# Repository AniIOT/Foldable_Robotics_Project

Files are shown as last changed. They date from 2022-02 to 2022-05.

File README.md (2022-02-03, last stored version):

# Foldable_Robotics_Project

# Add all documents to the appropriate sub-folders in Foldable_Robotics_Project\01_Documents\
# e.g. Research papers will be added in Foldable_Robotics_Project\Documents\02_Research_Papers\

# Add all code files in sub-folders titled with your name in Foldable_Robotics_Project\04_Software\
# e.g. xyz should put their code in Foldable_Robotics_Project\04_Software\##_xyz\

# Final merged code will be kept in Foldable_Robotics_Project\04_Software\04_Release\

# Add all electronic hardware related files in the appropriate sub-folders in Foldable_Robotics_Project\03_Hardware\
# e.g. Component list for Power supply will be in Foldable_Robotics_Project\03_Hardware\01_Components\##_Power_Supply\##_Components\

# Final electronic hardware gerber files will be added in Foldable_Robotics_Project\03_Hardware\03_Release\

# Add all mechanical related files in Foldable_Robotics_Project\02_Mechanical\
# e.g. Chasis CAD files will be in Foldable_Robotics_Project\02_Mechanical\##_Chasis\##_CAD\

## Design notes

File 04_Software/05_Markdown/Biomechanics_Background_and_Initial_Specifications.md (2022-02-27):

## Biomechanics Background and Initial Specifications
### Bryan Carlton1, Aniruddha Anand Damle1, Anson Kwan1, Jacob Yoshitake1
### Team 2: Swimming
### 1Ira A. Fulton Schools of Engineering

### I. Bio Inspiration

The organism that we will draw inspiration from for our research question and system are eels.
Eels exhibit a form of undulatory motion called 
anguilliform locomotion which propagates
waves along their spines [1]. The five most
relevant sources about eels and fish based
undulatory motion are as follows:

I. Hydrodynamics of undulatory
propulsion [1]*
II. Muscles, elastic energy, and the
dynamics of body stiffness in swimming
eels [2]*
III. The hydrodynamics of Eel Swimming
[3]
IV. The hydrodynamics of eel swimming II.
effect of swimming speed [4]*
V. Interactions between internal forces,
body stiffness, and fluid environment in
a neuromechanical model of lamprey
swimming [5]

Of these sources, we will discuss I, II, and IV
since they are the most relevant to our research
question.

Hydrodynamics of undulatory propulsion
discusses the history of existing work conducted
on different forms of undulating locomotion and
propulsion [1]. This is particularly helpful for
our research question because it provides
context and basis of knowledge as we start to
explore anguilliform locomotion. Additionally,
from this paper, we are able to extract critical
information about the gait cycle and time
duration of a single oscillation for eels.
Muscles, elastic energy, and the dynamics of
body stiffness in swimming eels analyzes the
kinematic and dynamic properties of eels to
derive generalized values regarding muscle
activation, work, and stiffness along the body of
eels [2]. This research is pertinent to our
research discussion because it gives us
information regarding how to link kinematic
properties of eels to the foldable system that we
are interested in developing. The most relevant
values include the weight, length, and body
cross sectional area. These values are important
to deriving the linear velocity of eels as well as
provide a method of comparing these elements
of our device against an eel.
The hydrodynamics of eel swimming II. Effect of
swimming speed discusses the kinematics and
hydrodynamics of eels but goes into further
detail regarding dynamic conditions that eels
swim under [4]. Through the method of using
two synchronized high speed cameras, the
researchers were able to calculate frequency,
wave speed, velocities of the system, and jet
speeds produced by the eels [2]. This
information is valuable to us because it allows
us to approximate the linear velocity of eels as
well as the power needed to sustain this form of
locomotion. We are then able to specify the
requirements needed for a servo motor to power
our system.

### II. Other bio-inspired robots

Although the team has already decided on an eel
inspired design, it is also important to look at
other similar designs and other sources of
biological sources. Below are five different
sources that detail different bio-inspired robots.
I. Kinematic Evaluation of a Series of Soft
Actuators in Designing and Eel-inspired
Robot [6]*
II. How the Body Contributes to The Wake
in Undulatory Fish Swimming: Flow
Fields of a Swimming Eel [7]*
III. Thrust generation during Steady
Swimming and Acceleration from Rest
in Anguilliform Swimmers [8]
IV. Development and Motion Control of
Biomimetic Underwater Robots: A
Survey [9]
V. Flow patterns of Larval fish: Undulatory
Swimming in the Intermediate Flow
Regime [10]*
Kinematic Evaluation of a Series of Soft
Actuators in Designing and Eel-inspired Robot
This paper discusses the motion generated
through soft actuators in an eel inspired robot
[6]. Despite this being a soft robot, it provides an
in depth analysis and data on the locomotion of
an eel like robot design. As well this paper
provides information on the manufacturing of
their actuator which can guide the team's design.
How the Body Contributes to The Wake in
Undulatory Fish Swimming: Flow Fields of a
Swimming Eel
This paper discusses the body mechanics, and
how that affects the thrust of the robot [7]. This
paper provides the kinematics of an eel like
robot. It also provides helpful analysis of the
undulatory movement that eels and similar fish
use to move through water
Flow patterns of Larval fish: Undulatory
Swimming in the Intermediate Flow Regime
This paper focuses on fish larvae designs, and
the forces between the body of the larvae and the
water [10]. This paper provides helpful force
analysis between water and submerged
undulatory robots. Having these force
interactions helps the team understand how the
water affects movement and stabilization of the
robot system.

### III. Table

| Parameter | Unit | Value Range | Reference |
| Length | m | .024-.033| [2] |
| Weight | kg | 0.037-0.057 | [2] |
| Frequency | Hz | 1.3 +/- 0.10 | [4] |
| Wave Speed | L/s | 0.39 +/- 0.02 | [4] | 
| Slip | L/L | 0.784 +/-0.002 | [4] | 
| Max Area | 𝑚2 | 0.0001018 | [2] | 
| Gait Time | s | 0.26 | [1] | 

### IV. Other Assumptions

Using the data that was found in Table 1, we can
now calculate the velocity and energy consumed
for anguilliform motion. The slip ratio is defined
as the swimming speed of the body (U) over the
wave speed (V).
𝑆𝑙𝑖𝑝 = 𝑈 (1)
𝑉
From equation 1, we were able to calculate the
body speed to be 0.3058 or . In order to find 𝐿
𝑠
the linear speed, we first had to convert the flow
rate to and got a value of 𝑚3
𝑠 3. 058 × 10−4
. Then using the volumetric flow equation: 𝑚3
𝑠
𝑄 = 𝐴 𝑣 (2)
where Q is the volumetric flow, A is the cross
sectional area, and v is the linear velocity. Using
equation 2, we get a linear velocity of 3.003 . 𝑚
𝑠
From this we can now deduce the approximate
energy and power used during the gait cycle.
Using the kinetic energy formula:
𝐾𝐸 = 1 (3)
2 𝑚𝑣2
Where KE is the kinetic energy, m is the mass,
and v is the velocity. We calculated the kinetic
energy as 0.213 Joules. With this we can now
calculate the approximate power consumption of
the gait since we know both the energy and
duration of the gait cycle. Using the power
equation:
𝑃 = 𝑊 (4)
Δ𝑡
where P is power, W is work or energy, and Δ𝑡 is
the change in time, we are able to calculate the
power of a single gait phase of anguilliform
locomotion is 0.819 W.

### V. Figures



Figure 1. Four main categories of fish
undulatory motion. The top figures denote the
phases of a single gait phase and the lower
visualize the midline movement of each motion
[1].



Figure 2. Flow of water generated from eel
motion. Red represents clockwise motion and
blue represents counter clockwise flow [3].

### VI. Engineering Representation



Figure 3. Engineering representation of
proposed system

As seen in Fig 3 the proposed system will
consist of twelve rigid links connected through
eleven joints which will be acting as the
torsional spring in the system. All the links will
be represented with their own respective masses
so in order to properly model the dynamics of
this system, inertias will need to be included for
all twelve links. The main actuator for this
system will be a servo input on the first link
(farthest left on Fig 3). This servo will be run
using position control so that we can tune and
control the maximum and minimum position of
the output shaft.

### VII. Discussion

#### Discuss / defend your rationale for the size animal you selected.
We selected the eel as inspiration for our
research question because anguilliform
locomotion is one of the few undulatory motions
that only requires a singular input for the entire
system. Traditional fish locomotion has multiple
fins in conjunction with an oscillatory motion.
This would require additional pieces and
increased complexity in order to create an
aquatic robot. By gaining inspiration from eels
and understanding how to precisely tune a
segmented spine, it is possible to create
locomotion through a single motorized actuator.
This would greatly reduce the cost and
complexity of the system and allow us the
flexibility to replicate or draw inspiration from
anguilliform locomotion by simply tuning the
joint stiffness.

#### Find a motor and battery that can supply the mechanical power needs obtained above.
From section IV, we calculated that the total
power of the gait cycle is 0.819 Watts. Using
this and the weight of an eel from Table 1, we
calculated a power/weight ratio of 16.38 W/kg.
Using this information, we selected two
perspective servo motors for our system. The
first choice is the SG90 Micro Servo Motor[11]
due to its low cost, light weight and relatively
high power output. However, it does not appear
to be waterproof, so additional measures will
need to be taken to ensure that it does not
succumb to water damage. On the other end, the
WEISE DS3218 Servo Motor[12] is heavier, but
has much higher power output and is
waterproof. Though it is more expensive and
heavier, the waterproofing is much appreciated
and the higher torque allows the system more
power to operate in the water. We will purchase
the SG90 initially, and if the robot needs more
torque or there are problems with water damage,
the DS3218 will be purchased as a replacement.
For a battery, a Blomiky 6V 2200mAh
battery[13] will be able to operate either of the
servos and meet power requirements. This will
be encased in a waterproof housing along with
the microcontroller to reduce chance of water
damage.

### VIII. Bibliography
#### [1] G. V. Lauder and E. D. Tytell, “Hydrodynamics of undulatory propulsion,” Fish Physiology, pp. 425–468, 2005.
#### [2] J. Long, “Muscles, elastic energy, and the dynamics of body stiffness in swimming eels,” American Zoologist, vol. 38, no. 4, pp. 771–792, 1998.
#### [3] E. D. Tytell and G. V. Lauder, “The hydrodynamics of Eel Swimming,” Journal of Experimental Biology, vol. 207, no. 11, pp. 1825–1841, 2004.
#### [4] E. D. Tytell, “The hydrodynamics of EEL swimming II. effect of swimming speed,” Journal of Experimental Biology, vol. 207, no. 19, pp. 3265–3279, 2004.
#### [5] E. D. Tytell, C.-Y. Hsu, T. L. Williams, A. H. Cohen, and L. J. Fauci, “Interactions between internal forces, body stiffness, and fluid environment in a neuromechanical model of lamprey swimming,” Proceedings of the National Academy of Sciences, vol. 107, no. 46, pp. 19832–19837, 2010.
#### [6] D. Q. Nguyen and V. A. Ho, “Kinematic Evaluation of a Series of Soft Actuators in Designing and Eel-inspired Robot.” International Symposium, Honolulu, 12-Jan-2020.
#### [7]K. T. Du Clos and J. O. Dabiri, “Thrust generation during steady swimming and acceleration from rest in anguilliform swimmers.” The Company of Biologists Ltd, 2019.
#### [8] R. Wang and Y. Wang, “Development and Motion Control of Biomimetic Underwater Robots: A Survey.” Carleton University.
#### [9]U. K. Müller and J. Smit, “How the body contributes to the wake in undulatory fish swimming.” University of Groningen, 2001. 
#### [10] U. K. Müller and J. van den Boogaart and Johan, “Flow patterns of larval fish: undulatory swimming in the intermediate flow regime.” The Company of Biologists, 2008.
#### [11] “2Pack SG90 Micro Servo Motor Mini Servo SG90 9g Servo Kit for RC Helicopter Airplane Car Boat Robot Arm/Hand/Walking/Servo Door Lock Control with Cable,” Amazon. [Online]. Available: https://www.amazon.com/Sipytoph-Helicopter-Airplane-Walking-Control/dp/B09185SC1W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. [Accessed: 13-Feb-2022].
#### [12] “Blomiky 6V 2200mAh Ni-MH 5 AA Rechargeable Battery Pack with SM-2P Black 2 Pin Connector Plug and USB Charger Cable for RC Truck Cars Vehicles 6V NiMh,” Amazon. [Online]. Available: https://www.amazon.com/Blomiky-2200mAh-Rechargeable-Battery-Vehicles/dp/B07PY8R3F4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. [Accessed: 13-Feb-2022].
#### [13] “WEISE DS3218 Control Angle 180 High Torque Update Servo 20KG Full Metal Gear Digital Servo Baja Servo Waterproof Servo Mechanical arm Fittings RC Baja Cars,” Amazon. [Online]. Available: https://www.amazon.com/WEISE-Control-Waterproof-Mechanical-Fittings/dp/B073M3X86S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. [Accessed: 13-Feb-2022].

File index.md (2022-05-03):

---
title: Foldable Robotics Project
---

# Project Title: Tuned constrained beam inspired by anguilliform locomotion

**Team 2**

| Name | Email | Phone |
| --- | --- | --- |
| Aniruddha Anand Damle | adamle5@asu.edu | (602) 813-7594  |
| Jacob Yoshitake | jyoshita@asu.edu | (858) 231-4114  |
| Anson Kwan | akwan2@asu.edu | (626) 512-2444  |
| Bryan Carlton | bhcarlto@asu.edu | (480)-677-8602  |

## Research Question 

* [Develop A Research Question](/04_Software/05_Markdown/Develop_A_Research_Question.md)

* [Biomechanics Background and Initial Specifications](/04_Software/05_Markdown//Biomechanics_Background_and_Initial_Specifications.md)

* [System Kinematics](/04_Software/05_Markdown/SystemKinematics.md)

* [Presentation 1](/04_Software/05_Markdown/Presentation_1.md)

* [System Dynamics](/04_Software/05_Markdown/SystemDynamics.md)

* [Presentation 2](/04_Software/05_Markdown/Presentation_2.md)

* [Design Optimization, Experiment Design, Data Collection, and Analysis](/04_Software/05_Markdown/Design_Optimization_Experiment_Design_Data_Collection_and_Analysis.md)

* [Presentation 3](/04_Software/05_Markdown/Presentation_3.md)

* [Manufacturing](/04_Software/05_Markdown/Manufacturing.md)

* [Data](/04_Software/05_Markdown/Data.md)

* [Gallery](/04_Software/05_Markdown/Gallery.md)

## Background
We wanted to know how a length-constrained segmented beam with a compliant tail could propagate a sinusoidal wave to produce anguilliform locomotion in this project. Our team members come from various experiences and provide a variety of perspectives to the project. This project aims to replicate the motion of an eel's tail and enhance the velocity of a similar robot that has already been built. We also want to reduce production costs by employing foldable methods.



## Results
 - This project has helped  to further research into aquatic foldable robots
 - It also helped to contribute to the understanding of undulating aquatic animals
 - To further progress our research, main things to improve would be to
   - Properly scale up the prototype
   - Test it in a free swim
   - Continue research on the gates of undulating aquatic animals
 - The outputs of our parameter optimization are as follows
   - Segment Volume - length=27.6mm height=10mm
   - Tail Length = 10mm
   - Sweep Frequency - 2.13Hz 
   - Constraint Link Length - 151.8 mm
  


## Conclusions and Future Work
In the future, there are a couple of improvements that we would like to make.  The first would be to see if it is possible to convert the stiff spine into a foldable part.  The current design uses a 3D printed spine to provide a rigid structure that the two pivot points and the motor mounts to.  To replace this, a future team could look into creating a laminate structure that doubles up the current tail thickness to obtain an ideal thickness.  Second, making the system free-floating and designing it around the weight of the actuator would change how the system was optimized.  The current optimization is focused on just the tail without the weight of the motor or any support structure, and the weight of the actuator is too much for the current design to propel.  Optimizing the tail with the weight of the motor would definitely change the dimensions of the design.  Finally, the shape of the tail could be optimized.  For our system, we kept the tail a rectangular shape to make simulation much easier.  However, a more optimized tail might be able to handle producing more thrust that could be used for propulsion.

## References
[1] G. V. Lauder and E. D. Tytell, “Hydrodynamics of undulatory propulsion,” Fish Physiology, pp. 425–468, 2005.<br>
[2] J. Long, “Muscles, elastic energy, and the dynamics of body stiffness in swimming eels,” American Zoologist, vol. 38, no. 4, pp. 771–792, 1998. <br>
[3] E. D. Tytell and G. V. Lauder, “The hydrodynamics of Eel Swimming,” Journal of Experimental Biology, vol. 207, no. 11, pp. 1825–1841, 2004. <br>
[4] E. D. Tytell, “The hydrodynamics of EEL swimming II. effect of swimming speed,” Journal of Experimental Biology, vol. 207, no. 19, pp. 3265–3279, 2004.<br> 
[5] E. D. Tytell, C.-Y. Hsu, T. L. Williams, A. H. Cohen, and L. J. Fauci, “Interactions between internal forces, body stiffness, and fluid environment in a neuromechanical model of lamprey swimming,” Proceedings of the National Academy of Sciences, vol. 107, no. 46, pp. 19832–19837, 2010. <br>
[6] D. Q. Nguyen and V. A. Ho, “Kinematic Evaluation of a Series of Soft Actuators in Designing and Eel-inspired Robot.” International Symposium, Honolulu, 12-Jan-2020.<br>
[7]K. T. Du Clos and J. O. Dabiri, “Thrust generation during steady swimming and acceleration from rest in anguilliform swimmers.” The Company of Biologists Ltd, 2019.

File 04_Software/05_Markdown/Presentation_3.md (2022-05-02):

# Presentation 3:

<iframe width="560" height="315" src="https://www.youtube.com/embed/5slSRJoQ57w" title="YouTube video player" frameborder="0" allow="accelerometer; autoplay; clipboard-write; encrypted-media; gyroscope; picture-in-picture" allowfullscreen></iframe>

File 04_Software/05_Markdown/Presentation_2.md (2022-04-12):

# Presentation: 

<iframe width="560" height="315" src="https://www.youtube.com/embed/j1TpFOJFzOI" title="YouTube video player" frameborder="0" allow="accelerometer; autoplay; clipboard-write; encrypted-media; gyroscope; picture-in-picture" allowfullscreen></iframe>

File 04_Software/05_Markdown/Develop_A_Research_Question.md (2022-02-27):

# EGR 557 Foldable Robotics
## Develop A Research Question
## Team 2
### Bryan Carlton1, Aniruddha Anand Damle1, Anson Kwan1, Jacob Yoshitake1
### 1Ira A. Fulton Schools of Engineering

### I. Question
How can a length-constrained segmented beam with a compliant tail propagate a sinusoidal wave to produce anguilliform locomotion?

### II. Tractability
In order to make this project tractable within the time frame of 15 weeks, we will be focusing on tuning our segmented beam to produce motion inspired by anguilliform locomotion or ‘eel-like’ swimming. Additionally, we will be focusing on only trying to tune one position for the segmented beam. This means that we will be only focusing on optimizing the joint stiffness for the mechanism for only one configuration of the system. For the purposes of this project, we will be starting in an ‘S’ configuration and try to flip the peaks of the stable position through a simple input of a servo motor. This will greatly improve the scope of this research because it defines the goal of the research as producing this configuration as opposed to finding the optimal configuration to produce this locomotion. By focusing our research on anguilliform locomotion and defining the configuration that we will use, the scope of the research will produce successful results for this semester.

### III. Novelty
For the purposes of understanding the various research spaces that anguilliform locomotion-based robots exist, we used keywords such as ‘anguilliform locomotion’, ‘undulatory motion’, ‘soft robotics’, ‘laminate’, and ‘eel inspired’. From these keywords, we were able to get an understanding of the existing research being conducted on anguilliform-inspired robots within the foldable robotics field.
From these keywords, the most cited source was “A Geometric Approach to Anguilliform Locomotion: Modeling of an Underwater Eel Robot” [1]. This paper discusses the kinematics and simplification of anguilliform locomotion into rigid body segments and defined points of rotation [1]. This paper primarily focuses on using rigid bodies and actuation at every link. Unlike this paper, our research question will be focusing on creating undulations in the body of our system through only a single actuation and tuning our system to propagate the motion. The next most cited source was “Bio-inspired aquatic robotics by untethered piezohydroelastic actuation’ [2]. This journal entry discussed the tuning and utilization of piezoelectric laminates to produce the sinusoidal locomotion that characterizes many underwater movements [2]. Both this paper and our research questions discuss the concepts of single actuated, tunable laminate structures, but this paper focuses on carangiform locomotion which is exhibited in fish. Additionally, this paper uses
the laminate structure as the form of actuation, while our question focuses on a method of
propagating a tuned laminate structure that produces anguilliform-like locomotion. The third most
relevant and cited source was “AmphiBot I: An amphibious snake-like robot” [3]. The core
concept of this paper revolves around a wheeled multi-actuated spine that can either traverse land
or water through snake-like or eel-like locomotion [3]. This paper represents how anguilliform
locomotion can be accomplished using traditional actuators and linkages. Our question differs
entirely from this paper because our objective is to produce this kind of movement using only a
singular actuator and a precisely tuned mechanical system. Lastly, the other paper that was most
cited for these keywords were “Body wave generation for anguilliform locomotion using a fiberreinforced
soft fluidic elastomer actuator array toward the development of the EEL-inspired
Underwater Soft Robot” [4]. This journal article focused on utilizing bellows-based actuators to
inflate faces of a soft spine in order to create the curvatures present in eels to create a simplified
model and robot [4]. While both this research paper and our question revolve around simplifying
the traditionally complex systems that generate anguilliform locomotion, this is achieved in
different ways. The goal of our research is to use a single traditional actuator, such as a servo, to
produce this locomotion, while this paper focuses on using multiple pneumatic bellows to deform
the spine.

### IV. Interesting
With the development of newer and faster manufacturing methods, as well as various materials
such as ionic polymer-metal composites (IPMCs), Shape memory alloys (SMAs), and
magnetostrictive thin films, the development of bioinspired soft-robot locomotion has received a
lot of attention and has recently been the topic of discussion between the scientific communities.
The scientific and engineering communities have expressed a strong interest in applying biological
underwater locomotion to marine robots in order to improve performance in various marine
missions such as search and rescue, naval intelligence, and surveillance and reconnaissance. The
motivation for eel-like biometric locomotion ranges from underwater sensing and exploration for
long-term ecological sustainability to drug delivery and disease screening in medicine.

### V. Open-Ended
In addition to our research question, there are a slew of other questions that could be asked. From
the way that we defined and structured our research question, our primary focus is anguiliform
locomotion and tuning for a single starting configuration. This means that there is an opportunity
to conduct more research on optimizing the initial configuration for anguilliform locomotion or
adapting the mechanism for different forms of aquatic locomotion as well as terrestrial locomotion.
Additionally, even within the scope of our question, there is potential to do a deeper look into
optimizing a tail or compliant attachment to propagate the motion produced from the mechanism.
Our research question's goal is to start looking into the possibilities for this mechanism, which is
just a starting point for a variety of applications and dynamics that can be used with this system.

### VI. Modularity
Our question can be applied to a wide range of research topics such as biomimicry, laminate
robotics, aquatic propulsion, and unmanned surface vehicles (USV). Because we are focusing on
inspired locomotion from eels, biologists can compare locomotion behaviors of eels with the
device we develop. Through that research, it is possible for new or additional correlations could
be drawn from this comparison. Research in laminate robotics can further develop this mechanism
to be applied to multiple different environments or be use the data from tuning joint stiffness with
the experimental material for future mechanisms. For researchers interested in aquatic propulsion,
studies could be conducted in simulating and testing the fluid dynamics of the mechanism in
relation to correlating fluid environments that produce the best results. USV are an up-and-coming
field of research that focus mainly on producing devices and mechanisms that can be controlled
remotely in variable viscous fluids and land. Through our research, future work can be done on
developing and controlling this mechanism so that it can be applied to this field. There may be
other applications of our research to other topics, but these three are the most prominent that we
could recognize.

### VII. Team Fit
Our team members have a variety of interests and abilities that will be necessary to this research.
Anson Kwan is currently conducting research on simulating and analyzing soft beams to produce
anguilliform locomotion and has an interest in crossing over the concept of singular actuation to
create complex motion into laminate systems. He has experience with python-based simulation as
well as using optimization algorithms such as SciPy and CMA-ES to solve and fit complex
dynamic systems. Through this research question, he hopes to learn more about laminate structures
and how they apply to anguilliform locomotion and how joint design in laminate design affects
stiffness and compliance
Jacob Yoshitake has a variety of skills based in 3D modeling and manufacturing. His extensive
experience with SolidWorks will allow the team to be able to create 3D models of the robot at a
rapid pace, as well as simulate it though either SolidWorks or ANSYS. He also understands a
wide variety of manufacturing techniques (3D printing, laser cutting, welding, milling, lathe, etc.)
as well as a wealth of experience manufacturing mechanisms that will be paramount to being able
to produce a working robot. Though his interests are mostly in aerospace, the research into
propulsion of an aquatic robot also interests him.
Bryan Carlton is currently working on a research project in which he is working on another
bioinspired design. With this research question, he hopes to learn how to apply biological concepts
to robotics in order to provide simpler, effective solutions whether it be in exoskeleton
development or an underwater vehicle. This project allows Bryan to research simpler solutions for
underwater locomotion while learning new robotic methods. He currently has experience with
CAD softwares such as Fusion 360 and Solidworks. He has also worked with electrical design
software Cadence. Bryan also has experience in programming languages such as C/C++,
MATLAB/Simulink, and a little bit of Python.
Aniruddha Anand Damle is interested in creating a low-cost mechanism that can be used for
terrestrial robots. He has a strong background in embedded systems, machine learning, and
communication protocols, allowing us to quickly develop functional prototypes. He's also worked
with 3D modeling and production techniques like 3D printing, laser cutting, and lathes. He has
previously worked on multi-layered PCB design and development, as well as various ARM-based
platforms. Although his interest is in Swarm Robotics, he hopes to develop a low-cost muscle
design that can be used to build an origami-inspired quadruped robot with this research question.

### VIII. Topic Fit
For this research to be successful, it will be utilizing the techniques of analysis of geometric
kinematics, dynamics, and laminate manufacturing processes for our device that will be taught
over this course. In order to determine the joint stiffnesses of the segmented beam, we will need
to conduct experimental data and fit the simulated data to it. To achieve this, we will have to solve
for the kinematics of the system as well as simulate the dynamics of the model to find the joint
characteristics. Additionally, in order to find the optimal joint stiffness to match our desired
dynamics and starting configuration, we will need to solve for the dynamics of the system which
is a major topic of this course. Finally, the segmented beam will be manufactured using foldable
robotics processes. Foldable techniques are critical to answering this question because it allows
for the flexibility of easily experimenting with a number of joints and links using inexpensive
materials and low manufacturing time. Since varying the stiffness of joints is just a relationship to
how much material is removed between the joints and there is a multitude of configurations for
how to design the joints, foldable techniques are an ideal solution to prototype our device.

### IX. Bibliography
#### [1] K. A. Melsaac and J. P. Ostrowski, “A geometric approach to anguilliform locomotion:
#### Modelling of an underwater Eel Robot,” Proceedings 1999 IEEE International Conference on
#### Robotics and Automation (Cat. No.99CH36288C), pp. 2843–2848, May 1999.
#### [2] L. Cen and A. Erturk, “Bio-inspired Aquatic Robotics by untethered piezohydroelastic
#### actuation,” Bioinspiration & Biomimetics, vol. 8, no. 1, p. 016006, 2013.
#### [3] A. Crespi, A. Badertscher, A. Guignard, and A. J. Ijspeert, “Amphibot I: An amphibious
#### snake-like robot,” Robotics and Autonomous Systems, vol. 50, no. 4, pp. 163–175, 2005.
#### [4] H. Feng, Y. Sun, P. A. Todd, and H. P. Lee, “Body wave generation for anguilliform
#### locomotion using a fiber-reinforced soft fluidic elastomer actuator array toward the development
#### of the EEL-inspired Underwater Soft Robot,” Soft Robotics, vol. 7, no. 2, pp. 233–250, 2020.

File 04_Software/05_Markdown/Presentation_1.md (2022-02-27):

# Presentation:
<iframe width="560" height="315" src="https://www.youtube.com/embed/J2_oT60I6jE" title="YouTube video player" frameborder="0" allow="accelerometer; autoplay; clipboard-write; encrypted-media; gyroscope; picture-in-picture" allowfullscreen></iframe>

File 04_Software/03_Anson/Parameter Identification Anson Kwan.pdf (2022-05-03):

4/12/22, 9:33 PM | Parameter Identification Anson Kwan
file:///C:/Users/aakwa/Desktop/Parameter Identification Anson Kwan.html | 1/9

# Goal of Experiment

The goal of my experiment is to run a dynamic test of the decided joint material of polyethelyene sheet. From this experiment we hope to fit the data for the damping and stiffness constant.

# Process and Procedure

### Process

In order to isolate the joint properties, I manufactured a 2 link, 5-layer laminate structure with 0.002" polyester film as the flexible layer and 6 layer cardstock as the rigid material. I then conducted a

### dynamic test by constraining one of the links vertically between two plates and pulled

unconstrained link to the side, released and let it come to rest. I recorded this experiment with my phone so that I could import the data into tracker, track the position of the blue dot at the end of my segment, and record the position data over time. This data was then imported into python so that I could fit the data to a simulated experiment.

The assumptions I made for this experiment is that the system is exactly vertical. Since I am in a configuration that is meant to negate gravity, but if there was any warping or if the links were not exactly vertical, some forces due to gravity would have an effect. Additionally, I am treating the rigid segments as rigid bodies have no flexure for my model.

### Pictures of Experimental Setup

Set up of experiment from above. One link is constrained allowing only one segment to move.

Side profile of experimental set up. A small blue ball was added to the end of the link to track the motion of the segment as it oscilatted.

### Video

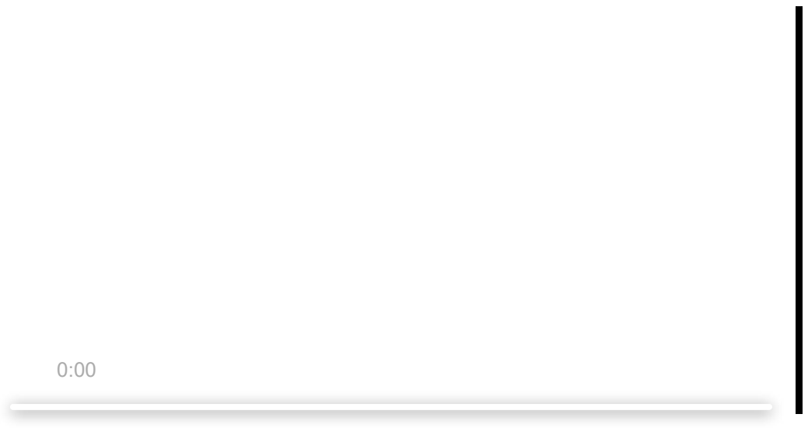
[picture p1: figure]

file:///C:/Users/aakwa/Desktop/Parameter Identification Anson Kwan.html | 2/9

Video of experiment that was used for tracker.

# Model Fitting

The model I used to fit for this experiment was a single link that had a torsional spring and damping force applied to the point of rotation. The reason that the model was built like this is because only one link in the experiment had free motion and the cause of motion was the felxure joint.

The optimization method used for my assignment was the scipy.optimize.minimze function. The reason that this method was used was because I was trying to tune the b and k values of the model to best fit the experimental data. Since there was no relationship between these variables, I went with the fastest method of fitting the data. For the purposes of this assignment, the script will not run the fitting to decrease the amount of outputs but the values of the damping and spring constant are calculated from the the optimization.

# Importing Libraries

### Adding libaries to build dynamic model and fitting algorithms

In [1]:
%matplotlib inline

In [2]:
import pynamics
from pynamics.frame import Frame
from pynamics.variable_types import Differentiable,Constant from pynamics.system import System
from pynamics.body import Body
from pynamics.dyadic import Dyadic
from pynamics.output import Output,PointsOutput from pynamics.output_points_3d import PointsOutput3D from pynamics.particle import Particle
import pynamics.integration

file:///C:/Users/aakwa/Desktop/Parameter Identification Anson Kwan.html | 3/9

# Running Optimization and Importing Data

Setting variable to True to run fit or false to just run a single simulation. Importing the xlsx file of exerimental data and plot the data. The data was cut at two seconds to focus on the dynamics of the system and to optimize the simulation time so that it would run faster.

Text(0, 0.5, 'Position (mm)')

import numpy
import matplotlib.pyplot as plt plt.ion()
from math import pi,sin
import sympy
from sympy import sqrt
import math
import logging
import pynamics.integration import pynamics.system
import numpy.random
import scipy.interpolate
import scipy.optimize
import cma
import pandas as pd
import idealab_tools.units

system = System()
pynamics.set_system(__name__,system)

In [3]:
#Run SciPy Opitmization regession fit

run_fit = False

#import test data and convert to numPy arrays data = pd.read_excel(r'damping data_cut.xlsx') df = data.to_numpy()

length = df.shape[0]

fig = plt.figure()
plt.plot(df[:,1],df[:,3])
plt.title('Experimental Data From Tracker') plt.xlabel('Time (s)')
plt.ylabel('Position (mm)')

Out[3]:

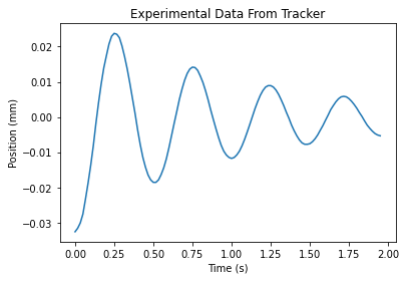
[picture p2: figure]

file:///C:/Users/aakwa/Desktop/Parameter Identification Anson Kwan.html | 4/9

# Constants of Model

### Adding dimensions and interias of segment based off of physical laminate structure. Link dimensions were 50mm x 30 mm x 1 mm. Mass of the tracker was 0.0588 grams and mass of the segment was 1 gram. These values were gotten from teammates from their parameterization

documents.

In [4]:
#Parameterization

#Defining Constants of System seg_len = 0.050 #segment mass seg_mass = 0.001 #segment mass seg_h = 0.040 #segment height seg_th = 0.001

#Set segment lengths

lA = Constant(seg_len,'lA',system) lB = Constant(seg_len,'lB',system)

#Set masses

mA = Constant(seg_mass,'mA',system)
mB = Constant(seg_mass,'mB',system)
mM = Constant(.001/17,'mM',system) #17 trackers was 1 gram so divided to find mass of t

g = Constant(9.81,'g',system)
b = Constant(2.14176688e-06,'b',system) #values generated fro sciPy.minimize
k = Constant(1.59953557e-04,'k',system) #values generated fro sciPy.minimize
area = Constant(seg_len*seg_h,'area',system)
rho = Constant(1.059,'rho',system)

Ixx = Constant((1/12*seg_mass*(seg_h**2 + seg_th**2)),'Ixx',system)
Iyy = Constant((1/12*seg_mass*(seg_h**2 + seg_len**2)),'Iyy',system) Izz = Constant((1/12*seg_mass*(seg_len**2 + seg_th**2)),'Izz',system)

#Define derivatives of frames

qA,qA_d,qA_dd = Differentiable('qA',system)

#set initial conditions

file:///C:/Users/aakwa/Desktop/Parameter Identification Anson Kwan.html | 5/9

# Kinematics of Model

Adding kinematics of syste. Adding the body of the link and a particle mass of the tracker to the end of the segment.

# Adding Force

Forces were added to the model. Gravity, Aerodynamic against flat plate, spring force and damping force.

initialvalues = {}
initialvalues[qA]=-41*pi/180 #Initial state of experiment initialvalues[qA_d]=0*pi/180

statevariables = system.get_state_variables()
ini = [initialvalues[item] for item in statevariables]

#Set simulation run time

tinitial = 0
tfinal = df[length-1,1] #time of simulation to match time of experiment fps = length/tfinal
tstep = 1/fps
t = numpy.r_[tinitial:tfinal:tstep]

In [5]:
#Kinematics

#Frames

N = Frame('N',system)
A = Frame('A',system)

system.set_newtonian(N)

A.rotate_fixed_axis(N,[0,0,1],qA,system)

#Vectors

pNA=0*N.x
pAB=pNA+lA*A.x

#Centers of Mass

pAcm=pNA+lA/2*A.x
pMcm=pNA+lA*A.x

#Angular Velocity

wNA = N.get_w_to(A)

#Velocity of Center of Mass vA=pAcm.time_derivative()

#Interia and Bodys

IA = Dyadic.build(A,Ixx,Iyy,Izz)

BodyA = Body('BodyA',A,pAcm,mA,IA,system)
BodyM = Particle(pMcm,mM,'ParticleM',system) #Mass of blue dot tracker

file:///C:/Users/aakwa/Desktop/Parameter Identification Anson Kwan.html | 6/9

<pynamics.force.Force at 0x260b29ca250>

# Building Model

Solve for the equations of motion and run the opitimization algorithm if run_fit was set to true

In [6]:
#Forces

#Gravity

system.addforcegravity(-g*N.z)

#Aerodynamic Forces

f_aero_A = rho * vA.length()*(vA.dot(A.y))*area*A.y system.addforce(-f_aero_A,vA)

#Spring Forces

system.add_spring_force1(k, (qA)*N.z, wNA)

#Damping Force

system.addforce(-b*wNA, wNA)

# Out[6]: In [7]:

#Constraints and Plots

f,ma = system.getdynamics();

tol = 1e-12
points = [pNA,pAB]

def run_sim(args):
constants = dict([(key,value) for key,value in zip(unknown_constants,args)]) states=pynamics.integration.integrate(func1,ini,t,rtol=tol,atol=tol,hmin=tol, args= return states

def calc_error(args):
states_guess = run_sim(args)
points_output = PointsOutput(points,system) y_guess = points_output.calc(states_guess,t) error = df[:,3] - y_guess[:,1,1]
error **=2
error = error.sum()
return error

pynamics.system.logger.setLevel(logging.ERROR)

if run_fit:

unknown_constants = [b,k]

known_constants = list(set(system.constant_values.keys())-set(unknown_constants)) known_constants = dict([(key,system.constant_values[key]) for key in known_constant

func1,lambda1 = system.state_space_post_invert(f,ma,return_lambda = True,constants

guess = [3e-6,2.17e-4]

file:///C:/Users/aakwa/Desktop/Parameter Identification Anson Kwan.html | 7/9

2022-04-12 21:12:24,585 - pynamics.system - INFO - getting dynamic equations

# Plots of Results

Plotting the results of the simulated tip of the simulation against the experimental tip.

pynamics.system.logger.setLevel(logging.ERROR)

sol = scipy.optimize.minimize(calc_error,guess) print(sol.fun)
result = sol.x

error_f = calc_error(result)

In [16]:
if run_fit:
states2 = run_sim(result)
points_output2 = PointsOutput(points,system) y2 = points_output2.calc(states2,t)

fig = plt.figure()
ax1 = plt.subplot(2,1,2)
ax1.plot(t,states2[:,:1])
ax1.legend(['qA'])
ax1.set_title('State Positions') ax1.set_xlabel('Time (s)') ax1.set_ylabel('Position (mm)')

ax2 = plt.subplot(2,1,1)
ax2.plot(t,y2[:,1,1],df[:,1],df[:,3]) ax2.legend(['pBtip_s' ,'pBtip_a']) ax2.set_title('Test vs CMA Tip') ax2.set_xlabel('Time (s)') ax2.set_ylabel('Position (mm)')

fig.tight_layout()

print(result)
print(error_f)

else:

func1 = system.state_space_post_invert(f,ma,return_lambda = False) states=pynamics.integration.integrate(func1,ini,t,rtol=tol,atol=tol,hmin=tol, args=

points_output = PointsOutput(points,system)
y = points_output.calc(states,t)

fig = plt.figure(figsize=(8, 6), dpi=80)

ax1 = plt.subplot(3,1,1)
ax1.plot(t,states[:,:1])
ax1.legend(['qA'])
ax1.set_title('State Positions') ax1.set_xlabel('Time (s)') ax1.set_ylabel('Position (mm)') ax1.set_ylim([-1, 1])

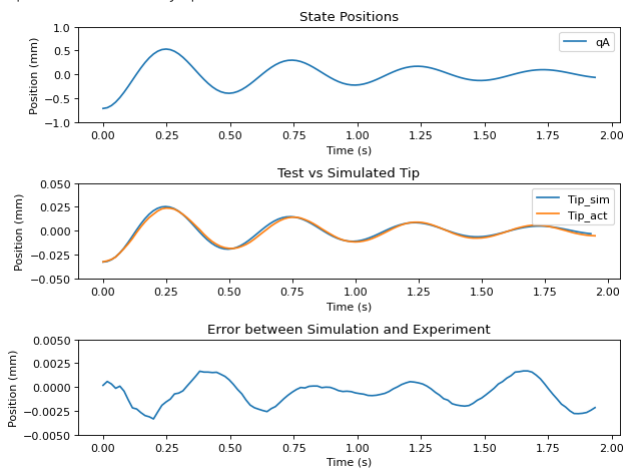
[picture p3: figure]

file:///C:/Users/aakwa/Desktop/Parameter Identification Anson Kwan.html | 8/9

2022-04-12 21:20:01,370 - pynamics.integration - INFO - beginning integration 2022-04-12 21:20:01,550 - pynamics.integration - INFO - finished integration 2022-04-12 21:20:01,559 - pynamics.output - INFO - calculating outputs 2022-04-12 21:20:01,561 - pynamics.output - INFO - done calculating outputs Dapming and Spring Constants Respectivly: [2.14176688e-06 1.59953557e-04] Squared Error from SciPy.Optimize: 0.0002384852610771121

# Discussion

ax2 = plt.subplot(3,1,2)
ax2.plot(t,y[:,1,1],df[:,1],df[:,3]) ax2.legend(['Tip_sim' ,'Tip_act']) ax2.set_title('Test vs Simulated Tip') ax2.set_xlabel('Time (s)') ax2.set_ylabel('Position (mm)') ax2.set_ylim([-.05, 0.05])

ax3 = plt.subplot(3,1,3)
ax3.plot(t,(df[:,3]-y[:,1,1]))
ax3.set_title('Error between Simulation and Experiment') ax3.set_xlabel('Time (s)')
ax3.set_ylabel('Position (mm)')
ax3.set_ylim([-.005, .005])

fig.tight_layout()

print('Dapming and Spring Constants Respectivly: [2.14176688e-06 1.59953557e-04]') print('Squared Error from SciPy.Optimize: 0.0002384852610771121')

file:///C:/Users/aakwa/Desktop/Parameter Identification Anson Kwan.html | 9/9

### 1. The main improvement that could have been done on this experiment was to mount and

constrain the stationary link better. Since the link was just sandwiched, there was still some room for the link to move which would contribute to not perfect motion of the unconstrained link.

1. The rationale behind the model that I used was to simplify the model as much as possible in

### order to get the optimization to run as fast as possible. In order to do this, only the

unconstrained link was modeled and the joint damping and stiffness was modeled on the first point (pNA) of the link. The spring and damping varibles were based off the triple pendulum model that Dr. Aukes provided. Additionally, a point mass was added to the tip of the link (pAB) to represent the mass of the tracker that was attached to the system. Assumptions that I made

### were that the damping and spring constant were independent variables, the rigid laminate

could be approximated as a flat plate, and that the aerodynamic forces were being generalized and applied to the center of mass instead of the entire length of the beam.

1. The method used for fitting the data was the scipy.optimize.minimize() function. The reason that this method was used was because I was trying to select the correct b and k values to

### generate closest simulated tip data as the experimental data. Through

scipy.optimize.minimize(), the algorithm was an uncosntrained minimzation function based off calculating the error after every iteration. This method was used because I had gotten the k and b values close to the data through guess and check and then optimized the constants based off the hand tuned guesses. For this reason, using an unbounded algorithm is acceptable because i have converged the variables close to the desired result.

1. Summed squarred error is 0.000238 between the simulation and experimental data. The data fits very well. The simulation has some slight overdamping and the spring constant is slight too

### high. This can ben seen through the fact that the simulation peak is slightly before the

experiment at 0.25 seconds and is after the experimental peak at 1.75 seconds. This could be due to not exact point masses or link masses. The slight discrepency is due to the interias of the simulated experiment not being exactly the same as the experimental inertias.

### 2. The limit of the model is to to the exact marker and segment dimensions used in the

experiment. Since the polyester film is very soft, the interias and mass have a very large effect on the system. Therefore in order for the model to fit it requires that all the parameters to match the simulation. If those are the same then the model will match any single link pendulum that has gravity applied in the z direction.

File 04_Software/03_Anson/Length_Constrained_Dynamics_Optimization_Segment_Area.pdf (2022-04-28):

4/26/22, 6:33 PM | Length_Constrained_Dynamics_Optimization_Segment_Area
localhost:8888/nbconvert/html/Downloads/Git/Foldable_Robotics_Project/04_Software/03_Anson/Length_Constrained_Dynamics_Optimization_Seg… | 1/12

# Importing Libraries

### Importing libraries for script

# Constants of System

In this block of code we are defining all the constants of our system that we will use for our

### simulation

In [1]:
%matplotlib inline

In [2]:
#Set script to run optimization run_fit = False

In [3]:
import pynamics
from pynamics.frame import Frame
from pynamics.variable_types import Differentiable,Constant,Variable from pynamics.system import System
from pynamics.body import Body
from pynamics.dyadic import Dyadic
from pynamics.output import Output,PointsOutput
from pynamics.output_points_3d import PointsOutput3D
from pynamics.constraint import AccelerationConstraint,KinematicConstraint from pynamics.particle import Particle
import pynamics.integration
import numpy
import matplotlib.pyplot as plt plt.ion()
from math import pi,sin
import sympy
from sympy import sqrt
import math
import logging
import scipy.optimize
import pynamics.integration import pynamics.system
import numpy.random
import scipy.interpolate
import scipy.optimize
import cma
import pandas as pd
import idealab_tools.units
from matplotlib import animation, rc from IPython.display import HTML

system = System()
pynamics.set_system(__name__,system)

In [4]:

localhost:8888/nbconvert/html/Downloads/Git/Foldable_Robotics_Project/04_Software/03_Anson/Length_Constrained_Dynamics_Optimization_Seg… 2/12

#[0.0276 0.01]

#seg = segment, t = tail

seg_l = 0.0276
t_l = 0.0276
seg_h = 0.01
len_factor = 5.5

#Set segment lengths

l = Constant(seg_l,'l',system) #Segment Length, Formula:seg_len
lT = Constant(seg_l,'tail',system) #Tail Length, Formula:tail_len
lP = Constant(seg_l*len_factor,'lP',system) #Constrained length, Forumla:seg_len*constr

#Set masses, 666.7 is density of laminate structure

m = Constant(666.7*seg_l*seg_h*0.001,'m',system) #Segment Mass, Formula:666.7*seg_len*s mT = Constant(666.7*t_l*seg_h*0.001,'mT',system) #Tail Mass, Formula:666.7*tail_len*seg_

b = Constant(2.148e-6,'b',system)
k = Constant(1.599e-4,'k',system)
rho = Constant(998,'rho',system)
area_p = Constant(seg_l*seg_h,'area_p',system) #area of flat plates area_f = Constant(seg_h*0.001,'area_f',system) #area of flat plates

freq = Constant(1,'freq',system) #frequency of head oscilation
amp = Constant(40*pi/180,'amp',system) #maximum pitch angle of servo

Ixx = Constant(1/12*(666.7*seg_l*seg_h*0.001)*(seg_h**2 + 0.001**2),'Ixx',system) #Form Iyy = Constant(1/12*(666.7*seg_l*seg_h*0.001)*(seg_h**2 + seg_l**2),'Iyy',system) #Form Izz = Constant(1/12*(666.7*seg_l*seg_h*0.001)*(seg_l**2 + 0.001**2),'Izz',system) #Form Ixx_T = Constant(1/12*(666.7*t_l*seg_h*0.001)*(seg_h*2 + 0.001**2),'Ixx_T',system) #Form Iyy_T = Constant(1/12*(666.7*t_l*seg_h*0.001)*(seg_h**2 + t_l**2),'Iyy_T',system) #Form Izz_T = Constant(1/12*(666.7*t_l*seg_h*0.001)*(t_l**2 + 0.001**2),'Izz_T',system) #Form

In [5]:
#Set integration tolerance

tol = 1e-12

In [6]:
#Set simulation run time

fps = 30
tinitial = 0
tfinal = 2
tstep = 1/fps
t = numpy.r_[tinitial:tfinal:tstep]

In [7]:
#Define derivatives of frames qA,qA_d,qA_dd = Differentiable('qA',system) qB,qB_d,qB_dd = Differentiable('qB',system) qC,qC_d,qC_dd = Differentiable('qC',system) qD,qD_d,qD_dd = Differentiable('qD',system) qE,qE_d,qE_dd = Differentiable('qE',system) qF,qF_d,qF_dd = Differentiable('qF',system) qT,qT_d,qT_dd = Differentiable('qT',system)

x,x_d,x_dd = Differentiable('x',system) y,y_d,y_dd = Differentiable('y',system)

localhost:8888/nbconvert/html/Downloads/Git/Foldable_Robotics_Project/04_Software/03_Anson/Length_Constrained_Dynamics_Optimization_Seg… 3/12

# Defining Vectors

In this section of code we are defining all the position and center of mass vecotors. Additionally we are calculating angular velocity of each frame and the respective linear velocities at the center of mass. We also build each body of the system in this section.

In [8]:

#set initial conditions

initialvalues = {}
initialvalues[qA]=40*pi/180 initialvalues[qA_d]=0*pi/180 initialvalues[qB]=20*pi/180 initialvalues[qB_d]=0*pi/180 initialvalues[qC]=10*pi/180 initialvalues[qC_d]=0*pi/180 initialvalues[qD]=0*pi/180 initialvalues[qD_d]=0*pi/180 initialvalues[qE]=-10*pi/180 initialvalues[qE_d]=0*pi/180 initialvalues[qF]=-40*pi/180 initialvalues[qF_d]=0*pi/180 initialvalues[qT]=0*pi/180 initialvalues[qT_d]=0*pi/180

initialvalues[x]=0*pi/180
initialvalues[x_d]=0*pi/180 initialvalues[y]=0*pi/180
initialvalues[y_d]=0*pi/180

statevariables = system.get_state_variables()
ini0 = [initialvalues[item] for item in statevariables]

In [9]:
#Frames

N = Frame('N',system)
A = Frame('A',system)
B = Frame('B',system)
C = Frame('C',system)
D = Frame('D',system)
E = Frame('E',system)
F = Frame('F',system)
T = Frame('T',system)

system.set_newtonian(N)

A.rotate_fixed_axis(N,[0,0,1],qA,system) B.rotate_fixed_axis(N,[0,0,1],qB,system) C.rotate_fixed_axis(N,[0,0,1],qC,system) D.rotate_fixed_axis(N,[0,0,1],qD,system) E.rotate_fixed_axis(N,[0,0,1],qE,system) F.rotate_fixed_axis(N,[0,0,1],qF,system) T.rotate_fixed_axis(N,[0,0,1],qT,system)

In [10]: | #Vectors
| pNA=x*N.x + y*N.y + 0*N.z

localhost:8888/nbconvert/html/Downloads/Git/Foldable_Robotics_Project/04_Software/03_Anson/Length_Constrained_Dynamics_Optimization_Seg… 4/12

# Adding Forces

pP = lP*N.x + pNA

pAB= pNA + l*A.x
pBC = pAB + l*B.x
pCD = pBC + l*C.x
pDE = pCD + l*D.x
pEF = pDE + l*E.x
pFT = pEF + l*F.x
pTtip = pFT + lT*T.x

#Center of Mass

pAcm=pNA+l/2*A.x
pBcm=pAB+l/2*B.x
pCcm=pBC+l/2*C.x
pDcm=pCD+l/2*D.x
pEcm=pDE+l/2*E.x
pFcm=pEF+l/2*F.x
pTcm=pFT+lT/2*T.x

#Angular Velocity

wNA = N.get_w_to(A)
wAB = A.get_w_to(B)
wBC = B.get_w_to(C)
wCD = C.get_w_to(D)
wDE = D.get_w_to(E)
wEF = E.get_w_to(F)
wFT = F.get_w_to(T)

#Velocities

vA=pAcm.time_derivative()
vB=pBcm.time_derivative()
vC=pCcm.time_derivative()
vD=pDcm.time_derivative()
vE=pEcm.time_derivative()
vF=pFcm.time_derivative()
vTtip=pTtip.time_derivative()

#Interia and Bodys

IA = Dyadic.build(A,Ixx,Iyy,Izz) IB = Dyadic.build(B,Ixx,Iyy,Izz) IC = Dyadic.build(C,Ixx,Iyy,Izz) ID = Dyadic.build(D,Ixx,Iyy,Izz)
IE = Dyadic.build(E,Ixx,Iyy,Izz)
IF = Dyadic.build(F,Ixx,Iyy,Izz)
IT = Dyadic.build(T,Ixx_T,Iyy_T,Izz_T)

BodyA = Body('BodyA',A,pAcm,m,IA,system) BodyB = Body('BodyB',B,pBcm,m,IB,system) BodyC = Body('BodyC',C,pCcm,m,IC,system) BodyD = Body('BodyD',D,pDcm,m,ID,system) BodyE = Body('BodyE',E,pEcm,m,IE,system) BodyF = Body('BodyF',F,pFcm,m,IF,system) BodyT = Body('BodyT',T,pTcm,mT,IT,system)

localhost:8888/nbconvert/html/Downloads/Git/Foldable_Robotics_Project/04_Software/03_Anson/Length_Constrained_Dynamics_Optimization_Seg… 5/12

In this section of code we are adding the aerodynamic, spring, and damping forces in the system. The damping and spring values will be calculated experimentally.

(<pynamics.force.Force at 0x201a9de4e50>, <pynamics.spring.Spring at 0x201a9f5d580>)

# Initial Condition

Solving for initial condition constraints and using scipy to solve for initial states and setting initial states to system initial states.

In [11]:
#Forces

#system.addforce(-torque*sympy.sin(freq*2*pi*system.t)*A.z,wNA) #setting motor paramete

#Aerodynamic Forces orthogonal to flat plates

f_aero_Ay = 998 * vA.length()*(vA.dot(A.y)) * area_p * A.y
f_aero_By = 998 * vB.length()*(vB.dot(B.y)) * area_p * B.y
f_aero_Cy = 998 * vC.length()*(vC.dot(C.y)) * area_p * C.y f_aero_Dy = 998 * vD.length()*(vD.dot(D.y)) * area_p * D.y f_aero_Ey = 998 * vE.length()*(vE.dot(E.y)) * area_p * E.y f_aero_Fy = 998 * vF.length()*(vF.dot(F.y)) * area_p * F.y f_aero_Ty = 998 * vTtip.length()*(vTtip.dot(T.y)) * area_p * T.y

system.addforce(-f_aero_Ay,vA)
system.addforce(-f_aero_By,vB)
system.addforce(-f_aero_Cy,vC)
system.addforce(-f_aero_Dy,vD) system.addforce(-f_aero_Ey,vE) system.addforce(-f_aero_Fy,vF) system.addforce(-f_aero_Ty,vTtip)

#Aerodynamic Forces against front of device

f_aero_Ax = 998 * vA.length()*(vA.dot(A.x)) * area_f * A.x system.addforce(-f_aero_Ax,vA)

#Damping Forces

system.addforce(-b*wAB,wAB)
system.addforce(-b*wBC,wBC) system.addforce(-b*wCD,wCD) system.addforce(-b*wDE,wDE) system.addforce(-b*wEF,wEF) system.addforce(-b*wFT,wFT)

#Spring Force (Torsion)

system.add_spring_force1(k,(qB-qA)*N.z,wAB) system.add_spring_force1(k,(qC-qB)*N.z,wBC) system.add_spring_force1(k,(qD-qC)*N.z,wCD) system.add_spring_force1(k,(qE-qD)*N.z,wDE) system.add_spring_force1(k,(qF-qE)*N.z,wEF) system.add_spring_force1(k,(qT-qF)*N.z,wFT)

# Out[11]: In [12]:

#Constraints for initial condition

eq = []

localhost:8888/nbconvert/html/Downloads/Git/Foldable_Robotics_Project/04_Software/03_Anson/Length_Constrained_Dynamics_Optimization_Seg… 6/12

# Setting Dynamic Constraints

Solving for dynamic constraints of system to run simulation.

eq.append(pFT-pP)

eq_scalar = []
eq_scalar.append(eq[0].dot(N.x)) eq_scalar.append(eq[0].dot(N.y))

In [13]:
#Solve for Intial Conditions

qi = [qA,x,y]

qd = [qB,qC,qD,qE,qF,qT]

eq_scalar_c = [item.subs(system.constant_values) for item in eq_scalar] defined = dict([(item,initialvalues[item]) for item in qi]) eq_scalar_c = [item.subs(defined) for item in eq_scalar_c]

error = (numpy.array(eq_scalar_c)**2).sum()

f = sympy.lambdify(qd,error)

def function(args):
return f(*args)

guess = [initialvalues[item] for item in qd]

result = scipy.optimize.minimize(function,guess) if result.fun>1e-3:
raise(Exception("out of tolerance"))

ini = []
for item in system.get_state_variables(): if item in qd:
ini.append(result.x[qd.index(item)]) else:
ini.append(initialvalues[item])

In [14]:
#Adding Dynamic Constraints

#Position of motor limits

pos = amp*sympy.cos(freq*2*pi*system.t)

eq = []

eq.append(pFT-pP)
eq.append(pos*N.z-qA*A.z)

eq_d = []
eq_d = [item.time_derivative() for item in eq]

eq_dd = []
eq_dd = [item.time_derivative() for item in eq_d]

localhost:8888/nbconvert/html/Downloads/Git/Foldable_Robotics_Project/04_Software/03_Anson/Length_Constrained_Dynamics_Optimization_Seg… 7/12

# Solving for Simulation

Code to run simulation and plot motion, states, and total energy in system.

For my optimization, the goal was to optimize the link surface area for our system. In order to accomplish this, the desired result of the system was the linear displacement of the system relative to the link length. Initially, I minimzed the total linear x distance. The issue with this is that as the link length increases, random movements that generate forward thrust. An example of this is, if the link length is 500mm, then the system moves 290mm. However, if the link length is the optimized value of 27.6mm, the system moves 234mm. These distances are very similar, but the relative size of the system is much smaller for the latter system. This means that the propulsion generated by the second system is much more substantial and additionally repeatable. It was for this reason that the 'perf' value that was optimized was the relative system displI was trying to maximize this value using a minimizing algorithm.

Additionally, the method that was used for optimization was scipy.minimize. The reason that I decided to use this algorithm was that it generated the best results of the different oprimizations given by Scipy. I also added bounds to the system of a minimum value of 10mm and a maximum value of 70mm for both the height and length. The reason that these values were selected were the constraints of the material using and the laser cutter. 10mm would result in very small segmennts and would risk burning the jonts of segments and 70mm was the maximum dimensions supported by the laser cutter for the bed size that we would be using. Additionally, the material we were using for our prototype was fiberglass and we only had 2 sheets for all group members. This meant that our overall dxf files could only be 12 inches long. This is how the 70mm bound was generated.

eq_dd_scalar = []
eq_dd_scalar.append(eq_dd[0].dot(N.x)) eq_dd_scalar.append(eq_dd[0].dot(N.y)) eq_dd_scalar.append(eq_dd[1].dot(N.z))

system.add_constraint(AccelerationConstraint(eq_dd_scalar))

In [15]:
#Solve model and plot angles

#Constraints and Plots

f,ma = system.getdynamics();

tol = 1e-12
points = [pNA,pAB,pBC,pCD,pDE,pEF,pFT,pTtip]

def run_sim(args):
new_l = args[0] #Set to variables that optimizing
new_h = args[1] #Set to variables that optimizing

#updating constant values affected by changing optimized values new_lT = new_l

new_lP = new_l*5.5 localhost:8888/nbconvert/html/Downloads/Git/Foldable_Robotics_Project/04_Software/03_Anson/Length_Constrained_Dynamics_Optimization_Seg… 8/12

2022-04-26 18:30:29,040 - pynamics.system - INFO - getting dynamic equations new_m = 666.7*new_l*new_h*0.001 new_mT = 666.7*new_l*new_h*0.001
new_area_p = new_l*new_h
new_area_f = new_h*0.001
new_Ixx = 1/12*(666.7*new_l*new_h*0.001)*(new_h**2 + 0.001**2) new_Iyy = 1/12*(666.7*new_l*new_h*0.001)*(new_h**2 + new_l**2) new_Izz = 1/12*(666.7*new_l*new_h*0.001)*(new_l**2 + 0.001**2) new_Ixx_T = 1/12*(666.7*new_l*new_h*0.001)*(new_h*2 + 0.001**2) new_Iyy_T = 1/12*(666.7*new_l*new_h*0.001)*(new_h**2 + new_l**2) new_Izz_T = 1/12*(666.7*new_l*new_h*0.001)*(new_l**2 + 0.001**2)

#Populate constants with new values

constants = system.constant_values.copy()
constants[l] = new_l
constants[lT] = new_lT
constants[lP] = new_lP
constants[m] = new_m
constants[mT] = new_mT
constants[area_p] = new_area_p constants[area_f] = new_area_f constants[Ixx] = new_Ixx
constants[Iyy] = new_Iyy
constants[Izz] = new_Izz
constants[Ixx_T] = new_Ixx_T
constants[Iyy_T] = new_Iyy_T
constants[Izz_T] = new_Izz_T

states=pynamics.integration.integrate(func1,ini,t,rtol=tol,atol=tol,hmin=tol, args=

return states

def measured_perf(args):
print(args)
try:
states = run_sim(args)
linear_disp = abs(states[-1,7])/args[0] #linear displacement relative to segmen perf = (1/linear_disp)**2
return perf
except scipy.linalg.LinAlgError:
return 1000

pynamics.system.logger.setLevel(logging.ERROR)

if run_fit:

func1 = system.state_space_post_invert(f,ma)

guess = [0.0276,0.01] #Change depending on what factor you are optimizing

pynamics.system.logger.setLevel(logging.ERROR)

sol = scipy.optimize.minimize(measured_perf,guess,bounds=[(0.01,0.07),(0.01,0.07)]) result = sol.x
print(result)

In [16]: #Constraint Forces

localhost:8888/nbconvert/html/Downloads/Git/Foldable_Robotics_Project/04_Software/03_Anson/Length_Constrained_Dynamics_Optimization_Seg… 9/12

if run_fit:
states2 = run_sim(result)
points_output = PointsOutput(points,system) y2 = points_output.calc(states2,t)

fig = plt.figure()
ax1 = plt.subplot(2,1,2)
ax1.plot(t,states2[:,:7])
ax1.legend(['qA','qB','qC','qD','qE','qF','qT']) ax1.set_title('State Positions') ax1.set_xlabel('Time (s)') ax1.set_ylabel('Position (mm)')

ax2 = plt.subplot(2,1,1)
ax2.plot(y2[:,0,0],y2[:,0,1]) ax2.axis('equal')
ax2.set_title('Position of Head') ax2.set_xlabel('Position X (m)') ax2.set_ylabel('Position Y (m)')

fig.tight_layout()

print(result)

else:

func1,lambda1 = system.state_space_post_invert(f,ma,return_lambda = True) constants = system.constant_values.copy() states=pynamics.integration.integrate_odeint(func1,ini,t, args=({'constants':consta

points_output = PointsOutput(points,system)
y = points_output.calc(states,t)

fig = plt.figure(figsize=(8, 6), dpi=80)

ax1 = plt.subplot(2,1,1)
ax1.plot(y[:,7,0],y[:,7,1]) ax1.axis('equal')
ax1.set_title('Position of Tail Tip') ax1.set_xlabel('Position X (m)') ax1.set_ylabel('Position Y (m)')

ax2 = plt.subplot(2,1,2)
ax2.plot(y[:,0,0],y[:,0,1]) ax2.axis('equal')
ax2.set_title('Position of Head') ax2.set_xlabel('Position X (m)') ax2.set_ylabel('Position Y (m)')

fig.tight_layout()

lambda2 = numpy.array([lambda1(item1,item2,system.constant_values) for item1,item2 plt.figure()
plt.plot(t, lambda2)

points_output = PointsOutput(points,system)
y = points_output.calc(states,t) points_output.plot_time(20)

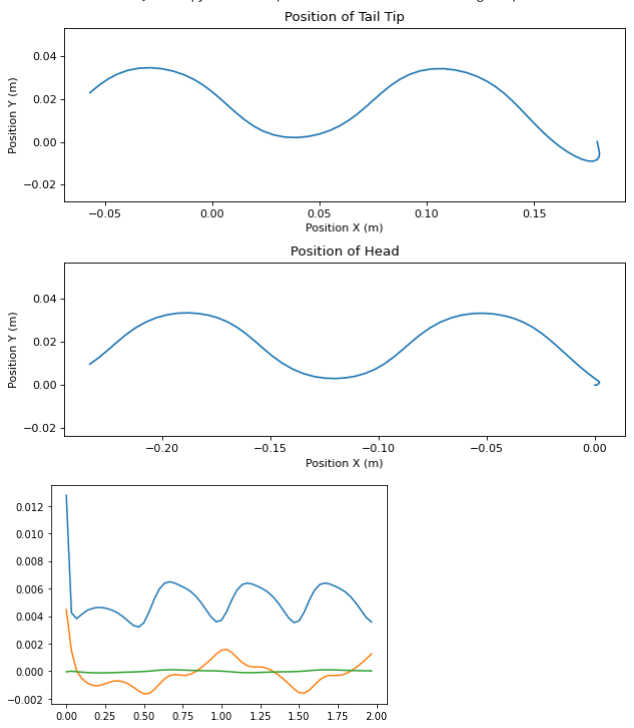
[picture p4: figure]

localhost:8888/nbconvert/html/Downloads/Git/Foldable_Robotics_Project/04_Software/03_Anson/Length_Constrained_Dynamics_Optimization_Se… 10/12

2022-04-26 18:30:40,682 - pynamics.integration - INFO - beginning integration 2022-04-26 18:31:18,892 - pynamics.integration - INFO - finished integration 2022-04-26 18:31:18,932 - pynamics.output - INFO - calculating outputs 2022-04-26 18:31:18,932 - pynamics.output - INFO - done calculating outputs 2022-04-26 18:31:19,618 - pynamics.output - INFO - calculating outputs 2022-04-26 18:31:19,626 - pynamics.output - INFO - done calculating outputs

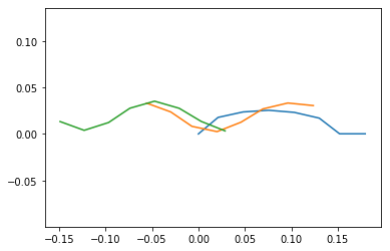
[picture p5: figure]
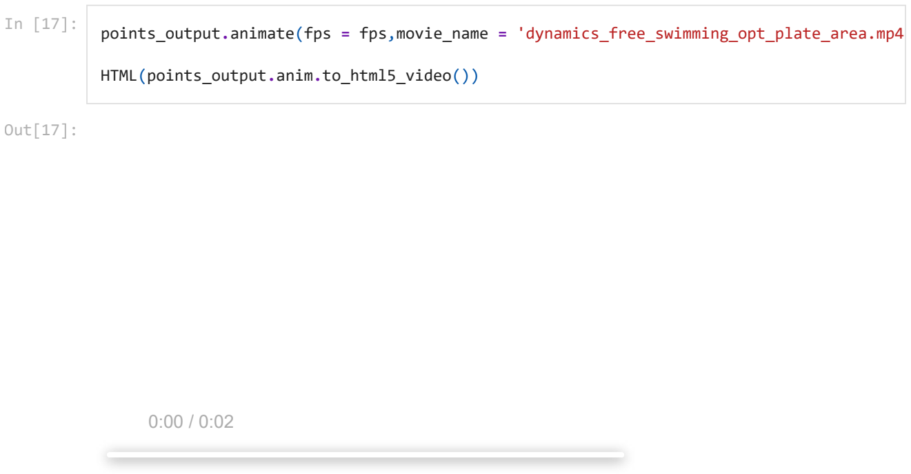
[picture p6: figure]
points_output.animate(fps = fps,movie_name = 'dynamics_free_swimming_opt_plate_area.mp4; HTML(points_output.anim.to_html5_video()); Out[17]:

localhost:8888/nbconvert/html/Downloads/Git/Foldable_Robotics_Project/04_Software/03_Anson/Length_Constrained_Dynamics_Optimization_Se… 11/12

In [19]:
#Plots of Simulation Vs Data

#import test data and convert to numPy arrays data = pd.read_excel(r'Link_Data.xlsx')

df = data.to_numpy()

fig = plt.figure()
plt.plot(t,y[:,0,0],df[:,0],df[:,1]) plt.axis('equal')
plt.title('Position of Head in X Axus') plt.xlabel('Time (s)')
plt.ylabel('Position x (m)') plt.legend(['Experimet' 'Simulation'])

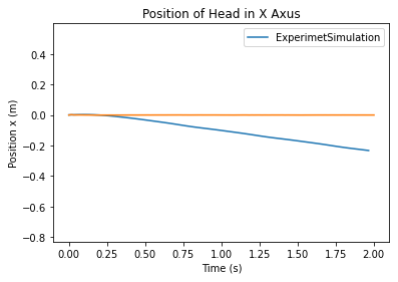
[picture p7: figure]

localhost:8888/nbconvert/html/Downloads/Git/Foldable_Robotics_Project/04_Software/03_Anson/Length_Constrained_Dynamics_Optimization_Se… 12/12

<matplotlib.legend.Legend at 0x201ae5a94c0>

# Prototype

After optimizing the link dimensions with a height of 10mm and length of 27.6mm. I then made a laminate structure using 0.010 inch fiberglass for the rigid material and 0.005 inch polyesther as the flexible material. The following pictures are of that prototype and the test set up for the system to swim in water.

I ran the experiment with the same motor parameters and length constrained distnace as the simulation. However, the system did not move at all (Video attached in sumbission). The likely reason for this is that the servo motor and carriage that were used to support the device was substantially heavier than the device itself. Therefore the inertia of the carriage required a thrust that the device could not generate. If an additional version of the system was to be made, using a stiffer flexible material would be necessary. The plate geometry was optimized for the given stiffness of the 0.005 inch polyesther plastic. This was a very soft material and therefore required a very small system to match the stiffness. If a stiffer material could be used for the flexible layer, then the whole system could get scaled to match the inertia and mass of the carriage.

Based off the simulation, the design is feasible but requires tuning based off the method in which it is tested. Because the device did not move at all, there was no reason to plot the experimental displacement and the simulated experiment. The experiment had a zero displacement and would not provide any correlation between the experiment and the simulation.

Out[19]:

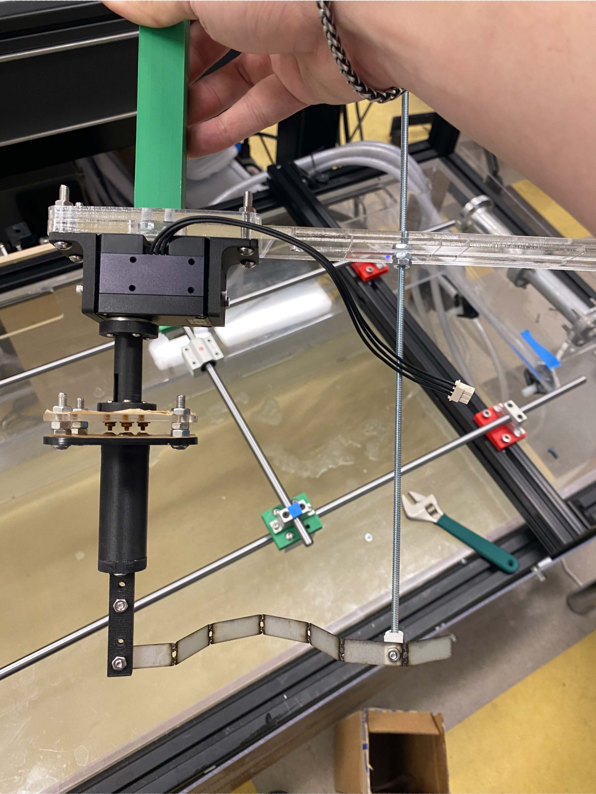
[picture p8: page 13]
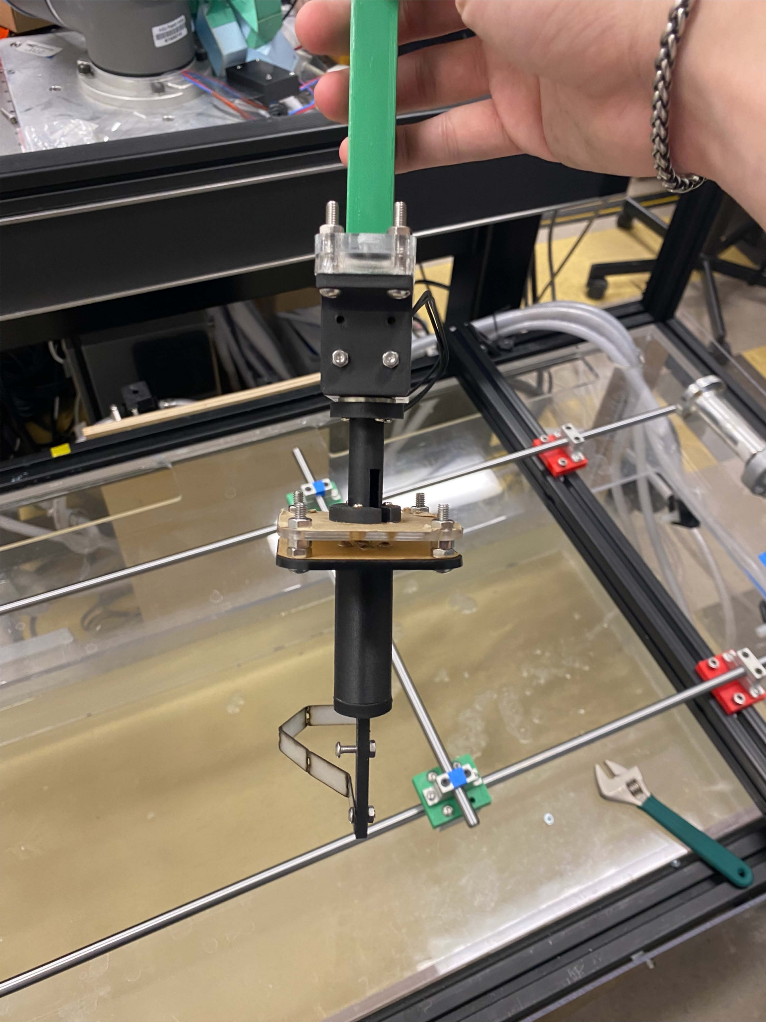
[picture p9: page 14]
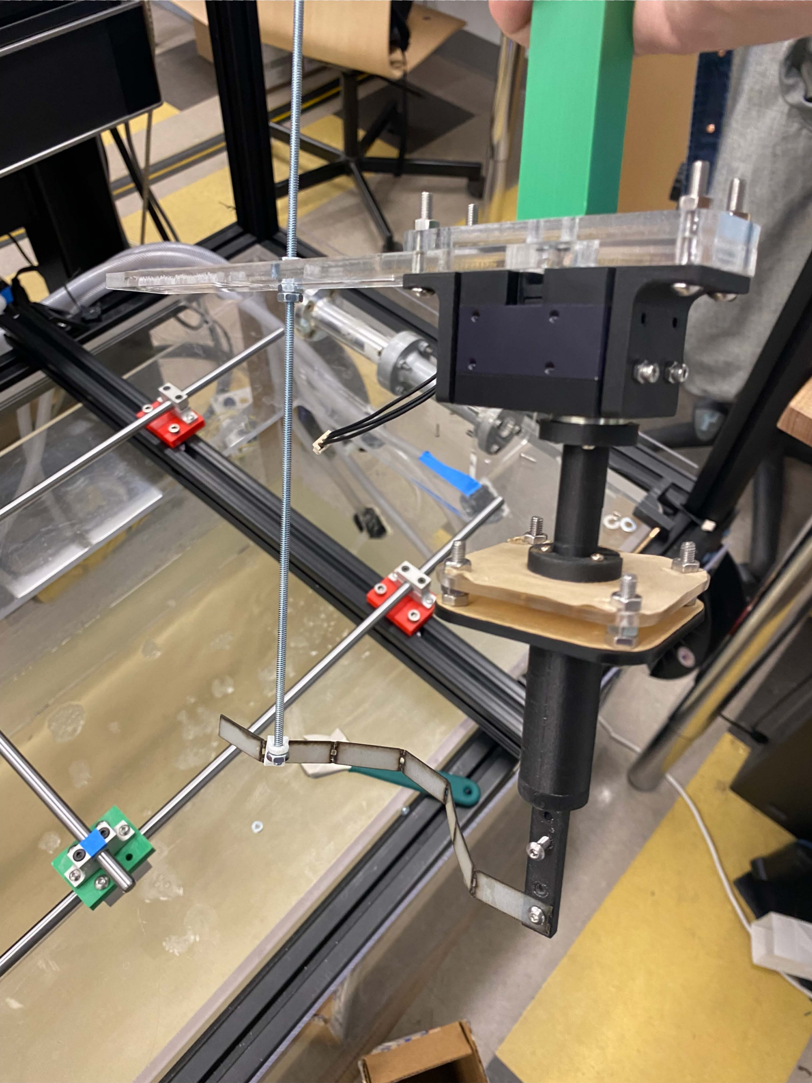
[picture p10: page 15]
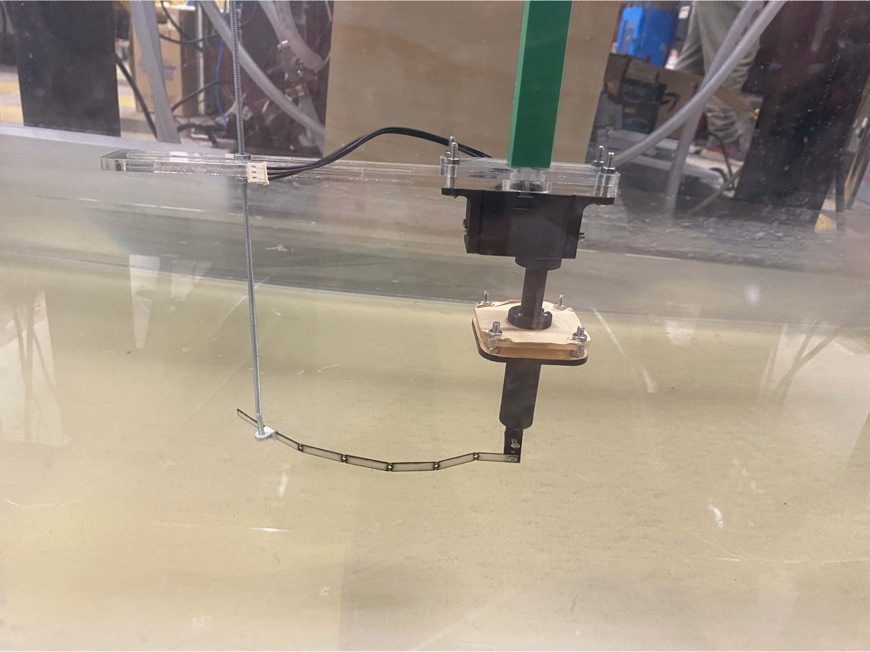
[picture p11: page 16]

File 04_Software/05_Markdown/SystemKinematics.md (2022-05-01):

---
title: System Kinematics 
---

# Code:
```python
%matplotlib inline
```

```python
#Set model to freely swim
use_free_move = False
```

```python
import pynamics
from pynamics.frame import Frame
from pynamics.variable_types import Differentiable,Constant
from pynamics.system import System
from pynamics.body import Body
from pynamics.dyadic import Dyadic
from pynamics.output import Output,PointsOutput
from pynamics.output_points_3d import PointsOutput3D
from pynamics.constraint import AccelerationConstraint,KinematicConstraint
from pynamics.particle import Particle
import pynamics.integration
import numpy
import matplotlib.pyplot as plt
plt.ion()
from math import pi,sin
import sympy
from sympy import sqrt
import math
import scipy.optimize
from matplotlib import animation, rc
from IPython.display import HTML

system = System()
pynamics.set_system(__name__,system)
```

```python
#Defining Constants of System
seg_len = .005
seg_mass = 1
seg_h = 1
seg_th = 1

lA = Constant(seg_len,'lA',system)
lB = Constant(seg_len,'lB',system)
lC = Constant(seg_len,'lC',system)
lD = Constant(seg_len,'lD',system)
lE = Constant(seg_len,'lE',system)
lF = Constant(seg_len,'lF',system)
lG = Constant(seg_len,'lG',system) #Tail segment
lP = Constant(seg_len*5,'lP',system) #Constrained length

mA = Constant(seg_mass,'mA',system)
mB = Constant(seg_mass,'mB',system)
mC = Constant(seg_mass,'mC',system)
mD = Constant(seg_mass,'mD',system)
mE = Constant(seg_mass,'mE',system)
mF = Constant(seg_mass,'mF',system)
mG = Constant(seg_mass,'mG',system)

g = Constant(9.81,'g',system)
b = Constant(1e-1,'b',system)
k = Constant(1e0,'k',system)

freq = Constant(.1,'freq',system)
amp = Constant(55*pi/180,'torque',system)
torque = Constant(1e0,'torque',system)

Ixx_A = Constant(1/12*seg_mass*(seg_h*2 + seg_th**2),'Ixx_A',system)
Iyy_A = Constant(1/12*seg_mass*(seg_h**2 + seg_len**2),'Iyy_A',system)
Izz_A = Constant(1/12*seg_mass*(seg_len**2 + seg_th**2),'Izz_A',system)
Ixx_B = Constant(1/12*seg_mass*(seg_h*2 + seg_th**2),'Ixx_B',system)
Iyy_B = Constant(1/12*seg_mass*(seg_h**2 + seg_len**2),'Iyy_B',system)
Izz_B = Constant(1/12*seg_mass*(seg_len**2 + seg_th**2),'Izz_B',system)
Ixx_C = Constant(1/12*seg_mass*(seg_h*2 + seg_th**2),'Ixx_C',system)
Iyy_C = Constant(1/12*seg_mass*(seg_h**2 + seg_len**2),'Iyy_C',system)
Izz_C = Constant(1/12*seg_mass*(seg_len**2 + seg_th**2),'Izz_C',system)
Ixx_D = Constant(1/12*seg_mass*(seg_h*2 + seg_th**2),'Ixx_D',system)
Iyy_D = Constant(1/12*seg_mass*(seg_h**2 + seg_len**2),'Iyy_D',system)
Izz_D = Constant(1/12*seg_mass*(seg_len**2 + seg_th**2),'Izz_D',system)
Ixx_E = Constant(1/12*seg_mass*(seg_h*2 + seg_th**2),'Ixx_E',system)
Iyy_E = Constant(1/12*seg_mass*(seg_h**2 + seg_len**2),'Iyy_E',system)
Izz_E = Constant(1/12*seg_mass*(seg_len**2 + seg_th**2),'Izz_E',system)
Ixx_F = Constant(1/12*seg_mass*(seg_h*2 + seg_th**2),'Ixx_F',system)
Iyy_F = Constant(1/12*seg_mass*(seg_h**2 + seg_len**2),'Iyy_F',system)
Izz_F = Constant(1/12*seg_mass*(seg_len**2 + seg_th**2),'Izz_F',system)
Ixx_G = Constant(1/12*seg_mass*(seg_h*2 + seg_th**2),'Ixx_G',system)
Iyy_G = Constant(1/12*seg_mass*(seg_h**2 + seg_len**2),'Iyy_G',system)
Izz_G = Constant(1/12*seg_mass*(seg_len**2 + seg_th**2),'Izz_G',system)
```

```python
#Set integration tolerance
tol = 1e-3
```

```python
#Set simulation run time
tinitial = 0
tfinal = 10
fps = 30
tstep = 1/fps
t = numpy.r_[tinitial:tfinal:tstep]
```

```python
#Define derivatives of frames
qA,qA_d,qA_dd = Differentiable('qA',system)
qB,qB_d,qB_dd = Differentiable('qB',system)
qC,qC_d,qC_dd = Differentiable('qC',system)
qD,qD_d,qD_dd = Differentiable('qD',system)
qE,qE_d,qE_dd = Differentiable('qE',system)
qF,qF_d,qF_dd = Differentiable('qF',system)
qG,qG_d,qG_dd = Differentiable('qG',system)

if use_free_move:
    x,x_d,x_dd = Differentiable('x',system)
    #y,y_d,y_dd = Differentiable('y',system)
```

```python
#set initial conditions
initialvalues = {}
initialvalues[qA]=70*pi/180
initialvalues[qA_d]=0*pi/180
initialvalues[qB]=30*pi/180
initialvalues[qB_d]=0*pi/180
initialvalues[qC]=0*pi/180
initialvalues[qC_d]=0*pi/180
initialvalues[qD]=0*pi/180
initialvalues[qD_d]=0*pi/180
initialvalues[qE]=-10*pi/180
initialvalues[qE_d]=0*pi/180
initialvalues[qF]=-40*pi/180
initialvalues[qF_d]=0*pi/180
initialvalues[qG]=0*pi/180
initialvalues[qG_d]=0*pi/180

if use_free_move:
    initialvalues[x]=0*pi/180
    initialvalues[x_d]=0*pi/180
    #initialvalues[y]=0*pi/180
    #initialvalues[y_d]=0*pi/180

statevariables = system.get_state_variables()
ini0 = [initialvalues[item] for item in statevariables]
```

```python
#Frames
N = Frame('N',system)
A = Frame('A',system)
B = Frame('B',system)
C = Frame('C',system)
D = Frame('D',system)
E = Frame('E',system)
F = Frame('F',system)
G = Frame('G',system)

system.set_newtonian(N)

A.rotate_fixed_axis(N,[0,0,1],qA,system)
B.rotate_fixed_axis(N,[0,0,1],qB,system)
C.rotate_fixed_axis(N,[0,0,1],qC,system)
D.rotate_fixed_axis(N,[0,0,1],qD,system)
E.rotate_fixed_axis(N,[0,0,1],qE,system)
F.rotate_fixed_axis(N,[0,0,1],qF,system)
G.rotate_fixed_axis(N,[0,0,1],qG,system)
```

```python
#Vectors

if use_free_move:
    pNA=x*N.x + 0*N.y + 0*N.z
    pP = lP*N.x + x*N.x
else:
    pNA=0*N.x + 0*N.y + 0*N.z
    pP = lP*N.x
    
pAB= pNA + lA*A.x
pBC = pAB + lB*B.x
pCD = pBC + lC*C.x
pDE = pCD + lD*D.x
pEF = pDE + lE*E.x
pFG = pEF + lF*F.x
pGtip = pFG + lG*G.x

#Center of Mass
pAcm=pNA+lA/2*A.x
pBcm=pAB+lB/2*B.x
pCcm=pBC+lC/2*C.x
pDcm=pCD+lD/2*D.x
pEcm=pDE+lE/2*E.x
pFcm=pEF+lF/2*F.x
pGcm=pFG+lG/2*G.x

#Angular Velocity
wNA = N.get_w_to(A)
wAB = A.get_w_to(B) 
wBC = B.get_w_to(C)
wCD = C.get_w_to(D) 
wDE = D.get_w_to(E)
wEF = E.get_w_to(F)
wFG = F.get_w_to(G)

#Velocities 
vGtip=pGtip.time_derivative()

#Interia and Bodys
IA = Dyadic.build(A,Ixx_A,Iyy_A,Izz_A)
IB = Dyadic.build(B,Ixx_B,Iyy_B,Izz_B)
IC = Dyadic.build(C,Ixx_C,Iyy_C,Izz_C)
ID = Dyadic.build(D,Ixx_D,Iyy_D,Izz_D)
IE = Dyadic.build(E,Ixx_E,Iyy_E,Izz_E)
IF = Dyadic.build(F,Ixx_F,Iyy_F,Izz_F)
IG = Dyadic.build(G,Ixx_G,Iyy_G,Izz_G)

BodyA = Body('BodyA',A,pAcm,mA,IA,system)
BodyB = Body('BodyB',B,pBcm,mB,IB,system)
BodyC = Body('BodyC',C,pCcm,mC,IC,system)
BodyD = Body('BodyD',D,pDcm,mD,ID,system)
BodyE = Body('BodyE',E,pEcm,mE,IE,system)
BodyF = Body('BodyF',F,pFcm,mF,IF,system)
BodyG = Body('BodyG',G,pGcm,mG,IG,system)
```

```python
#Forces
#system.addforce(torque*sympy.cos(freq*2*pi*system.t)*A.z,wNA)

#Damping Forces
system.addforce(-b*wNA,wNA)
system.addforce(-b*wAB,wAB)
system.addforce(-b*wBC,wBC)
system.addforce(-b*wCD,wCD)
system.addforce(-b*wDE,wDE)
system.addforce(-b*wEF,wEF)
system.addforce(-b*wFG,wFG)

#Spring Force (Torsion)
system.add_spring_force1(k,(qA)*N.z,wNA) 
system.add_spring_force1(k,(qB-qA)*N.z,wAB)
system.add_spring_force1(k,(qC-qB)*N.z,wBC)
system.add_spring_force1(k,(qD-qC)*N.z,wCD) 
system.add_spring_force1(k,(qE-qD)*N.z,wDE)
system.add_spring_force1(k,(qF-qE)*N.z,wEF)
system.add_spring_force1(k,(qG-qF)*N.z,wFG)
```

    (<pynamics.force.Force at 0x1e3874a5760>,
     <pynamics.spring.Spring at 0x1e3875af7c0>)

```python
#Constraints for initial condition

eq = []

eq.append(pFG-pP)
    
eq_scalar = []
eq_scalar.append(eq[0].dot(N.x))
eq_scalar.append(eq[0].dot(N.y))
eq_scalar
```

    [lA*cos(qA) + lB*cos(qB) + lC*cos(qC) + lD*cos(qD) + lE*cos(qE) + lF*cos(qF) - lP, lA*sin(qA) + lB*sin(qB) + lC*sin(qC) + lD*sin(qD) + lE*sin(qE) + lF*sin(qF)]

```python
#Solve for Intial Conditions
if use_free_move:
    qi = [qA,x]
else:  
    qi = [qA]
    
qd = [qB,qC,qD,qE,qF,qG]

eq_scalar_c = [item.subs(system.constant_values) for item in eq_scalar]
defined = dict([(item,initialvalues[item]) for item in qi])
eq_scalar_c = [item.subs(defined) for item in eq_scalar_c]

error = (numpy.array(eq_scalar_c)**2).sum()

f = sympy.lambdify(qd,error)

def function(args):
    return f(*args)

guess = [initialvalues[item] for item in qd]

result = scipy.optimize.minimize(function,guess)
if result.fun>1e-6:
    raise(Exception("out of tolerance"))
    
ini = []
for item in system.get_state_variables():
    if item in qd:
        ini.append(result.x[qd.index(item)])
    else:
        ini.append(initialvalues[item])
```

```python
#Plot Initial State
points = [pNA,pAB,pBC,pCD,pDE,pEF,pFG,pGtip]
points_output = PointsOutput(points, constant_values=system.constant_values)
points_output.calc(numpy.array([ini0,ini]),numpy.array([0,1]))
points_output.plot_time()
```

    2022-04-08 17:12:12,727 - pynamics.output - INFO - calculating outputs
    2022-04-08 17:12:13,015 - pynamics.output - INFO - done calculating outputs

    <AxesSubplot:>

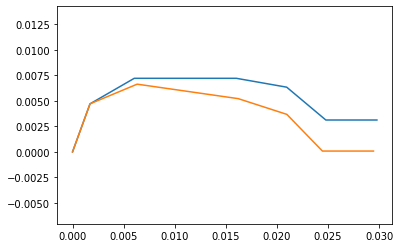
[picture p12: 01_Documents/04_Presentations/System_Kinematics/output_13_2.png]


Plot of Device: Points are as follow from left to right. (pNA,pAB,pBC,pCD,pDE,pEF,pFG,pGtip). All the frames are relative to the newtonian frame. See last page of document to see diagram of device.

```python
#Solve for Torque at end effector (qG_tip)

#Derivative of constraints
eq_d = [(system.derivative(item)) for item in eq_scalar]
eq_d = sympy.Matrix(eq_d)
eq_d = eq_d.subs(system.constant_values)

qi = sympy.Matrix([qA_d])
qd = sympy.Matrix([qB_d,qC_d,qD_d,qE_d,qF_d,qG_d])

AA = eq_d.jacobian(qi)

BB = eq_d.jacobian(qd)

J_int = -BB.transpose()*AA
J_int

vout = pGtip.time_derivative()
vout = sympy.Matrix([vout.dot(N.x), vout.dot(N.y)])

Ji = vout.jacobian(qi)
Jd = vout.jacobian(qd)

J = Ji + Jd*J_int

J = [item.subs(system.constant_values).subs({qA:ini[0], qB:ini[1], qC:ini[2], qD:ini[3], qE:ini[4], qF:ini[5], qG:ini[6]}) for item in J]

print('Velocity at pGtip')
J
```

    Velocity at pGtip

    [-0.00469839990567111, 0.00171000544586941]

```python
#Adding Dynamic Constraints

#Position of motor limits
pos = amp*sympy.cos(freq*2*pi*system.t)

eq = []

eq.append(pFG-pP)
#eq.append(pos*N.z-qA*N.z)

eq_scalar = []
eq_scalar.append(eq[0].dot(N.x))
eq_scalar.append(eq[0].dot(N.y))
#eq_scalar.append(eq[1].dot(N.z))
eq_scalar_d = [system.derivative(item) for item in eq_scalar]
eq_scalar_dd = [system.derivative(item) for item in eq_scalar_d]

system.add_constraint(AccelerationConstraint(eq_scalar_dd))
```

```python
#Solve model and plot angles

f,ma = system.getdynamics()

func1,lambda1 = system.state_space_post_invert(f,ma,return_lambda = True)

states=pynamics.integration.integrate(func1,ini,t,rtol=tol,atol=tol,hmin=tol, args=({'constants':system.constant_values},))

plt.figure()
artists = plt.plot(t,states[:,:7])
plt.legend(artists,['qA','qB','qC','qD','qE','qF','qG'])
```

    2022-04-08 17:12:14,427 - pynamics.system - INFO - getting dynamic equations
    2022-04-08 17:12:18,296 - pynamics.system - INFO - solving a = f/m and creating function
    2022-04-08 17:12:21,534 - pynamics.system - INFO - substituting constrained in Ma-f.
    2022-04-08 17:12:22,178 - pynamics.system - INFO - done solving a = f/m and creating function
    2022-04-08 17:12:22,178 - pynamics.system - INFO - calculating function for lambdas
    2022-04-08 17:12:22,380 - pynamics.integration - INFO - beginning integration
    2022-04-08 17:12:22,380 - pynamics.system - INFO - integration at time 0000.00
    2022-04-08 17:12:23,125 - pynamics.integration - INFO - finished integration

    <matplotlib.legend.Legend at 0x1e38999c0d0>

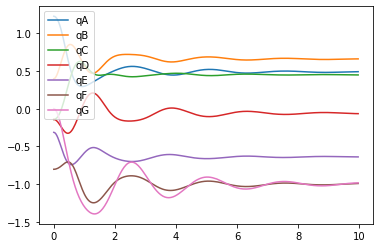
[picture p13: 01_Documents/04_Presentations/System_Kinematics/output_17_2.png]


```python
points_output = PointsOutput(points,system)
y = points_output.calc(states,t)
points_output.plot_time(20)
```

    2022-04-08 17:12:23,720 - pynamics.output - INFO - calculating outputs
    2022-04-08 17:12:23,769 - pynamics.output - INFO - done calculating outputs

    <AxesSubplot:>

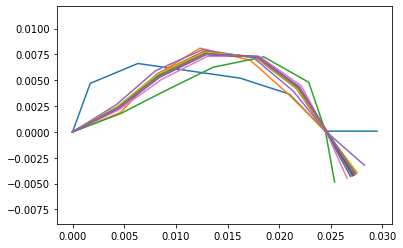
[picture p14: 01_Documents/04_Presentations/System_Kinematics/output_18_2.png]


```python
#Constraint Forces

lambda2 = numpy.array([lambda1(item1,item2,system.constant_values) for item1,item2 in zip(t,states)])
plt.figure()
plt.plot(t, lambda2)
```

    [<matplotlib.lines.Line2D at 0x1e38bb7ae80>,
     <matplotlib.lines.Line2D at 0x1e38bb7aee0>]

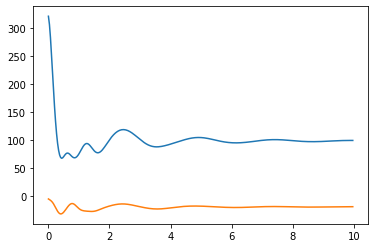
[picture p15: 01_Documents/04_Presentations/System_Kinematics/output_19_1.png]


```python
#Energy Plot

KE = system.get_KE()
PE = system.getPESprings()
energy_output = Output([KE-PE],system)
energy_output.calc(states,t)
energy_output.plot_time(t)
```

    2022-04-08 17:12:25,509 - pynamics.output - INFO - calculating outputs
    2022-04-08 17:12:25,662 - pynamics.output - INFO - done calculating outputs

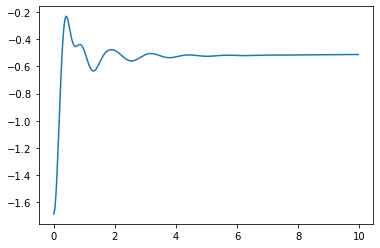
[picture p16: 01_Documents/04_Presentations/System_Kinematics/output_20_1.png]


```python
#Plotting Motion of Tail

plt.plot(y[:,7,0],y[:,7,1])
plt.axis('equal')
plt.title('Position of Tail')
plt.xlabel('Position X (m)')
plt.ylabel('Position Y (m)')
```

    Text(0, 0.5, 'Position Y (m)')

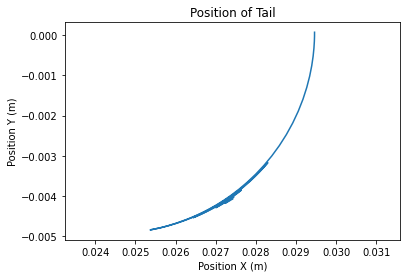
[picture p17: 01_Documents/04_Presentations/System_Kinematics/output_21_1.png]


```python
points_output.animate(fps = fps,movie_name = 'render.mp4',lw=2,marker='o',color=(1,0,0,1),linestyle='-')
HTML(points_output.anim.to_html5_video())
```

<video width="432" height="288" controls autoplay loop>
  <source type="video/mp4" src="data:video/mp4;base64,AAAAIGZ0eXBNNFYgAAACAE00ViBpc29taXNvMmF2YzEAAAAIZnJlZQABHrhtZGF0AAACoAYF//+c
3EXpvebZSLeWLNgg2SPu73gyNjQgLSBjb3JlIDE2MSAtIEguMjY0L01QRUctNCBBVkMgY29kZWMg
LSBDb3B5bGVmdCAyMDAzLTIwMjAgLSBodHRwOi8vd3d3LnZpZGVvbGFuLm9yZy94MjY0Lmh0bWwg
LSBvcHRpb25zOiBjYWJhYz0xIHJlZj0zIGRlYmxvY2s9MTowOjAgYW5hbHlzZT0weDM6MHgxMTMg
bWU9aGV4IHN1Ym1lPTcgcHN5PTEgcHN5X3JkPTEuMDA6MC4wMCBtaXhlZF9yZWY9MSBtZV9yYW5n
ZT0xNiBjaHJvbWFfbWU9MSB0cmVsbGlzPTEgOHg4ZGN0PTEgY3FtPTAgZGVhZHpvbmU9MjEsMTEg
ZmFzdF9wc2tpcD0xIGNocm9tYV9xcF9vZmZzZXQ9LTIgdGhyZWFkcz05IGxvb2thaGVhZF90aHJl
YWRzPTEgc2xpY2VkX3RocmVhZHM9MCBucj0wIGRlY2ltYXRlPTEgaW50ZXJsYWNlZD0wIGJsdXJh
eV9jb21wYXQ9MCBjb25zdHJhaW5lZF9pbnRyYT0wIGJmcmFtZXM9MyBiX3B5cmFtaWQ9MiBiX2Fk
YXB0PTEgYl9iaWFzPTAgZGlyZWN0PTEgd2VpZ2h0Yj0xIG9wZW5fZ29wPTAgd2VpZ2h0cD0yIGtl
eWludD0yNTAga2V5aW50X21pbj0yNSBzY2VuZWN1dD00MCBpbnRyYV9yZWZyZXNoPTAgcmNfbG9v
a2FoZWFkPTQwIHJjPWNyZiBtYnRyZWU9MSBjcmY9MjMuMCBxY29tcD0wLjYwIHFwbWluPTAgcXBt
YXg9NjkgcXBzdGVwPTQgaXBfcmF0aW89MS40MCBhcT0xOjEuMDAAgAAAEpNliIQAM//+9uy+BTX9
n9CXESzF2kpwPiqkgIB3NMAAAAMAAHgdKF7oOEqr0MAAG3AAb80UfrEXym4ZgCKFvRvywAGLCH55
JXmheJKwhqGj/ybr7HUYVcx5zd9XVy3mRQJ9t+hyB/6IjiRfZ78sfJo/h7zAmSQnejMG8nSKVu+t
V4OAuF8JZgPgWe6wIxHhavTDeeZBNZF2vbGiR0nhWoKRA0QUH19UA0enfK8k+Z84rUoKnkkbClBC
grcC1NX5oKLwfPw68dWKpa0CCpyfPRwhE+M6T/qB0iadJPr4vyvjr5zgPlBWYWeXUvn+ofnW4YEV
pb6G8P617U/XfNQDGMPmFTiVaqbY77Y+SxdnyZJoUSoBw/M5OAfAK8mf3ExhftW/FsiAmyA1fNdF
VQaz89MZQ8Nlk8bhnqQddOW//cvISQH/nJnmtrpPUp4s2xsDQyWsDJwxQO/qsznow31WpDcoYp2I
NvBJLGKrKWBR0VGz4zk8UiG9iof/CrOMOhsXAXT3/JOGIUlgW7pILStH5FsF+bDwdqfvjb62JE8O
3aPoMGNERsYsmNaZs5YNcFE1j/lJ4BaTJD0oEmWAZ1gd0/YGU8onML4yMF5oyax1RcoLF6J8V+pH
oh3sN2QMWR/2uggZ1w3yWiUIpbga5t+2pllC3yUfTt5E/0tqSl9i7Ooe/ZqtcC82dTR1I5qPyEXy
Agrrl38T3O+hM5hfNHeUV+PMddD+ArlBtKgiSLCmzeLVq4JVNaC+1ycopGkdgxRWkCENSTJAdNke
wknRXDZNcIchV5nnyxKZYMHZBmGkI2bj7ln17yotbLiIOOmmzmy8mZhROa2DR8UCns2uGYKYQYlS
ylhQATmCdJwcVWIS4hFSOKlN2srHl6rjxBODeAbVIJryPtcAYMvNNrgNVv5NFERbm1KUw+O73bmW
5pcL/Z83gyW4yw7WjTYsKkwBO/4M6idu28l4A4Q7leoj8KhfaBmAjMZ5hpyUXJQPUNgK74LxVUh4
pOjy22zDN3bHKgeAFMm9OAh2yqPlUxRK39gQ+F462Z/9XWVb5GbQ1k+LsFQOoepYbJ9lklgdQOG5
CBQVNYmnB0sX+7kKR14kcNM1Nv1VYxioF2swaaUgeiou9B3xa2lw0yMZ/UXACELq/rf19rroUc+d
dowORWpbrdpW4xAJ7XTGPBYYfxOU0KwkJfhDF0rAN+aU5hg7W1rSTcQIzRM25lDxykf5fiMSZDSj
Cr8+cXpAkK92YYjH2W0ATv+kxDZA9oraNpksizA+RuRPwVtAgR7eog+PEvnhyPNwtTqXi51/VNyS
XOewiFNIktxVtbW1PsLuwCeMXkSn9Th6dceCMkseJj1itl+QhwsFWRJvgS+gA6C9DZXYsprTdwLw
GJNu6XeNZJ4gPwwVHdWXL1iDknPs5ZAHCp5JhqFhLngfCI+D7D7dblAcFIEiW6CLenhW6XW4eeW8
UynA/gC5MdLSXRV1MhaUlQovuVXNwRKcru2w53dQ4Bd9OZfz7KMFA+E2BqcCJofzRqCXd+8UKBne
NYmVSg2852OWp9aOFpSd0bKSNIKN9LB2QlkJsNZfkhC5YF4f2yTanUJJZrYPyYPkLWTDDy1m9J6U
8Qg51Dl8dEm5OXGkcidL0HVNWc4Fj6GsE/7985r2+eWRvHDX6UT3EqhxCAu97A4SYrVLVcd1J5tD
S4Zo6tBt9orpMYbtKSwAKt1LEwnroHTaOdQwkWtrmGJm4Fxt7fzUIhLlVE2BjwgO/2A8cnk4JSvO
1V3ixDgw1Z9yimZ/2nUu3+mnKzPAlAVk0d6kNvbYZvcMFIZk72GbURqIbbkmwGgpYTimia/yy+G3
hVRxf8b5WDFsngUlIb2SrsrvFWJaf1TI61i9a5Gr9vB2AueZMMQqYI+b0GCq/leQ1nsLlQepqH5I
cf+em8BH/PIoGAxFoMgWtw1La9Q57KHZbSisI0HzBOfHYBborDt3dqizXIPMfW4or8Fm/QyctBBA
YtzPMWzu34SekeFlvJUkr5Pi9euijXAZUxWZmtV6Wu13qfM80c2EJ26ZMQu8S7DGWUwaBzMdKMSY
90+i+c5D1YA1tuMBmlEXVKVZqGp16VpAwrQTG7fKsZDvuLGsPXM5iLyYvg8Ud1+W60BkPerZ/6nv
37HFfwJDcwhXS41ta8ZuTIoM3n7W8wX0v/wjGBsRm8WWjH95FjYZHoDYYuv0mNgX8nA31OVp7vLJ
0Zt1qIbWAY45QV3oAsl3brLlQid6MkE2DQDDaaWtAu9pOpmGQWeSf+uTbSls2dfo22d7Z4TX6mLb
Xe/NkK69FBgnanzEAayYjtX/GXoLSpUqWW3KuKd96WQViMTp2++fUR53c21QRaOW2yBEFH+mU0UZ
x5z5hl5UrpHP2CWXcOPDgD9XQ26Xmmu6rymu+1FSfahQnfPBPWaqN+fiIWK3c1bm+0VTRR5wyUHk
2TFxSbiYU8oOUlQJw3I1Q8hoPKGoxUz5XxNIxWwpVXjrhmShU7V96WXttqAQQ6IPMnyZkP2IXhWW
oIw8tO3afCtrmN9LlnXceXxbqUHcJskKdBXbEyCg/HRDPleMWvdanyVumA8087ZyTdB0SlkL1pVm
uKVQUL1GNTVwtj9kVA8NiMgj6hXasXRxhz3EcnS85h2Ec3LQzPQQEyrv7QqCBBcHRXeE9mjBoDX9
zeSr/P3KePk3FURd3SM93F8rXFPfkmLm519vlgKIVXDP4VR3DR0g9oTWGohSkGObg1Vh2N5I+XiT
KBn4MXWKROsUF9q+m1cSYppqsOoCTy6mMChrXV3rPybzyJFDJohC4ckaDWMNkIoKE/2xSeYWQ3Dp
dK3fMseQkUuvEYukfTcttpJDe5o1LIm4iAk7ZVg/v8X/+8pedBV8lziF+le7Flg3N4Y1hwwUYrzg
ufXDW4HSaV4L6ZUDfwgr/InDCSX8xBhGcJQBk5///BCGUFwJhxiO3XX3IybKKtalBAWdMVt8fykC
bRYp3Q4SmGKF2Z/KSjn7P4++qAkLqx4+czdODcC4f2rZmCecSD/ivAOvSeVN0nvIgGf+OP5pA9Aj
mo8aSS8su6Eq5Q+VgWkpZtt8iD0IuiMkl6EQTxBGYyoOx2JXbPKn+EAO2Wro+DdaqL1lMqHRS/rS
reoaRrgGVFr3VyIyls7mqHIlbKnbAPkkMuCedW+mHEah0zUl3UlZQitQanr8A3gUoTS5UdA4huOl
OoAcpOiRsww1cfpk9tLDRaF0ekDm9d5TC5n9dnCaRFMuUgK++BPi8fX0A5K/p5M4iIDrG4ww7hAm
rlMVjs4exv/YhtrQZ4gqpTJpU+ZdcFkoa5RkoXyN6CSifH2UYlCbwKlzfE2qtJvIuqYYK7KGDXGI
uEavIk/kZuSs94ypmRvwcNO8z6gweJ1jAjB1eL2Cy0YDXMsV7WXXbdyJ/6vNpQn+8NCyJ+Ejiyyv
gIrqaIhMN9VWmOkVVUUSo+yyPYm2UudRSvxqedpuGRmkWUhoyAp0r3+0A1Ds4Hgj0XIHpgRvlO2E
m+8vaqBbam3Q5cv/C5OTDcNEEvz4laIMG1kExBq3nIiwARTI9wTAV4+RYerpItR4Pzdxk5MxD5P2
ZFARCV27M4Fat3MI++m4+oIpCQZBiO35twHXPswcVgiL9LmkyGpN50oIMtVbAChpUnBIDbdQiAbq
75C/UeRUoJnk2eU509Q7kPkVbkmkhppb+gSQNPT796nkIoofRCz+AGbDmUkvNjTWS6z/jWPLAQtL
PwLZyLNeUgtGwvqh1dPhzPY4EsUHxKtu7GzoXz8ae8W7rmF0XunD/MPuga/waMLuo2TLBokRJeV0
zvEf9m4hbm1mWoKI7e19YGCsrGWwlm/O7WL7D68FIpcv+hKejQ5IzOb+bIL5FJaPS9tRxLhsuywU
MDVLZ5PwqGB0AQGtoRLmdefK+k+VMCpJ8YkVESAtDLGsUFrNIDt5cgGu+4ROA09uWT/suLvgu/pu
7O9+sf1x/os9bCB+TKzGLFR6c5HgoeaQqFBZqkQnm5FzYFa/kJLu26A63l1FA78WftS5NOHqF5zt
FZAgOxsEtP+aNT7Y1tZUj0uQZWQygjj2PsBs58Y8RAdjQ723OFh9yPeewJOetjsk0nGo2VwP21SG
1J3IZVlUGMJnCLa4444nxo/SpjN2pVeaDVn9rvMkHuC//KF0iivt3LqGLDgpWKXejjEKDEhqdgFu
5COwZHDhKyaaJz3m5BxRhzK0gOtK4ms4PcUkQ/8h8eraYYIPDrZKFSYbOS1/98Eesn+WD1bhsLxs
s/j5arGUYDnlulZ22TKatvunRgT4yGhtslKzh8Egh2nSIOviN6UdYwK10YH9PC8qIPRz37N4ALmb
DNUHce9es5pHYeCUdTGxRptkVjizZGY2KZeIrMxB7StWYKbrx1Tx8T131aj83csG0WMdJyi/K50n
5htuEi4fF0VeWXkF051zlBG8wJBJ8zzoTJjs0lnOX1CuUKIkkql13IX5Etmv1ysado5aw7v22AsQ
+3auSzQl9m2YS0QugyHffCGG9L4ItO+BvBBWC4WE04cB1PFztmQI0OBI6h5eB0Hy0mQP7cjgz+AJ
jQuZR/HDqGbCzOff5RtxmFzZ37w3tBAVVIncQfl5npHq6MvruxX4wRs8VNU9DLMbZQAHEpJnpHq6
MuUUF0XttFZP+fZAVTkvIRjJHWqjrhiAs7vO5yKxCjouTTvcLh5eOdvlGl9W2l9Y5v5RbvjajWKj
BJTzzTSNS/EVaWQeP2OJpOLAxznRNKmstfvpEjY4mw7l3M/PpKj2gSPUBcl2cq+TOHHcxmZ1J3QY
agC9yWvBOjfimG0QD301V7XgZSER2zGAcjz2XNfOn+3RxJh7RX88XaDLFXIvrU3L0Elm9Wn8PPXi
yzhdDyIhnxkfTcwLjHg++iIpkDEV3vl6RUPZ4Vye50uoZ6XGEU8R8ahqU8b7wvMJwbLVqu3uBfkO
cWxBJCWlIwg06bH+B+OSueEcLBAzZPTKa0/wp0uzSukj5Uq9mpZ3XKWRlXe6BULvekHBs5z7zU8F
xFLp2t+SpP6GeJIdEwVjjb0W+9C7Yo93NoefRz+5jViRLrwZx/g/gH0fYMA4ijSGkA4PzxfjrHda
xlHmAtoTBQUas72Lzv2RLUvVw1XJNb+Jm8mt50rxG+RoxCc6avZbCcoFn0qZxfKII2NEzBz7WvhW
xazOcQEo1yFrbiJyGLe3xC6/OKJ27cRn4lPugp9iz+nHRTudH8/rrD6vfqoEKGadl7RuukERbiTt
FJqSPPhfnsCCgEHEX/h0zaP7AdQ4wW+ZhDc4ep8eZO19IZYkZeCxUTfrZCqsbmboJ6+Y2PaSMhJ9
/958Ix9RBxzPGVGF0j1LZ1PF+csBzXPotuP2LDHZeL1GJgJKAnrYU8SowVSMDdzL5MMUvxiDHjn0
c6ah1Lu4Ackc/QzNHhu5M6UGjoU2DRotQgD0hp0v6lf3qZR8u9PJ2iIezG0fG0G5ezyBIJ5IMSTQ
cUYF+aQ5dioRwhZmYSa87IHObbZMDh16885RBpY3yev9TKc2DWucaRD/KX/uEVLqAP8ySrP89Ce6
sHJVac2seeuOgNOMoRCooJ8VhyiPYzYpE89cZafeXQXBe5EuISD3HgUC7qAsM8qwRNyQ3mgbmiea
3GIzkuhMUZNzFG6brxs6/9nsJlGYePuzwLoFoPv/9yNs5X8Cs3Fr1tlwCWbwZalc+8oTH+8dUuOY
r6E2ahyNr2BU8XuQ9MtmM/8LzihasKDT45QJ2viBOebg1oSUEuBaH969DP76FGanNCPaLAu2KFwC
Egt8aEt5L7rYmaIiOfxdp5jRxnDp6LbLfrcoKMNQi2EgOrJnnu+DRIwCD0T0bpne+Tc3DCHkbJyB
LbiTOuoz2bLEUqinoCuX2C1ANYJkjlqD2X6IiKpscLNxbPbWc44aS6aW9tAjOaVeEXbd/PaiGlwC
5nnHKnxpp7BzE+3yVcN8iniPhFiD7HlA9Ymxfwv6GNwLC4vFgWYOGZLsJKf4e+xEFl5F/QiFH4m3
kJ5fKqpmmCNN1q69KlB2zQqeWUC+gjSI5nDpH2M3AkIXpoBZxt5rlIuX33k91Ang3mO7mtaJtezT
cceVf2ZZZRse8cW/oX3e3f0zTSXoLZzu7WZOgvW/rOKGo+Ge5vnWreTIgvHHjrWxJ8vkeLkF9M3M
fBVC6NQ1QrLiPTydazpN3Fc1J/AgCtZzjhp0kRqzhIZzSrwhv8gF82BITK9dzwabCZCe86mk2ePb
6AZHDwXCm7MjrdzETyW4Rj1VATzn0mxXMfGhNc0Sxi2oiSdR7wc4szBfLh54aHfDn8iiWQai4k/A
dV90AAADAAADAvsAAAKLQZojbEM//p4QAOIpDkAcned+1+8HYwYz5fwA5hznSNp5+b14Oy7Lnyjj
Zq/y1dcPhu1O/zDfAdgClC4E+CS1HJI6V/G+B0/+KJbmESoNza4bv+mvJ4UQhqy0x/tMKkoWpB4K
dpkjjjx2OjloiXWDntFYhbSkDcfXFvugRCGuwSYp+7MeoHreLMraI2/F8I5/Dq4XgwJPYVyfggzI
ElyWoIXQf99Vd/PwEdetwSfu4ADeUTd958+2GI/1VI5UBq1nP+LW5g60HWdq7D3aktLFcuCvp4IG
hBqPT2WvM9GVrMft0k7VPrl1HIKw7QfgmLf1Ovt4i0C9lb2+ZZIHNhJg4A0ZCugx4SETAOLHD9Dq
tNFSPOrWDVog8UnALMU6I2WxQRJpPzGjP0VmELtaIO7Kw2EkitBrVxWbDwX0MS3+MOFrtV0rHiB4
75mDDbZZvqazJZTCDVbjz9NVnlFLKWv72439g3M1//4duSgFP6Nehf/D/j5pqz+H3VRQnPbKFWAL
DRDOqdYe3e5luczPgrp9MbmzNrlVIuk826qX6+Hou45wBhlX6pQfrPSQehtjczASOKGVulgAVFa+
fpJ8OHDTDvTWDrbp8uXysL7o7gTbyITS7PftNn65Fch0fGYYfHmjKH1afvBN5+oQ6KSqHEjLYO32
mDUjzP/AtTWrO7qG8VV2zh7AJU+CgTfxaEA695KlPGBusne7bky6WP2RLBwa0+2xnywRbGCxuYnz
Aj7l8UCaIY18ZkH38lNPr1iy//3Pqhghv1RDAyrJ2v8bHEdFUSCA1rxrTi+8JVaE+PthR2kHeuLD
doebMLI8sV3yS/bnOdJiBhfYcTbCvD0ZQ88kCjwitp4rFzvq9vy8AAAAmEGeQXiFfwAvxFqz2JLQ
5IjifdRACVxiAxmAcbgmsHL8IBH9yBXMM1tfiKiXWjyEkaLUWp41CdETI/w+ytyFVDAZRhciOjLW
MEXUNKmI3+R6BtUuz4+Lo2mu0gD3ygDH8VF+t2chxjzMkP8j5H0OXnyrkCvdnkUO09Ggcn71aBUT
jw2fV9DTZ/4dMUi3QWNARSP1x78TDME9AAAAgAGeYmpCfwA9hPE+LsB/T0oKqomPOyAOwACZHJWq
l7D66gz7mWK8lkxWVQ0Viuss5S0R+HXcx0H74gSYHqq74ymSm9EL4K/AvZ9DNFJkPztzKt5A1Rpj
aYuN4jWijDJdlYT43np855zD43ev36KuPub0SC0iuD7nxN1bVv+JDCPgAAACOUGaZUmoQWiZTBTw
v/6MsAGCVUV8L3ACoARgZAR9IboMuxUT63HJnn9F/pk/g5pVnp9XOtunBXF/qXM93y5xyV/4w+lX
2nCzqM23Yzpm/qxGL6IvWbSPqAlO87y6TsfHavF+xk7WF5pcudpqoiNXrgqMpkiKeidJWYZ/w8mc
LcD+N7/HB17twOJUDT6h9a4Rnn/rmjUWtmtKJ1wptZ60UYdQ8KN+vvjdS2VJFIH8YY94dRLtqH1d
B0ZMg1FCqidjgUcW5AyBHSPWk83tD07R0ylXqqD2jt5QD5d1AUWJDA/FvG04c5kqCjo4PIPLSuO4
zN+5WaW45aIJzlxTKXIOBM4cci905T+uXprCvqIgbDFP6jv9tXO97l+slPAI+P3SQhsjYtRLrtgs
WpvJGfYcvFhVmfy+ntslGXaL5sGRbXg06COF2YzXcapUujIdqnlHg8I60I55nEg/iUFIYZmQT6lM
sJZ9DX/1V51QuSgfnRdr4IKKhOZWHkhqISXpiEhtMAenJgfuIpSQxjfn9OQxcEv8VH9bVYeun97u
slzAH8IZxbWr5DsiZnEXEMxnB0sHZLF4TdYAGupnyvpVfe7oeDx+5CC92rZ1CnsyLXTayCj3g7/D
aR1z/CPYyhZqDZfHXW9R6Tje3VGhNmxtj4k2/7CalzNPF6y2mFq7Mz7JHkAnFLKxSsIKGjrfCoQp
vjuo6DkXiZYf4FtxyM91GMBCY3QrxKBcQH6OKXRGVJLqYyQv3hG3mznYsDUhAAAAtgGehGpCfwA9
hPEGW9HQqQ3i5ukC0AstgBOmxm2WDr0BIIMN2enWcVrxyiJAPYNrVrdxD88SaZuw/U3ZCLL9G8iF
JMy1apMdtpG0PYw3SdjcQf15+t9fVqMOkXnrz+XE3u8ss0bfyAtvTHEnx33FCiLj++ZCihgnjhVZ
j8x1Rr6jgk7I4NIBhcqNnlGWYg0dI/YGu26sMKHlVvdctCKQZnRoSOF9XVmoMJjxxGK5I3WW8Aki
RbK3AAABv0GahknhClJlMCF//oywAYxUhdw27VTCDygxxwAIrGvpYY1ggj8GtKTo4h6pcH3bDpTy
jLv2mAjz4jGaQXK4vKxfITkEssqTHS3AYrD9kV0GN/d4x6lbKKCPN3Kyx9ru7cY+q05uGr75cdde
Gm1J9k3dXh4ih+U0vL1OOvwpViiqWXWsBKXtMolgdegtj7bsiAbkr/qSWEiRVYNfucqFeaJIXpkp
2UxEQ2wxAso3LsL5lEmQQL9b7GL4uwpA4wK90z9HtVM/Jtgt6iWxCbgKibzdNxPoUoqFSqyzLKHX
Djcp03PJYojif68HGYVMYaa2Vg73RredTG89Y6dXgngB8M5Fq9U78JI3maOgNioAVZKwqhmxnjfT
9lXBTw74Oba+W8NJ7lkzewIvHGVtm2zF8GHFvIqXB4v7bx7kUky28LUTxHhVJ4+B7JKtjxLzMFy1
2LbKkHLWlUZdKpxphADgAoXAATRRIr57tT4amVD5ItzuJzQtU6KMyBZxwmM4Ai4ayOmJSP5Cuq97
JbKXNnH/o6ZGWzuPsyczIXRafLbQ+//R1koMz7HizokkwIrsqrvuu1MJt50TgE0KNAqTe+kbMQAA
AgpBmqdJ4Q6JlMCF//6MsAGMErjWFPkO8AFQzeX3QgdP78IhRBKzo2MQJJ9ggXKFz9TtzTVV3qzc
yYgAXdK7uefZ455mMCs9bT2ycT4pSW1sls1Fcj/xj9OwlcJXW+MtqM3D4WB7RyZCoxO3U6qQ8WoW
tjfBOnev10Xq8t/PRurua41DiAK+uHvjrb9LddVxMytV6RHwJ31YrwfNW8nQW5bC+j4WSL4EeN95
Ry5flMVS6r4z3rjaOOPoaR+NC1yjXYO2Ez5dQO+Ywfew/QnWHJUGuJGGZ4VuomobvvUc1Wx8xvYu
IxKpwUQgFuJKvhwutCxobmSU+HfHcBIdUViwizU86Zva1n1bP+oWccnYe92iKUeOz4ftmnUP5+2u
0Udbc/1ruYj1qSLZ0Z03j88SITbIg96DcQfgu4H4P5FAJYV+KxNkVLO1SxMz922aZt6mlH+pFn4N
OjKMx5YSCJ8Ncitt3CtbqOBUKAsIIhgGQJDQelZWi1GqrUTgUTcudHK/ySJ9I6nRntwMtPQU+sY2
eKenqZtu2e82ZYRgUdezlxvDBKgZ7nFS1V1P7wioMUtAX3LnLAosD2245On+KyseqqkHcC8ozA/x
ITu+2UjLTjUL729mENQyjoC6HBh1RjoOvSMLE/+tlLrZu6Pk/Oc28lpDhpwcG5gr139KFCZ5zEYN
8M84JtCyBEz9D/EAAAJLQZrISeEPJlMCGf/+nhABh2qGQALeH0m0+lmROaUzs+PZb7htKA3sEi2X
KDV3D6vPuTjugeQAEF5fMEAp/qKx8TC8ITP7k2D+nULD4nXK+O2RyKDYwF6ZQjcQc4VsWGEmI7kc
TKzO0zsZ6OQjA0K7lm4HuvUWYmijXi4ZPKhdkWzQHJ//A+wSBiHajCHYJaulf5jtNjBFt+DxEWxp
kGkz9VTQQ+oBVLR8FkRs2CR3vtIdOX2WOMENMvp3oyeru+xWXgDa6GbSEk+zGEJzEAdUB+Z64SXH
kTmDRf9fEEWeXEw85Wro7nu6aKmiv+p62+nm9WwwjdxFWeICnqWWN7SBXbT2wz1k8RrPTvpUIZAz
norSRgF4vbALVzpgX49NjT9etjA/qoDmjxR/b8xvZXzca1U4eN3YiVAVtnwWrtjG51IeXxYLin5A
X0vjbPUm3vDKex42s2yLlgSnbKbV07w1u+lxiunRIvcFr4uJPZGfM8pDzBbwV6afF6ApafTSdKm8
bJZu47p2+6GMQpjRXB/x/rpMI2IfBRfPEeVaMXTGCDkVtJaRS2GCwbwAzUYVO6tEAYW4LofkrFTG
L88l8uprRM61jL1N/ekyGAix/ESmVa2cDP3NLsDAnOQsVMljZw3sw0wutg7SCu/JOw0Qpaii61JA
/PA+otYnzwaXZTFt7XGUDMw5pUpnpI4S7GyNioBme75w/DNqjnUlz0YaH9kEYCPdalqXCZRYxWdo
lMX9y3FyH8sODz7xDgIoMXYn3qS0W+chzflRh3TABYAAAAJ7QZrpSeEPJlMCGf/+nhABifhOkNji
O47GMofYvRvXXYcMyoMol5IVw0BvvuUzXmDz6lYEGtM3wK4kdIowvJCEn2cq7VWO2ANHt0dxyrr/
+ZCoL2Wrcw5NRkshG5jFItrqho6rZDZJhSzqonOGIUxyPFRD8hfNWppcQOXmKeribudtIVF4gYAo
Dk95zfl9ZymzwyGtZUj//I0cwoHaM7oCl0i9E8/zg2ha2FGTPSjmPRh+mpyl9c/sqilkQJ3h2K1i
zXw7FuU8ZYYFDbbeDiwI0+bE7evoq5AoLDXml8TZ2Yr22wfI3St+ih49zRAOfpsEFQ5uVTUojSuA
itXRg1Qt0pL1hmGdXNfjeMKQ2DMZqGp9rmFliox9u9GO/zem4gmfVWVjjct3vfHvSOjZvF81Kn93
5irgRuHNELnkDjeqDCIRJDwT1XdL0AAo7CEoMzh/gcS/ASYd1++uSX5kTK0YRnn+2LM2dKtJNjKG
WTYgDUJdnC6A009tYa5Qj3bLcpoIravVGvweFRvEodTfhjdASYIj9bwrIIczrjXz5MPclqT1CRue
mUDrdcuxscOr7fBQpZAYVD5FUxrVvf8gAcq9EpYeXqZPpWxEuiKQi5cgKQw2tETboxZC+iWvvQGO
U/Ft1sLPLE8FfQ6+v12NCBWqsm4P+Ko8ZuWah0B23SxismBOPKBpziKqOv3M6wvlb2JObWXRtOM/
RdKHnJ5XTiOkctiaLnkDiuIqNdbiEp9kIOwmyl8z7yifBigGHr1mFYTyGwWz2KaTxw19TuDJdF2b
EoT7VaxAUsOsT1AWsiZylRbftlD4nEtIjV6mrcJ6+bjWwxwycoFBGXlfJUwAAAKMQZsKSeEPJlMC
Gf/+nhABfRXX1hSyAA/vCGmYmrOpKOLaQNY5IJ5gD0wxf1ag4jE4ON2fYg1J6HchG/fp8knFPBy6
TTRBm75Czo68g8RjLpNrgVuS2Ukqdbbej17KuisQC++Q63MMwsLb9+hen0AJLYDzmWuSePXZe6mP
RV35SoDYLwF1dnTAWGJQSAzUcyx3vjT6Kkpm780NU9l6Vhpu1MyMkhSLT9s7BW1ohTe4o1bOtgUt
ZUIuHFW267Nm0Xr4mmIXyK1p1U2OmkIEGtnnkx0bbKdqXpEchmFqy6sQQAOSk4xLCPvKz/27Kcza
sr5HYqZHJ6dffphNM7dyNZJdxGWO7w5g8+hk65g7Y4GMdViRT2KtKSo4f0qlaPoESH1jeYIJ/+b6
tCGd/1XqAUEWFsUu+mKS+bx7EPRVLhBksiw2YNlo1j/7GeEbIF0DNOKX/heHMua7aopzQ03sHk1S
J0mvQHkFhIGkfR9kUiVzzGggdthwohcXT0GcKxMNhU+/sBi1ficxx6oVAqMCzgMczAxAkudCMpBw
DjDTiX6uElGMht04erUNprI/pECwLW2Ek+lgX7iFhyBTr0zEFhhmSB5ELEcDAIXvMGrqfDloBDet
kMa6fLGJTupz2NUC6rij9dD6YbfSiSx5UeEm4KL9M1ReSJZZQ+9NZskEv1tjJ6DLOrsc9q4Hd8eh
+qXN4HAuMpYr8lfI/Bs2evYUa+/k1E2VXkRfIq4R3dpqXz+NkjmkOXdv8Jr+u7Hxxw/3+GT7d01T
oHWJ4dOierQSVFPCTDfj22dsPpRDYk25hKMy5y7Q2eujouT9GaP7hWcZlkPJvDKpWCsMF7gHTQMd
ZWHyyuC6CHRyNOHMIjMlpQAAA3BBmyxJ4Q8mUwURPDP//p4QAX/4NhFkhNw4AQnTDIcCubBu0mlY
ll7LL9zV7h5tzVUDXlbkjB4d6jGzGzrYvqgTEJl5hQ76Hv9i9SiWYnGtHL/v4QlShPModTbPSPM9
tuRCKLurm9SvN8Fs8zqK945MKEW3/Ml+UefGUMkUnj0KKtQE9ttiMI1foZkIxB0s/nxX4SSSpTrk
jV3CROiPNimIrhOVl9v0cpj8jjgBVdJ0yW23OM9johKZv++2zxzTrk8YoMbQBF8/UMZWCYioGJHs
5iond/+mcdqv2eAzXxX713SRCvw9RXgtiDSu75wKJofVn8vx5LVsK7jQPWcxEXTmw5RBpPQMQWIh
X4ZOpVA8L6bg/YfDA+hk+JtefyuxdFtAPUCX8ZABxeEYreP/MyDZQNPi/IkZ92Z4swDqAEjTpUkB
7LEMCM7z649ilFwVqa0o84hG2Y3fBn2K6ECboNeuwrUElyP1kVa3S/BVgUvKAoiWw6/N69CLyWv3
/wgxtFGJKdziP5S3aHLgBInLPEg0hAblPVky763ZY92NMAsvWCsqjidOzLnKA2BHf3gfEeAVcG1c
CbvJ2X+gKTvV5MidXPmn+6Qr8ApbuTuGdKsYsVzV0KQpA6IbUPTfv5Uw0hAxpH0jbb5l23MIahO/
j8xsa00SscDppwrJ2Pf+NH0mdO1XCzd8GJxSpOEF/XMiR+LkV5MnPrNmHJ6aUmnD/5moh495IvxI
q4lxdkVe7VdQg0JoNSP+lo5kWSVI7mqkhoDmRGdfuAZthZiFFG/ScnEmnHl9dm/rJ29trAeM3SqS
e1vCS5SbnBaqW5rzgo9z2reMNOK0n6gP71dEZY9+KxCShJpa7PybogvfhDaalyriPU1av7+1Vofi
ODkTSK/cOGjYDBvigyQj/yq5z/ClANPN97LWsNGohIX53BVuyBU7av0MlJXRV3EujKUzwRgmdlNS
6yiANlv3T1fXKj6UFPtDpRccBi8UI2SZsxTCNMYp7+0oVvnKh1ttCBzS5O6CI2y4qyfLeiBAphdi
9zBVYDr1NDqZImE1GwXWZ0XvaRa3xoeyIHFkNoTF03H81e3S8UDrE7NeYQolv04bz7hIHS4RTVUe
MW793eItNM72YBkNE5wIVw/anfUmDIsfZsIJYtOhLqeGI7znEgJjiDpK6aHgAAAA9wGfS2pCfwBm
xQ7nM/gBNJfbE7ZGZ1dSJkfWCgNtFWl9IR7PgDdxYDeGkp1qcYNWgrzxxhEV7BFb+ToE39rN+IT+
WoqNSZo3SiPQyqmm+cCFaN3CYUqugU02WA/wm4B/OOkvIekkpBc/qEcT3gt11HyZXT4lPu/xOqFn
jdKzj5LX4umjvCJCWkG9LnfyVD746iSzxKrHHs2hThF4OqblpIM/9Xws6dBM/RX1hNJngpVSZvd0
rwNhnwKqi29SyWODwAjE426dpu4plFWnQFQk3ficKfv+cTAIJuPX0OPfYbJXRHcyLcB/FBiXI7g6
ei9ApSB+CWFmK2AAAAJBQZtNSeEPJlMCGf/+nhABfbWOeVMEaIemd6IAEv+NuU9q5BU7AdG881j8
f6mIB0ZCrwKrLmY9ibxYw16soGvtrqqB/Cm3/LtfBITfKAcHiGlMY3JQxtutiOA0HMoO8r3BJiXq
8DBe7RjPlbsRdeBBidm7M1iNVoziPjKV3NOcC5RvHbIouOPZ99Tlaq6Y6ajv44D0UvvIA1e0A35p
kwx5r1j0aGH+2fg4/gNq2B9m6vw93hS3IJKNXJjd1pqPI4KDFndTqcFUPQNj/2NYuCTTIpwApQnr
tZgK2G26uiis1VWS61LZOEdSYp/rExY3J9jatsHOEdsbtkmX8zSXmNcbIb2iCv8cSmqReCZo04cP
knNAE6PGh7Zs1IgEmIxxa2Z6pM5PnPweUFejgis9zdXWB4QyMLorNsW1+Ww8YNwEb7vigVFeKmxP
YkQWE2tv5HAUkLv6nvPl6nrBaEW0x+1zpgwnu7Xjus3fUM7jNts7cpRUekFfdzSkvvWwY2Jx1oeW
3OM3dC4teYykpp3dnJp1r/h1mYCDktbZc72GIHkKrbhGARnv0GMHCP4W0NXpmGDxbuaSMZy+ixO3
bdippcb72Z6XXDvQaZAtRG9uDkucREQI7MMFCuQdFZp+krZ3MYgYPtOGFtKcVKefwb+eP5cdFhl5
2/Lhy39o1/QyzXJNmwPwFvSaTTJd5SKTaxdojgZ/ktIbYdta63nY8QRwbUXAbN8ijXLnsLJRChny
eH/EB7RXVAoLJQGWX6FPl2q2tK6DAwAAAqZBm29J4Q8mUwURPDf//qeEAF9dQLmxZD5ggAh+dX2f
fln5wrlXsmE6vyiZF4/yNbgLOpx57/hFHQaN7BjtU2HlvN1QvxRvDxe9CL4no1S5utdw+hwzbbDM
ZrFlTW1BVD6TUS0bsqx5fqn4kbl+MlACwv4vIjBCwVljzgREkTICnFXOjusAuOxuMSHBQnbNo2yt
ocnV9MGGZ9XjVaaFuP75XYoIfe5GiBahLyTymCNo/fGPzHeSXipNYoymxkyC4HWr1jE5f4IGkH5e
/cZwCFCFdbxmPPseqjQNo2SyVij2AMJzg3jNGDKob8yMt+DISXV2dyss2hiIk2nGuFjzxdlM7CyX
0O7X/oFlMuE6CN0OCK1sE14aItEohbTOw3V+Yp6vGQHTNe081vFW3bs3o67Zc6jQJ2sfstwjBc3V
eY3ZC/fLrI055vDbB5Rjf+EE+l8fQSKQ4WWF9cNO4yDqWt3DLBpl7rRHfyfAo++fvpptq4y0/FGl
2yB/gemBa/SIFYLw/cPdCeRbXQbmk6HwO8A+RW6Tdrb/8x+fhUHGOOmKvBQFsu6pOQl3LmUKJ0Pf
OA+qamyTOj/x+w8NNNczhtEd0a9TpS5St/Tc+CyivWqgVfryIzplv31WB8Gd1OWtmAqw8Sy/JZhP
7G7tVc/AxAuT/E3dRZR9gKezMrewptJKVDHXYvhFkxNoh3Cpv36vjjA4WDDSK0/5tAIEMutQmblF
0pfbpC/ClI7YAFwATSYrdtKIv/w/H9ymDDPj5rt8+qwiGPEVnh0s2Ut6jrCRKSc9Z8bzoii0vfuZ
3EMJqKpFvN1zmjo5kGaqIAUN+TmzpUo/ixOzhOJdvIuZjSxP9IE25DOw9Yw9PIQGoqqetZpqemjC
IVnvmekKQwo4Wplk//T9RKts7CkAAACeAZ+OakJ/AGNSKK/+t1RFp2xABC5Yf4h7L1sNUhQJYYCB
ZtrJBIzwnu9cffhTViP9k1/bGTT65mwkoIphsiHpPuZPF1gacuixWOUyWYIBmS5oG4yG39FwDG3V
TwkcEdRcLWL2OAlT+ftgJ/dS3U2F1ESlWjkvfLGnuqzDx0CwbmJAZuwV+BrZXuKrtSGbWJ49oMtR
Ka/0T94TZEvPOrkAAAMoQZuSSeEPJlMCGf/+nhABc68Tf8IQbQA3NHGA2Tl2fXxAQWyVy2T8qR8u
tvTh9sZXdKOaaSEvNeIzih2ITmN7CcyVhoXYpGvgBvkggqwHPHS2IXhBFKyDYRrCaqr8k+qZlwGz
upjhUOLxpXqzs2/iDTDCIk9lbWPFdFqMSGz8VQtWzt2B9IZn7CCmf8/mVmTQiDaxLITdFZgv9FgV
WTK25Bs0KBA9U4T4h1vkfydEtJFLA0d8/T4H96PC+f/S7C1nFamDbe/aA4r6xhqkp4JLKUUkClGy
a3G6KMNqxBTXSxvHo2qFUkNy2hurvRhtOZSJf+/45muvsPnqIWNj2gygjDehzjH+00OvGMg3D/Mr
5JJ+zpaacNwd4zYrhK85yH4PKhZSveQz/dEOxZS3jbItkkPaqHLVEdZpWZMG7KAKqYbsI30gXH7h
PK+hF5hxpjg4FOVC/xsRa8NM8yNZ3Eo6/ktaVn4la8Bze1ozkGJ2bTGKzJsCDunBqL2Zz/3BTd1o
cJg2c/RNOxiYRlEuFFYlz6S6b0FuDddKXLEPmA6AH0pxHVeq8kToWRLDkIjop1U0yHz+zMM/v4Qw
DwE7DalurWAIvS9jwyyla0xebLmte9SBefRi/VsCLLbuDW9zHJWH/qSFh6bkQINlMdBGHzFj6MCo
ninNbE6HsHmqwjq3wL2nCQQx3r7H0+GstKe6knhl+YtMLJWt513M/3DaS7w/v6VN/WWhBmRmk/q1
e0ekj8JOAQqkP0x5dNvH8VQUJbd5Q5YD3kwd0OIAkXWoq1HaKDuC8fjYoiVmeDeb1w9RqilrTFYq
lEBchb6ismo/yN8MgSIv8G4yx8+R/lnnj6/DfN92s6SuLUXMCJNuMsVDVd+2ziJVla3ABCreVQqp
rw3OJPv0k3wAcjnN630euYuORWzxIde0DR5eb68VfRqaKrGYaWezlYsnrpoJGh3tm4TVVU/dd0O9
4iBkZrypg8mLoNtA/w6oYRfyLxozo0sVfAgrL2YTR4so9iXhdo/RtwREyqquOEVLoDAmPUEu1iFM
m797D58ysIwVv08ARWn7iINUx4Z6A8HBVQAAAONBn7BFETwr/wBNY8QJQChDiIf48YSZ1ssyCKHL
we0Lrs4AQfWm+ETzYuOc/NV2W1RqKZYPQ8iZWQIQ/e9xQ/+tBrXJ1iDY5+KAAAAFR/fZb84Z1v7I
TG2/G2J2tJDRIwbS6M+198fNK7V6UvBD8nt9qMk0R+aVyuALh8mmG4JHwUirMqAORUQRB8Xk6Qc4
q9AQm4wMgp7Ucfl9YnOkmoQz7dQ1n6fTwl/zJ+2NFr9J0OP6DHqQpMeZ5cHqKn23EIVND8R2mK3F
KFukoSMiL4Y6Cbw82uBlJqa95FV5XqbIpKOFLQAAAJUBn9FqQn8AYYVH5G6a1210Uhc3qObPhaeK
SdwWi7qlAAdzLIYsyEvCALxaAbrzneoC516O9P3uIyTIwLmOlHG+tc2i1P+Qc1e7OLyC1wvTvT04
vIkkUpiG3iGNEiw6OaaFvEMaljwpYZlodV6VO7phl0okXKdLN7u/zjawRVTlLrcOSYXpj35Gd2EJ
y24L7M48ckAkDQAAAtBBm9RJqEFomUwU8M/+nhABbPi9B5g6JzAAiD14Kn3kie+PwPLhDMwIcbhl
7S10N6N6veootrozzZvBojdw5CF8u3NPzQ28VmGExotDSCda0w0FCgtPYet7NMTGKJ8F7hlYp7TN
PoprmCz51NO0Y+dA+xQKXiyPz/ceHzOxs2wmFJ9QTvZr0S5Q157vlTu7db5HJBkeAmgduuIHPzx6
I3NViGgD/3A4Nr24kF1jEFzWEqKsYS6nyiT3wZz/rpoGwjhsPaGHzLdld1neaY0EkkwV1KWDifoD
COZGZh6CqYUy8xMYrshiynRtryjecXFYXd86aJrMlj8uqy7rayjFGbvueLEKGj9MLPX4pFjaaCwW
TnXfb9FnWVj3Gl1F6yw6/MJLtlStvNa+qFkqnMCAK29vWDT6iu1DOIA42W/BthiS1KezeGs9ZMe9
J8d7O7MsE/HeuS0Y403ygYZrQgHfFQeOjnUUh3SQSjtvKXxQQ3U9+NCYhe5KCDDCZtM7prAXxc7q
S01SSnH60y4e9srZYvFGKTlA/I92vjAZdSsnh7mcORKdC0lLjSG++WuyRxK2tElLoxIApKToavjM
3thpO4vxvmKXLUydTgsEV0yqboovuSlE7qmd490nOffxBjyIKI7Em5MByfOD/xi4gBrSywEeNNyx
ECULN33PJFhO9eaDa3DaWImW+nD49w8uOINq2/OHdK1KQ49MTpj7w7UJlMasOWps/80+yhJq8/TF
4T2v0gnzgRn012kgrbY0VKQ4iE8sGw7pel7nMF4QPGfL+k6+HWg0E7+xioe6B3bo7+rrZHdl6vsu
8ntI1da92a4CGuZw6CrBu407FJNajG5kIU2+9m0kCrEag/j6GTOflzsuB3oJfWGkXoOB1Lbhv0VT
QcXINhPZtwGNZ9ZOAHDRwbrOAQbB8YbanQvBE+vsYie65WoIj5g8WZ1d2tOwvn9A3oAAAAC0AZ/z
akJ/AGH71UBAVUW3zIlhzhWgAhSk+khcp6l27btwA7BM1xcoABpIBtwvLdiBeanEPlAefZBjJGvC
TpRH9B0DDHvs4pjdxz6JLsv4INxP4SRchsJK8Pv6YBnhMqgxqfSY0fc5VcK2rc7XuKHAAAADAXEl
a99KNVCc5aD65wyyIt4IsqnJyPkDQKEM4UFQ1QSoKdjBy8nxLbsCmxkV4DyFMiANX04dw25hk6TM
uCRAxUwIAAACK0Gb9UnhClJlMCGf/p4QAWJPZXcKwAfQEx5FJtFHA6am3XiHbPG3XjZYXNwLse+M
l46inRJr8/968JQVx4v55c8kkhXvbkizUvtdxJpToH/x4O8O6LLGFAmlUNg7G/CNNKWTsw6bzk9E
sAvMCahJj9jfOXLyZtMlsVrojts3B537u+H0RFreUPza3aRId/6YxmU5uJEw3Am2v6eJPRTdGHbi
nFm55fX4lesSk+Ou47mfprY30e6iwNg3DJ3GWx4uKmODU0/7Ew8LZvnysCqJtKHuKQHfLTkpiGhZ
yQ/lxCkQ/wIZ0GffSsf9d/NCS1GceWJH+GFLnB3AoN6FEE7vg+v5fPnRekQNIjqqzrGtvloTxZC/
gB5ko+ejisHVH5jBBV93+qB7LhRqRGVLyeQX1JhBi5DJLlER9CeYN45BlGe0zQkWFx9UV5lRTDT4
/L4u/AD5zsTQlJdyJa/z1baHSMxlx5E2Lot5FweEz6uZP1Qc/c0oBtwIP3Sae9w+7dvm8ZlflgrP
egSaGPtnI/T/mAaCm8OGaDdW6ao3JIc7nPXJJB6vIKuEgkjOK1pn2Dxdwm/N53+11QZXerxNhrwD
lRHvqLbNG5mbEVby3U7TUTppZozoQbPhfvxrV467dGUTD7B2WN6VzXhwo0cO3JhyRp8CXvFiECV5
sehncYRfbVX3D8uzhbVPbgcAUxEQyBo9HT3fLcRbFEH86FAu+aqQo9Bv4pIOO0Smw2YpIQAAAtpB
mhdJ4Q6JlMFNEwz//p4QAWGuAMvQAlXYRtOxNMOWMqGiNMwpsS9Jf9ypM5hq/M1lclku4PY/kU/4
jLKBWAhnm+JdWL4eC8MccfXftkwutR4pMQx5zebMbZEIhyR29U/97pP0btMSY2qhIIVhdd5sMLOJ
dd58sMMVHT4TeCcCLIxIIpcOew6cmjhXegyt5tRl/v+PTELEVzR10eNF0C7i5ZL6cn2prEBkXbOs
qjMjouscvwBvZbHx4pAW3EhRDadIXlUBrYysQ13QQ+ZvJ9rJ3tZKEFS2bmeKTq4IjVmhL2whNW96
flq/4tgqQdigZ2wZ+Tupk23TPcuI6Na2G5DIHnGiQaN86fi92NmN9ghAbbca1spaQjs/FWz07DSP
oAOtehtXP3bH18FY4D1RtCEnM2sJIJ0Fmba/dA4WK67SlKXwUyzQgJuh6VlL+cJVnFC4EIBFed7x
D1EdBx455AddV2Bfl9KWsHZyd+DplWCLSuNZp6RDGPXoxoJ/vOiiiu8jW3uIYZ8tKBEuyZSUERUn
/2ColrUY4wwkQqz8IPsBJHbaA/e7N+zvISjjLI8vmJ3x/Hs631iPjK1YbrOCTIxbMkDPcyy47nDv
QXodPqZQfReYiAklQ/izHvnCxuDe90ZnVUoX+CvdUlpQ7x1hBPbLPLuTURp3ghg7+Dfa3gfcyQKw
+mDMPgc1q4bRT8ZgSpY4RTyyYuqjHfJ3dZ5TbGPZbDVbcVfyUH6iQH0+F7QytXczb3M6vExExMhK
oqpL58l8C+Qh3Ur1Co2YU9l7j07EDqvBeTr6t5S91zG2VGf2FvaQ0saHgToTfyKWsGcEbO7fDYfJ
w7S8wmr90/OOhTRbkdWcaqYzy2LUIfHxZCB1lG7qJib0RJlTtaw4NLuYKRjx7TqAiuFzARKrWgrr
Vvgr2pSeM2xj5MSAwnEi2PdvlZKWHAT7Bezl/JHLpGn3h/gYW1fndiupQGVAAAAAugGeNmpCfwBf
X1rLTmNKpcOb2Q+zeABtM7vPxn9B3DbUERADEDYYz5VVfH3+HqYRDH70wprjh9MGLx9GNRFmFHI8
MSRty36qfy/PBFzEVDu8wn86+Y48TbqxAohxh2a9f9ChKn8PkTValpG5tEaz0sv1YUyl4Xoxz+sV
ZQpjPQ3EXYyVFWqxFNm8gO/2yu95Kld9XbCKQcNd3tllcOUF0mmwvDhfe1qOp8jEBc4+rzk4CBje
oOm4yNd/gQAAA7dBmjpJ4Q8mUwIZ//6eEAFiBY9uuhrNE04AKf4Nrsb3Uw+jx//gyvemjemLHBYN
2bAeDwVUQpib5WsPH4wWFaLAckt7x9GNkTO3RDKnaIRiixC/9OkcGSXUO16dmeOWlpTb2QX5eTnt
Oqk7tD24aZfWrmZhdVQkwwKJv5FF3luNkb+ncpeeJWLpk5rNIQMTzF0syrqkkQ8vlemnHKAOyMWE
zNd5uC7u9Zr/LsguY/B7jZY98TMjshGLn3HQZ1LZ7MAYnOTgoVt+o9nTzwXi5lLYRxAuTWij5dG7
CnfTb+OkhbuX8W+poCWOP9TUn+Xxumah3oXG09AMdA1xDtgbU7c+xc9ojo2wl9yt8r3A60ooTuvk
jMLRoKZ88uas/3KPWuGwoGZu0P1iFXdAHVHfEkaj+lcDMfhh1DDtDIUP+6Igj5SuN15HsZB5QFDD
MvxIGqbzlnVVcE3Kn26VtFQDcuzlzQw4EzY4yKccl4d3Q4yJCaqQTwgqDXv8nJwSRchvocP4fhZi
GeXrYTqGytMFuUxBcXcp7L4z2jgDA6BPGr1u6Nc0qbj6S17RjUtqaBGMnZXVejwaRxcAXL2eeVhD
cs2ikpQg5C+bHRf8cGrhduFlVeCpGlC638LplIHojC18WG5PVgpDgFt4aqvJhLxCQZeL6+Wwr1kJ
Ichql/RI2dKyOrLbxvXwLKdbVsQt+m1faNKM9vNUnFxrWut1MfXfyni0tIqQ7jXr25/ejooA46U4
NlXFCtAm9whuQWB+msETVegvSDaMYZDo4xIyLhIGww5TzYm7NKeq1lFKSkaxtJxcoWZI3I2jm/Ah
sGajWFruL5FNz9Kw2YRMEzKRHjH2j66hMcBFh5YwgSpCCMS5NFjUCOCE3qWrCZm0dlME4sG24A8T
DgIqZdR9yWxge/b9plIROqJl0HGhFcGFIJdi7J6tLQeauYEbHepjh6rDv7v0MD05yAe+Gxd6ujWN
NLC9z0keOVchbMR3lYH8/VoqQWO5Wj08snO0oNXtuY0Hd47VNBzywVegmWQeHGKwDnJpm6JhNjrs
b/PzBsA3BV04oh4c7g9pfS91oR9P/EQSP2ct1bgcvaGHIDjs3ZhRi5sZhPG+Mso+XcSTA/a4G2nI
/iDYFw6Co/ezMVbAJVMUDy9H4AtWp98V5Pf5cBoN5AWrrrhNgbpQPxJZ8juAFOGEaaSKiAPfEbjZ
VeLm4asEqmDiY2eCkPwWo9fDIr6v/I3soa9K3ymkbNBu55y2V/mrwo5vJ3gePSDA/IEAAAEPQZ5Y
RRE8K/8ASXLM+Q74xYjG9w3QfwAfc2tlQ4GqpzE+kDiPIaoVjG6NwjICs8Qo14XjrlSf/TGfqrEH
OTO0/WM1GJ6ykZdRc453a0zqbeV+t5OKOf6BHDcVQ3PDLK1VG0TQ+yD4y374St58XvsPXhZJrx7X
vy/xXroWrw9yrEBu6s0uUsmUsZI41TPW36s+aWIIr+r0ySwRk/O8APiMphqVSmPzRJ+wEbfo60Qx
GS612kAAAAMAIeaRBSJYtrLF/0EVv5ztWdW/RtfBdrYTWW7PXeEDaDzoxWADcl1T92R1Zc0VFoKK
x9+jWN0c4QES7zluOKSALj2U7RuM4Jn5BGDMPAWpiBz5AkkqWt23oAAAANsBnnlqQn8AX5mUf61H
FTOFU0AIR1/YFuRhOqaF8UY2ljLJYwZNxou8y5QMUJ2dmz9aj/0H23IChaEZJQjwObxJ6p9azLLk
3HfWRY3TunaPmLKmuJWxOyzfW8HbIXKobxP0G1mcuyo1U2gUw0cQwcRYem9C5RhTwIe84Il84rwu
x8igHh4LgEuyLTkKZYS36mXC6/vmEiObggumzsl9a/hYmxDlWItnn1h1s2Se70RtuY1OIgIT0Yn4
nuZPmYfACYj+z1NEFkmv8/Ig8XcRnvBC/GO+uOLQ1H6tLKEAAAK8QZp8SahBaJlMFPDP/p4QAVh4
jdPST72d7GYAObUR/xBQRX5qu8pnEN6irX/cEnN40Xn3Xgtx2QyfAxos3gIX2x7yCWqA9Kl4QT0c
TWs73Nai59joGNLwxRjuniLWqAF9+iO+AV2lElSW8Yjvl2Z2IgDIDmZPKeT2QmEksadKLijnJQD/
xyNSCvXT8B89i1Ns+yQIeFWR9awYTnKtYwoEt5RQJPtG4rcTmRKkvbgicgrJcZe20QRgfnrVwHoD
h63VCdIayCEgbLmjK+u3Z4bK9vZo5t7l08/X8GtTiLhOD2Q4dTtQJrpFzx88Ofy/OTS0wg4sVPKR
zsZ67ZHQuHAmvC3sBDENpaSznbU/ph/ufUjrueyYmEY5yAKYBnMTZbPkkafQD/rulJF1Ld96lx+1
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

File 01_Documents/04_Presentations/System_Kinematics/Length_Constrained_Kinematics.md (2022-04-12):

```python
%matplotlib inline
```

```python
#Set model to freely swim
use_free_move = False
```

```python
import pynamics
from pynamics.frame import Frame
from pynamics.variable_types import Differentiable,Constant
from pynamics.system import System
from pynamics.body import Body
from pynamics.dyadic import Dyadic
from pynamics.output import Output,PointsOutput
from pynamics.output_points_3d import PointsOutput3D
from pynamics.constraint import AccelerationConstraint,KinematicConstraint
from pynamics.particle import Particle
import pynamics.integration
import numpy
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

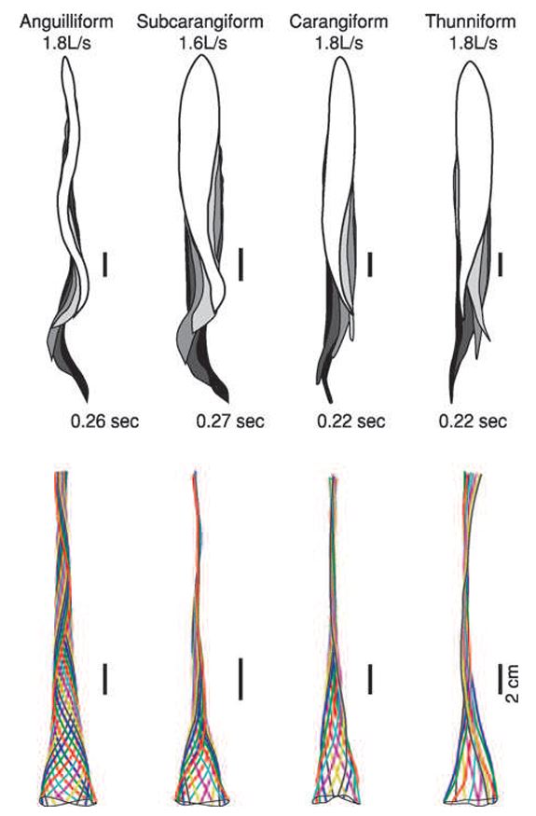
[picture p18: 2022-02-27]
01_Documents/04_Presentations/Biomechanics_Background_and_Initial_specifications/Fish_undulatory_propulsion.JPG

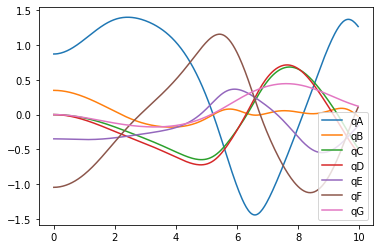
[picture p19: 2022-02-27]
01_Documents/04_Presentations/System_Kinematics/Plot_2.png

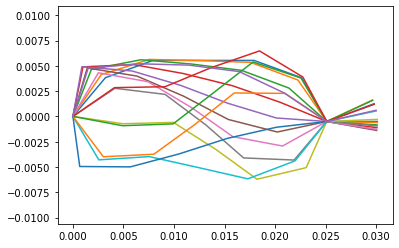
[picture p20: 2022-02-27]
01_Documents/04_Presentations/System_Kinematics/Plot_3.png

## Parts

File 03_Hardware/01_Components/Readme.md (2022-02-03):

# Add component related files here
# e.g. datasheets should go in 01_Components\##_Datasheets

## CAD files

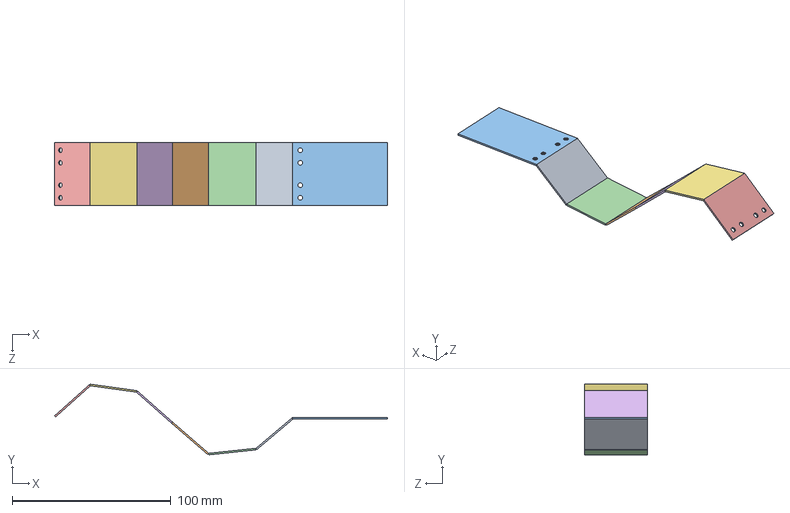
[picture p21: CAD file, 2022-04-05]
02_Mechanical/02_CAD/Solidworks Files/Full_Spine.SLDASM
210.0 x 44.6 x 40.0 mm
Thicken6
Thicken4
Thicken7
Thicken5
Thicken1
Thicken3
Thicken2

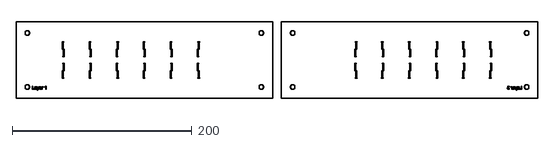
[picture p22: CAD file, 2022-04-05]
02_Mechanical/02_CAD/first_pass1.dxf
579.8 x 84.9

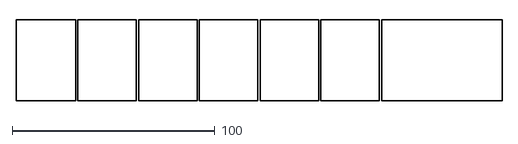
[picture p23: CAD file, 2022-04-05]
02_Mechanical/02_CAD/5_Layer1_Adhesive.dxf
240.0 x 40.0

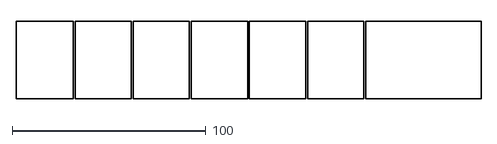
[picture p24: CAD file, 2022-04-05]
02_Mechanical/02_CAD/5_Layer3_Adhesive.dxf
240.0 x 40.0

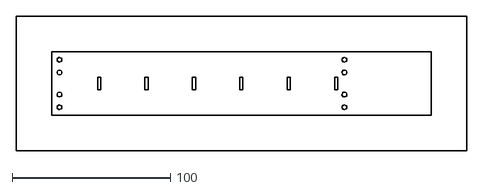
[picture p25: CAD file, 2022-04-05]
02_Mechanical/02_CAD/final_cut.dxf
284.9 x 84.9

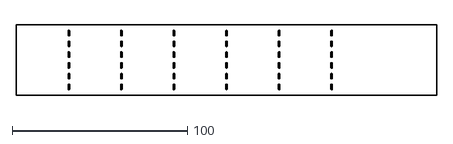
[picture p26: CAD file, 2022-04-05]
02_Mechanical/02_CAD/Single_Layer.dxf
240.0 x 40.0

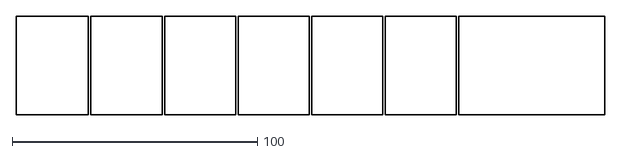
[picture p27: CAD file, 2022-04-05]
02_Mechanical/02_CAD/5_Layer0_Body.dxf
240.0 x 40.0

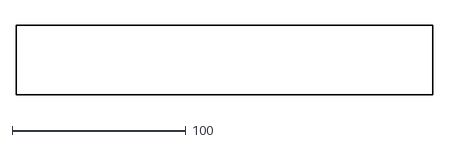
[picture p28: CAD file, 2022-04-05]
02_Mechanical/02_CAD/5_Layer2_Joint.dxf
240.0 x 40.0

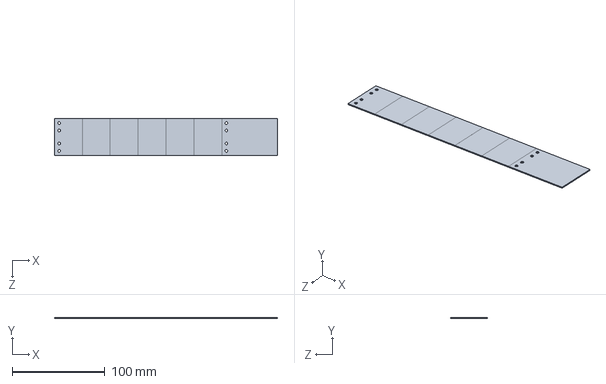
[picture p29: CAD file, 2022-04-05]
02_Mechanical/02_CAD/Solidworks Files/Ful_Spine.SLDPRT
240.0 x 1.00 x 40.0 mm

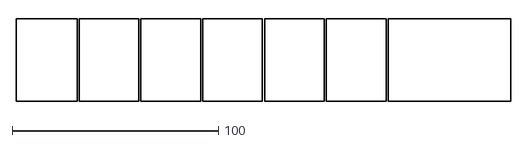
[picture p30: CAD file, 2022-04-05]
02_Mechanical/02_CAD/5_Layer4_Body.dxf
240.0 x 40.0

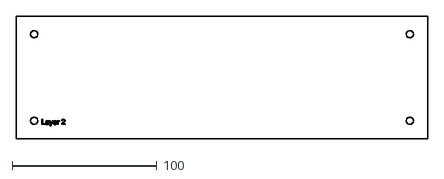
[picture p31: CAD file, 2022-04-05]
02_Mechanical/02_CAD/first_pass2.dxf
284.9 x 84.9

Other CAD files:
02_Mechanical/02_CAD/Solidworks Files/Thicken2.SLDPRT
02_Mechanical/02_CAD/Solidworks Files/Thicken4.SLDPRT
02_Mechanical/02_CAD/Solidworks Files/Thicken7.SLDPRT
02_Mechanical/02_CAD/Solidworks Files/Thicken1.SLDPRT
02_Mechanical/02_CAD/Solidworks Files/Thicken3.SLDPRT
02_Mechanical/02_CAD/Solidworks Files/Thicken5.SLDPRT
02_Mechanical/02_CAD/Solidworks Files/Thicken6.SLDPRT
02_Mechanical/02_CAD/Solidworks Files/Full_Spine.SLDDRW
02_Mechanical/02_CAD/design.dxf
02_Mechanical/02_CAD/first_pass0.dxf

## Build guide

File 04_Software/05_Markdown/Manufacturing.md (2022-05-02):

# Manufacturing

## Design and Manufacturing Workflow

#### Introduction

For manufacturing, we used a CAD model to design our final design and used a macro to convert the design into a yaml file.  After that, we used a jupyter program to add joints and create a laminate structure in a DXF file for manufacturing on a laser cutter.  From our research, we understood that we needed a stiff, waterproof material for each link and selected thin plexiglass sheets for our segment material.  However, we do not need any stiffness in the joints, so our middle sections were a flexible film.  For manufacturing, we decided to use a laser cutter to cut out the different segments held together with a heat-activated adhesive.
 
#### Code: [Design and Manufacturing Workflow](https://aniiot.github.io/Foldable_Robotics_Team_2_Swimming/02_Mechanical/02_CAD/Markdown/Design_and_Manufacturing_Workflow.html)

#### The CAD Files can be found at this GitHub link: [Segmented Tail](https://github.com/AniIOT/Foldable_Robotics_Team_2_Swimming/blob/main/02_Mechanical/02_CAD)

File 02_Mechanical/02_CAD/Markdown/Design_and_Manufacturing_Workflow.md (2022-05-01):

```python
%matplotlib inline
```

```python
import shapely.geometry as sg
from foldable_robotics.layer import Layer
from foldable_robotics.laminate import Laminate
import numpy

import foldable_robotics
import foldable_robotics.dxf 
import numpy
import shapely.geometry as sg
from foldable_robotics.layer import Layer
from foldable_robotics.laminate import Laminate
import foldable_robotics.manufacturing
import foldable_robotics.parts.castellated_hinge1
import idealab_tools.plot_tris
from math import pi, sin,cos,tan
import idealab_tools.text_to_polygons
foldable_robotics.display_height=200
foldable_robotics.line_width=.5

from foldable_robotics.layer import Layer
from foldable_robotics.laminate import Laminate
import foldable_robotics
import foldable_robotics.dxf 
import foldable_robotics.manufacturing
import foldable_robotics.parts.castellated_hinge1
foldable_robotics.display_height=200
foldable_robotics.line_width=.5
#import workflow_support as ws

import os
import foldable_robotics.solidworks_support
```

```python
def get_bodies(filename, layername, num_layers):
    body = foldable_robotics.dxf.read_lwpolylines(filename,layer=layername, arc_approx = 10)

    bodies = [Layer(sg.Polygon(item)) for item in body]
    body = bodies.pop(0)
    for item in bodies:
        body ^= item
    body = body.to_laminate(num_layers)
    return body
```

```python
def get_hinge_lines(filename,layername):
    hinge_lines1 = foldable_robotics.dxf.read_lines(filename,layer=layername)
    hinge_lines2 = foldable_robotics.dxf.read_lwpolylines(filename,layer=layername)
    hinge_lines3 = []
    for points in hinge_lines2:
        hinge_lines3.append(points[:2])
    hinge_lines = hinge_lines1 +hinge_lines3
    return hinge_lines
```

```python
def hinge_lines_to_hinges(hinge_lines,hinge):
    lam = Layer().to_laminate(len(hinge))
    all_hinges = []    
    for p3,p4 in hinge_lines:
        all_hinges.append(hinge.map_line_stretch((0,0),(1,0),p3,p4))
    all_hinges = lam.unary_union(*all_hinges)
    return all_hinges
```

```python
def get_cuts(filename,layername,thickness,num_layers):
    cut_lines = foldable_robotics.dxf.read_lines(filename,layer=layername)
    cut_lines += foldable_robotics.dxf.read_lwpolylines(filename,layer=layername, arc_approx = 10)
    
    cuts = []
    for item in cut_lines:
        cuts.append(Layer(sg.LineString(item)))
    cuts = Layer().unary_union(*cuts)
    cuts<<=thickness/2
    cuts = cuts.to_laminate(num_layers)
    return cuts
```

```python
def get_holes(filename, layername,num_layers):
    holes = foldable_robotics.dxf.read_circles(filename,layer='holes')
    
    holes2 = []
    for center, radius in holes:
        holes2.append(sg.Point(*center).buffer(radius))
    holes_layer = Layer(*holes2)
    holes_lam = holes_layer.to_laminate(num_layers)  
    return holes_lam
```

```python
def hinge_width_calculator(desired_degrees,thickness):
    theta = (180-desired_degrees)*pi/180
    w=thickness/tan(theta)
    return w
```

```python
def polys_to_layer(l1):
    l1 = [sg.Polygon(item) for item in l1]
    l11 = Layer(l1.pop(0))
    for item in l1:
        l11 ^= Layer(item)
    return l11
```

```python
def output_pdf(filename,design2,x,y,layers_separate = True):
    design2 = design2.translate(x,y)
    design2=design2.scale(1/25.4,1/25.4)
    design2=design2.scale(foldable_robotics.pdf.ppi,foldable_robotics.pdf.ppi)
    if isinstance(design2,Laminate):
        if not layers_separate:
            p=foldable_robotics.pdf.Page(filename+'.pdf')
            for d in design2:
    #        d = design2[0]
                for item in d.exteriors()+d.interiors():
                    p.draw_poly(item)
            p.close()
        else:
            for ii,d in enumerate(design2):
                p=foldable_robotics.pdf.Page(filename+'{0:03f}.pdf'.format(ii))
                for item in d.exteriors()+d.interiors():
                    p.draw_poly(item)
                p.close()

    elif isinstance(design2,Layer):
        p=foldable_robotics.pdf.Page(filename+'.pdf')
        for item in design2.exteriors()+design2.interiors():
            p.draw_poly(item)
        p.close()
```

```python
def build_layer_numbers(num_layers, text_size = None, prop=None):
    text_size = text_size or 1
    prop = prop or {'family':'Arial','size':text_size}
    layer_ids = []
    for ii in range(num_layers): 
    
        l = idealab_tools.text_to_polygons.text_to_polygons('Layer '+str(ii),prop=prop)
        layer_ids.append(l)
    
    layer_ids = [polys_to_layer(item) for item in layer_ids]
    layer_id = Laminate(*layer_ids)
    return layer_id
```

```python
def build_web(design2,keepout,support_width,jig_diameter,jig_hole_spacing,is_adhesive):
    num_layers = len(design2)

    layer_id = build_layer_numbers(num_layers,text_size=jig_diameter)

    design_outer = foldable_robotics.manufacturing.unary_union(design2)
    bb1= (design_outer<<jig_hole_spacing/2).bounding_box()
    (x1,y1),p2 = bb1.bounding_box_coords()
    w,h = bb1.get_dimensions()
    w2 = round(w/jig_hole_spacing)*jig_hole_spacing
    h2 = round(h/jig_hole_spacing)*jig_hole_spacing
    
    points = []
    points.append(sg.Point(x1,y1))
    points.append(sg.Point(x1+w2,y1))
    points.append(sg.Point(x1,y1+h2))
    points.append(sg.Point(x1+w2,y1+h2))
    
    layer_id = layer_id.translate(x1+jig_diameter,y1-jig_diameter/2)
    placement_holes2 = Layer(*points)
    placement_holes2<<=(jig_diameter/2)
    sheet = (placement_holes2<<10).bounding_box()
    placement_holes2=placement_holes2.to_laminate(num_layers)
    sheet=sheet.to_laminate(num_layers)
    
    removable_scrap = calculate_removable_scrap(design2,sheet,support_width,is_adhesive)
    
    web = (removable_scrap-placement_holes2)-layer_id
    return web,sheet
```

```python
def calculate_removable_scrap(design,sheet,width,is_adhesive):
    '''this computes all removable scrap given a sheet, a design, and a clearance width'''
    all_scrap = sheet-design

    ru = foldable_robotics.manufacturing.not_removable_up(design,is_adhesive)
    rd = foldable_robotics.manufacturing.not_removable_down(design,is_adhesive)
    
    removable_scrap_up = all_scrap-(ru<<width)
    removable_scrap_down = all_scrap-(rd<<width)

    removable_scrap = removable_scrap_up|removable_scrap_down
    return removable_scrap
```

```python
user_path = os.path.abspath(os.path.expanduser('~'))
user_path
```

    'C:\\Users\\aakwa'

# 1 Layer Robot

```python
l = 240
h = 40
seg = 30

radius = .5
num_perforations = 6
num_segments = num_perforations*2+1
num_points = num_segments+1
a=numpy.r_[0:h:num_points*1j]
lines = []
for ii in range(int(len(a)/2)-1):
    p1 = sg.Point(a[2*ii+1]+radius,0)
    p2 = sg.Point(a[2*ii+2]-radius,0)
    lines.append(sg.LineString((p1,p2)))
hinge = Layer(*lines)
hinge<<=radius
```

```python
hinge = hinge.rotate(90)
hinge.plot()
```

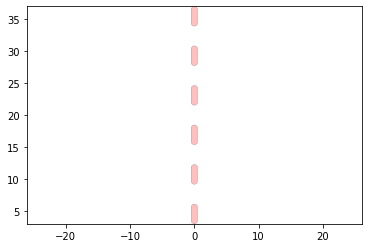
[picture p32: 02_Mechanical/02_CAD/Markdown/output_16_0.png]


```python
body = Layer(sg.Polygon([[0,0],[l,0],[l,h],[0,h]]))
body.plot()
```

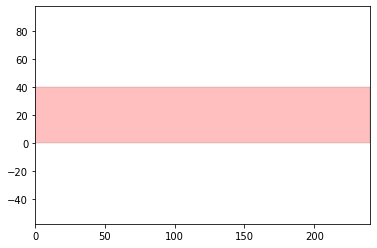
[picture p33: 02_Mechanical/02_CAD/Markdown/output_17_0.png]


```python
joint = body-hinge.translate(seg,0)-hinge.translate(seg*2,0)-hinge.translate(seg*3,0)-hinge.translate(seg*4,0)-hinge.translate(seg*5,0)-hinge.translate(seg*6,0)

joint.plot()
```

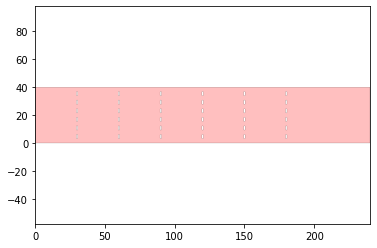
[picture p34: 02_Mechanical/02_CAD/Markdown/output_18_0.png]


```python
joint.export_dxf('Single_Layer')
```

For this design, we would use a single layer of cardstock with serrations to denote each segment of the spine. The serrations will allow for the joints to be weaker than the stiff segments. In order to manufacture this single layer robot, we only need to use a vinyl cutter to generate this pattern. This is because there are no individual components that will be floating in the design so only a vinyl cutter is necessary.

# 5 Layer Robot

```python
line = Layer(sg.LineString(((h,0),(0,0))))
line<<=radius
```

```python
line = line.rotate(90)
line.plot()
```

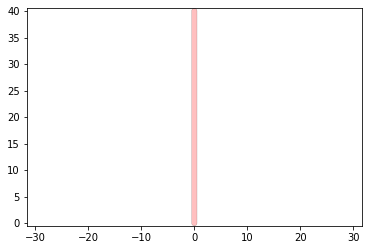
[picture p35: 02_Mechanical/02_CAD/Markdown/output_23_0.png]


```python
multilayer_hinge = Laminate(line,line,Layer(),line,line)
multilayer_body = Laminate(body,body,body,body,body)
joint5 = multilayer_body-multilayer_hinge.translate(seg*1,0)-multilayer_hinge.translate(seg*2,0)-multilayer_hinge.translate(seg*3,0)-multilayer_hinge.translate(seg*4,0)-multilayer_hinge.translate(seg*5,0)-multilayer_hinge.translate(seg*6,0)

joint5.plot_layers()
```

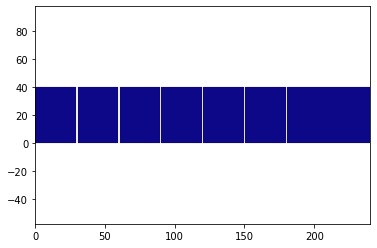
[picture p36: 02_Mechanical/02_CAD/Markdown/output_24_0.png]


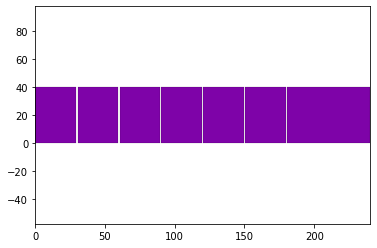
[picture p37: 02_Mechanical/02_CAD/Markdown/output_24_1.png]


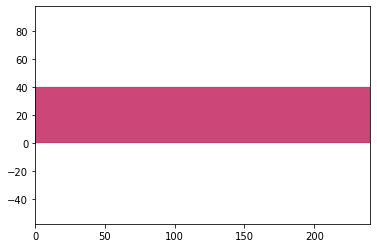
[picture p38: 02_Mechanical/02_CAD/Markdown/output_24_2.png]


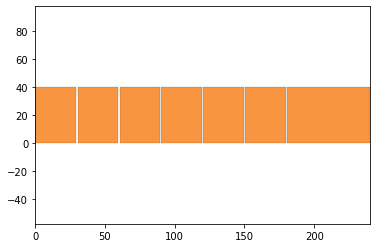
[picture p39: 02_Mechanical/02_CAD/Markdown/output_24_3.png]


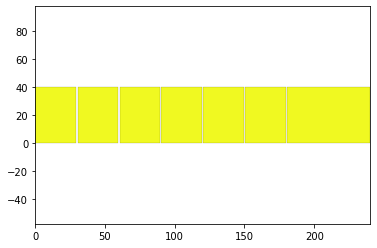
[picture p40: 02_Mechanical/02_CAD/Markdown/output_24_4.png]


```python
joint5.plot()
```

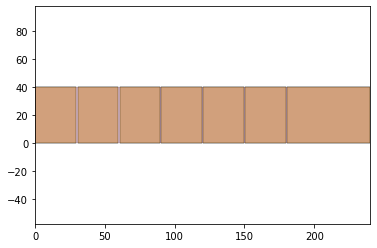
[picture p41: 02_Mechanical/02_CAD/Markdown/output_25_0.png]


```python
joint5.export_dxf('5_Layer')
```

For this design we will use a stiff material such as cardstock and for the flexible material we plan on using a polycarbonate sheet. The reason for this is because we want to have the joints very flexible and the segments relatively stiff. In order to achieve this laminate design we would need to use a laser cutter in order to get all the layers to match.

# 5-Layer Manufacturing Design

```python
folder = 'C:/Users/aakwa/Dropbox (ASU)/Term 8/EGR 557/Solidworks Model/'
input_filename = folder+'Full_Spine - Sheet1_Drawing View1.yaml'
output_file_name = 'design.dxf'
```

```python
round_digits = 5
prescale=1000
body_prebuffer=-.01
joint_tolerance = 1e-5

round_digits = 2
prescale=1000
jig_diameter = 5
support_width = 1
kerf = .05
jig_hole_spacing=20
is_adhesive = [False,True,False,True,False]
arc_approx = 10
```

```python
foldable_robotics.solidworks_support.process(input_filename,output_file_name,prescale,round_digits,body_prebuffer,joint_tolerance)
```

    (<foldable_robotics.layer.Layer at 0x254fb332d60>,
     <foldable_robotics.layer.Layer at 0x254fb65e5e0>,
     [<foldable_robotics.solidworks_support.Component at 0x254fb65e040>,
      <foldable_robotics.solidworks_support.Component at 0x254fb65e580>,
      <foldable_robotics.solidworks_support.Component at 0x254fb65e700>,
      <foldable_robotics.solidworks_support.Component at 0x254fb65e880>,
      <foldable_robotics.solidworks_support.Component at 0x254fb65e100>,
      <foldable_robotics.solidworks_support.Component at 0x254fb65e820>,
      <foldable_robotics.solidworks_support.Component at 0x254fb65e550>])

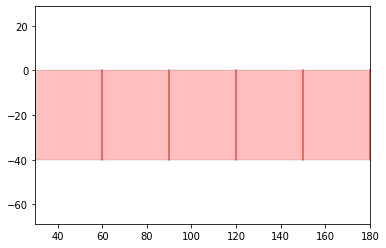
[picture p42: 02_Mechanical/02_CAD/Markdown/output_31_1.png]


```python
hinge = foldable_robotics.parts.castellated_hinge1.generate()
w=hinge_width_calculator(150,1.1)
hinge = hinge.scale(1,w)
hinge.plot()
```

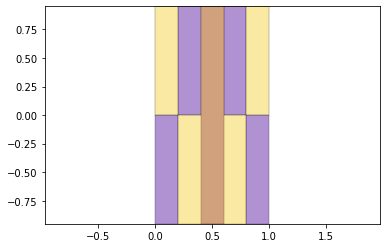
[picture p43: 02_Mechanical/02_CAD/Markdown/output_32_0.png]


```python
NUMLAYERS = len(hinge)
```

```python
body = get_bodies(output_file_name,'body',NUMLAYERS)
body = foldable_robotics.manufacturing.cleanup(body,.02)
body.plot()
```

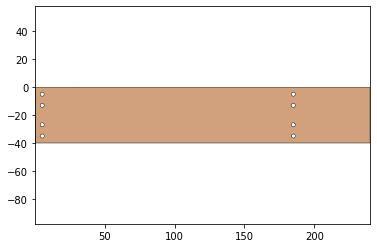
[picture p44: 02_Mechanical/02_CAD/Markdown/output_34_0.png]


```python
joint_lines= get_hinge_lines(output_file_name,'joints')
joints = hinge_lines_to_hinges(joint_lines,hinge)
joints = foldable_robotics.manufacturing.cleanup(joints,.02)
joints.plot()
```

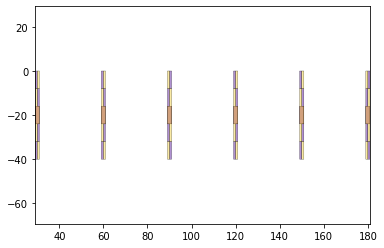
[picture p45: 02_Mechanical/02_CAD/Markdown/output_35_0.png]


```python
cuts = get_cuts(output_file_name,'cuts',.02,NUMLAYERS)
#cuts.plot()
```

```python
holes = get_holes(output_file_name,'holes',NUMLAYERS)
#holes.plot()
```

```python
hole,dummy = foldable_robotics.manufacturing.calc_hole(joint_lines,w)
hole = hole.to_laminate(NUMLAYERS)
hole<<=.2
hole.plot()
```

    ('zero-size array to reduction operation minimum which has no identity',)

    <Figure size 432x288 with 0 Axes>

```python
design2 = body- hole - joints - cuts - holes
design2.plot_layers()
```

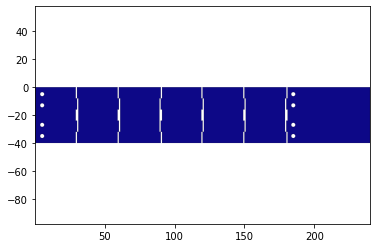
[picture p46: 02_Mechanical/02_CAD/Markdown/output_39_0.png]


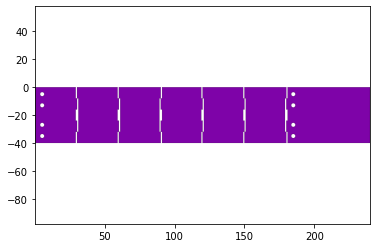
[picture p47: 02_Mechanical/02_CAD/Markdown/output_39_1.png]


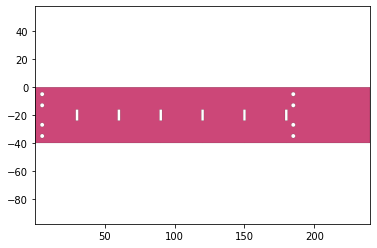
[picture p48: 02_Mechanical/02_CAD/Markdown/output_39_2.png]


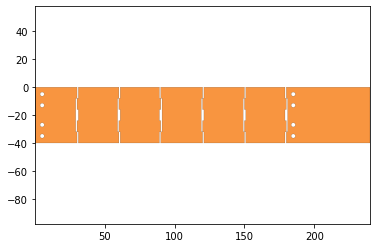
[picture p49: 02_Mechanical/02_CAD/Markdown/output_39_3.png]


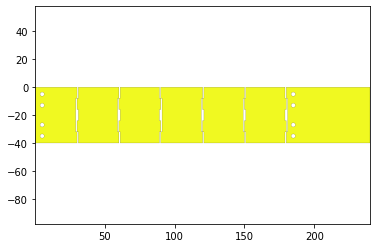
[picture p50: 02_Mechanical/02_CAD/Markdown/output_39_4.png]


```python
keepout =  foldable_robotics.manufacturing.keepout_laser(design2)
keepout.plot()
```

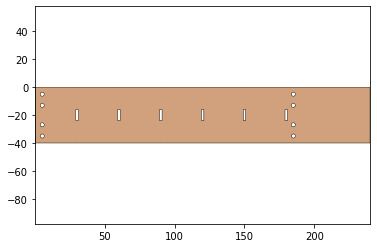
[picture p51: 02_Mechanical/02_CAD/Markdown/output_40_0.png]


```python
web,sheet=build_web(design2,keepout,support_width,jig_diameter,jig_hole_spacing,is_adhesive)
web.plot()
```

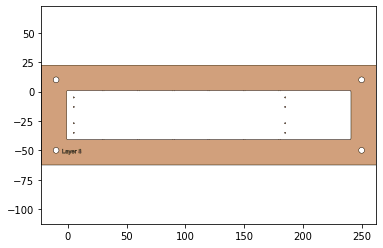
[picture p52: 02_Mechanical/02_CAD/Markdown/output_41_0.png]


```python
sheet.plot()
```

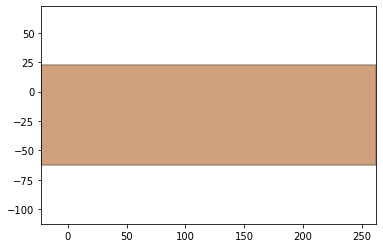
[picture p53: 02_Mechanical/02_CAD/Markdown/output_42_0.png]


```python
second_pass_scrap = sheet-keepout
first_pass_scrap = sheet - design2-second_pass_scrap
first_pass_scrap = foldable_robotics.manufacturing.cleanup(first_pass_scrap,.00001)
first_pass_scrap.plot()
```

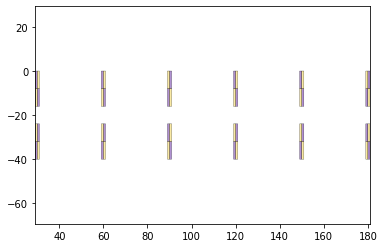
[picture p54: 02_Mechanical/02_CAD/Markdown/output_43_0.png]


```python
support = foldable_robotics.manufacturing.support(design2,foldable_robotics.manufacturing.keepout_laser,support_width,support_width/2)
support.plot()
```

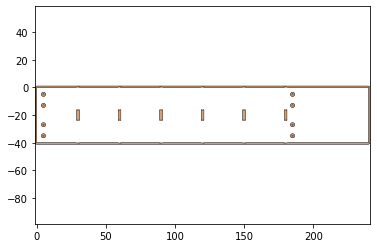
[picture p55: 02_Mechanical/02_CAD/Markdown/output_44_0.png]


```python
#Calculate the web by using only the material which can be cut, minus a gap determined by the support width.  Is that the only material you can use?
supported_design = web|design2|support
supported_design.plot()
```

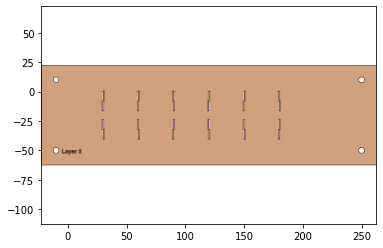
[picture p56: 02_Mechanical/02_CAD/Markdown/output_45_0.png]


```python
#cut_line = keepout<<kerf
cut_material = (keepout<<kerf)-keepout
cut_material.plot()
```

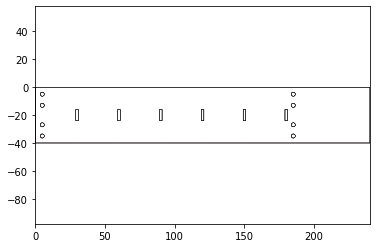
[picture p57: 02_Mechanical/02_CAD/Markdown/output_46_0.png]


```python
final_cut = sheet - keepout
final_cut = final_cut[0]
final_cut.plot()
```

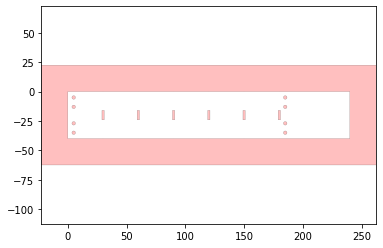
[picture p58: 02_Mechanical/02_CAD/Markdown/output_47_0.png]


```python
remaining_material = supported_design-cut_material
remaining_material.plot()
```

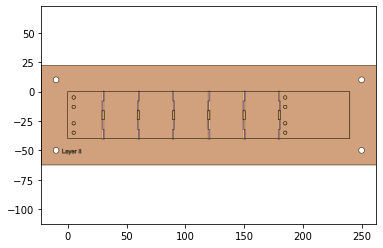
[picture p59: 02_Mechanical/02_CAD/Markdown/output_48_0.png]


```python
remaining_parts = foldable_robotics.manufacturing.find_connected(remaining_material,is_adhesive)
for item in remaining_parts:
    item.plot(new=True)
```

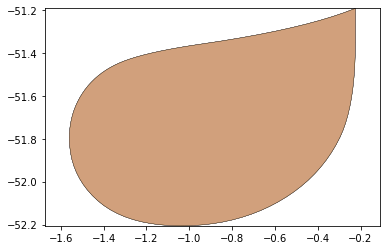
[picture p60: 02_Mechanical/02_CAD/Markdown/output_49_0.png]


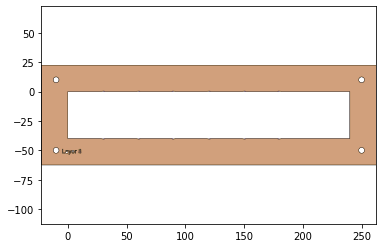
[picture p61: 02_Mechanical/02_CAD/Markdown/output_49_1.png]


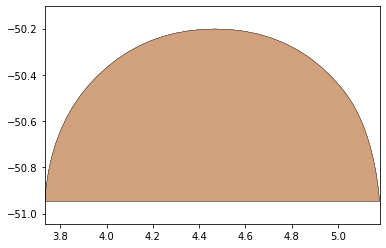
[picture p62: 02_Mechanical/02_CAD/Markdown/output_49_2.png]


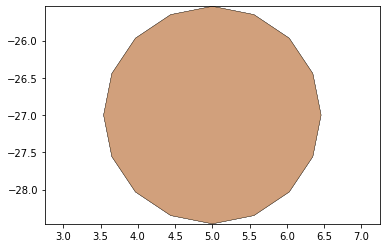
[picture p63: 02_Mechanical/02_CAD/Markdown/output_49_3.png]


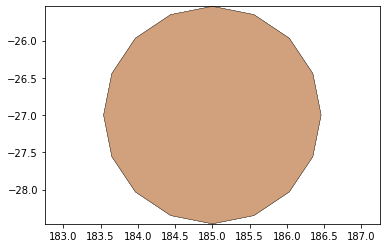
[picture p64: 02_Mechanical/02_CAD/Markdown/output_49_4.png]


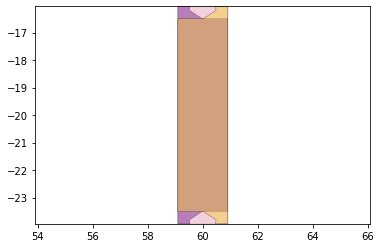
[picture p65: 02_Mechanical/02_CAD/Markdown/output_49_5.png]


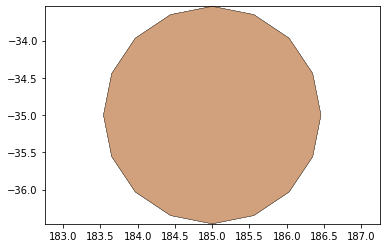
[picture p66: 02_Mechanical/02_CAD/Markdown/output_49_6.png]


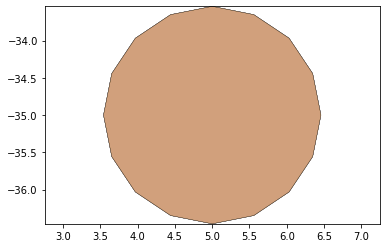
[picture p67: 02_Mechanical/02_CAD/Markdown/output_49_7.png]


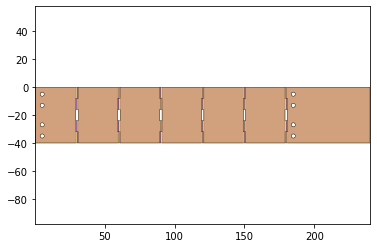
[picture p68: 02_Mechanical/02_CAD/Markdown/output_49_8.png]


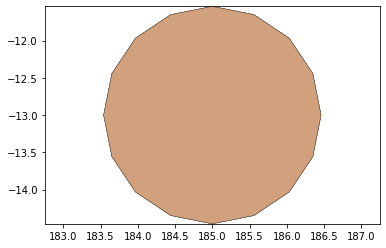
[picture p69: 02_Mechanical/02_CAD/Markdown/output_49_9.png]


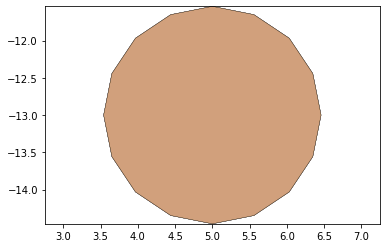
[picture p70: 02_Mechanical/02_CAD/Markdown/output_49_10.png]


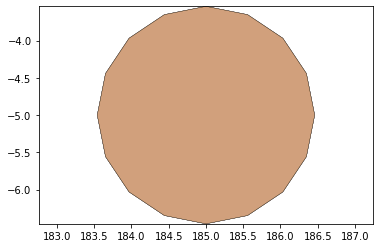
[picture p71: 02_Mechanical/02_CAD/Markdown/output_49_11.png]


png

png

png

png

png

png

```python
d3=design2>>1
for item in remaining_parts:
    if not (item&d3).is_null():
        break
item.plot()
```

png

```python
check = (item^design2)
check>>=1e-5
check.plot()
```

    ('zero-size array to reduction operation minimum which has no identity',)

```python
w,h = supported_design.get_dimensions()
p0,p1 = supported_design.bounding_box_coords()

rigid_layer = supported_design[0] | (supported_design[-1].translate(w+10,0))
rigid_layer.plot()
```

png

```python
l4 = supported_design[3].scale(-1,1)
p2,p3 = l4.bounding_box_coords()
l4 = l4.translate(p0[0]-p2[0]+10+w,p0[1]-p2[1])

adhesive_layer = supported_design[1] | l4
adhesive_layer.plot()
```

png

```python
first_pass = Laminate(rigid_layer,adhesive_layer,supported_design[2])
```

```python
if check.is_null():
    first_pass.export_dxf('first_pass')
    final_cut.export_dxf('final_cut')
```

```python

```

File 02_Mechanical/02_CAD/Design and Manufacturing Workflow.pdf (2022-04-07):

# Paper Prototypes


# Solidwork Model


# Python Script

4/5/22, 6:39 PM | Design and Manufacturing Workflow
localhost:8888/nbconvert/html/Downloads/Git/Foldable_Robotics_Project/02_Mechanical/02_CAD/Design and Manufacturing Workflow.ipynb?downl… | 1/23

In [1]:
%matplotlib inline

In [2]:
import shapely.geometry as sg
from foldable_robotics.layer import Layer from foldable_robotics.laminate import Laminate import numpy

import foldable_robotics
import foldable_robotics.dxf
import numpy
import shapely.geometry as sg
from foldable_robotics.layer import Layer
from foldable_robotics.laminate import Laminate import foldable_robotics.manufacturing
import foldable_robotics.parts.castellated_hinge1 import idealab_tools.plot_tris
from math import pi, sin,cos,tan
import idealab_tools.text_to_polygons foldable_robotics.display_height=200 foldable_robotics.line_width=.5

from foldable_robotics.layer import Layer from foldable_robotics.laminate import Laminate import foldable_robotics
import foldable_robotics.dxf
import foldable_robotics.manufacturing
import foldable_robotics.parts.castellated_hinge1 foldable_robotics.display_height=200 foldable_robotics.line_width=.5
#import workflow_support as ws

import os
import foldable_robotics.solidworks_support

In [3]:
def get_bodies(filename, layername, num_layers):
body = foldable_robotics.dxf.read_lwpolylines(filename,layer=layername, arc_approx

bodies = [Layer(sg.Polygon(item)) for item in body]
body = bodies.pop(0)
for item in bodies:
body ^= item
body = body.to_laminate(num_layers) return body

In [4]:
def get_hinge_lines(filename,layername):
hinge_lines1 = foldable_robotics.dxf.read_lines(filename,layer=layername) hinge_lines2 = foldable_robotics.dxf.read_lwpolylines(filename,layer=layername) hinge_lines3 = []
for points in hinge_lines2:
hinge_lines3.append(points[:2])
hinge_lines = hinge_lines1 +hinge_lines3 return hinge_lines localhost:8888/nbconvert/html/Downloads/Git/Foldable_Robotics_Project/02_Mechanical/02_CAD/Design and Manufacturing Workflow.ipynb?downl… 2/23 In [5]:

def hinge_lines_to_hinges(hinge_lines,hinge): lam = Layer().to_laminate(len(hinge))
all_hinges = []
for p3,p4 in hinge_lines:
all_hinges.append(hinge.map_line_stretch((0,0),(1,0),p3,p4)) all_hinges = lam.unary_union(*all_hinges)
return all_hinges

In [6]:
def get_cuts(filename,layername,thickness,num_layers):
cut_lines = foldable_robotics.dxf.read_lines(filename,layer=layername)
cut_lines += foldable_robotics.dxf.read_lwpolylines(filename,layer=layername, arc_a

cuts = []
for item in cut_lines:
cuts.append(Layer(sg.LineString(item)))
cuts = Layer().unary_union(*cuts) cuts<<=thickness/2
cuts = cuts.to_laminate(num_layers) return cuts

In [7]:
def get_holes(filename, layername,num_layers):
holes = foldable_robotics.dxf.read_circles(filename,layer='holes')

holes2 = []
for center, radius in holes: holes2.append(sg.Point(*center).buffer(radius))
holes_layer = Layer(*holes2)
holes_lam = holes_layer.to_laminate(num_layers) return holes_lam

In [8]:
def hinge_width_calculator(desired_degrees,thickness): theta = (180-desired_degrees)*pi/180 w=thickness/tan(theta)
return w

In [9]:
def polys_to_layer(l1):
l1 = [sg.Polygon(item) for item in l1] l11 = Layer(l1.pop(0))
for item in l1:
l11 ^= Layer(item)
return l11

In [10]:
def output_pdf(filename,design2,x,y,layers_separate = True):
design2 = design2.translate(x,y)
design2=design2.scale(1/25.4,1/25.4) design2=design2.scale(foldable_robotics.pdf.ppi,foldable_robotics.pdf.ppi) if isinstance(design2,Laminate):
if not layers_separate:
p=foldable_robotics.pdf.Page(filename+'.pdf') for d in design2:
# | d = design2[0]

for item in d.exteriors()+d.interiors(): p.draw_poly(item)

localhost:8888/nbconvert/html/Downloads/Git/Foldable_Robotics_Project/02_Mechanical/02_CAD/Design and Manufacturing Workflow.ipynb?downl… 3/23

p.close()
else:
for ii,d in enumerate(design2): p=foldable_robotics.pdf.Page(filename+'{0:03f}.pdf'.format(ii)) for item in d.exteriors()+d.interiors():
p.draw_poly(item)
p.close()

elif isinstance(design2,Layer): p=foldable_robotics.pdf.Page(filename+'.pdf')
for item in design2.exteriors()+design2.interiors(): p.draw_poly(item)
p.close()

In [11]:
def build_layer_numbers(num_layers, text_size = None, prop=None): text_size = text_size or 1
prop = prop or {'family':'Arial','size':text_size}
layer_ids = []
for ii in range(num_layers):

l = idealab_tools.text_to_polygons.text_to_polygons('Layer '+str(ii),prop=prop) layer_ids.append(l)

layer_ids = [polys_to_layer(item) for item in layer_ids]
layer_id = Laminate(*layer_ids)
return layer_id

In [12]:
def build_web(design2,keepout,support_width,jig_diameter,jig_hole_spacing,is_adhesive): num_layers = len(design2)

layer_id = build_layer_numbers(num_layers,text_size=jig_diameter)

design_outer = foldable_robotics.manufacturing.unary_union(design2) bb1= (design_outer<<jig_hole_spacing/2).bounding_box()
(x1,y1),p2 = bb1.bounding_box_coords()
w,h = bb1.get_dimensions()
w2 = round(w/jig_hole_spacing)*jig_hole_spacing
h2 = round(h/jig_hole_spacing)*jig_hole_spacing

points = []
points.append(sg.Point(x1,y1)) points.append(sg.Point(x1+w2,y1)) points.append(sg.Point(x1,y1+h2)) points.append(sg.Point(x1+w2,y1+h2))

layer_id = layer_id.translate(x1+jig_diameter,y1-jig_diameter/2) placement_holes2 = Layer(*points) placement_holes2<<=(jig_diameter/2)
sheet = (placement_holes2<<10).bounding_box() placement_holes2=placement_holes2.to_laminate(num_layers) sheet=sheet.to_laminate(num_layers)

removable_scrap = calculate_removable_scrap(design2,sheet,support_width,is_adhesive

web = (removable_scrap-placement_holes2)-layer_id
return web,sheet localhost:8888/nbconvert/html/Downloads/Git/Foldable_Robotics_Project/02_Mechanical/02_CAD/Design and Manufacturing Workflow.ipynb?downl… 4/23

'C:\\Users\\aakwa'

# 1 Layer Robot

In [13]:

def calculate_removable_scrap(design,sheet,width,is_adhesive):
'''this computes all removable scrap given a sheet, a design, and a clearance width all_scrap = sheet-design

ru = foldable_robotics.manufacturing.not_removable_up(design,is_adhesive)
rd = foldable_robotics.manufacturing.not_removable_down(design,is_adhesive)

removable_scrap_up = all_scrap-(ru<<width)
removable_scrap_down = all_scrap-(rd<<width)

removable_scrap = removable_scrap_up|removable_scrap_down return removable_scrap

In [14]:
user_path = os.path.abspath(os.path.expanduser('~')) user_path

Out[14]: In [68]:

l = 240
h = 40
seg = 30

radius = .5
num_perforations = 6
num_segments = num_perforations*2+1 num_points = num_segments+1 a=numpy.r_[0:h:num_points*1j]
lines = []
for ii in range(int(len(a)/2)-1):
p1 = sg.Point(a[2*ii+1]+radius,0) p2 = sg.Point(a[2*ii+2]-radius,0) lines.append(sg.LineString((p1,p2))) hinge = Layer(*lines)
hinge<<=radius

In [69]:
hinge = hinge.rotate(90)
hinge.plot()


localhost:8888/nbconvert/html/Downloads/Git/Foldable_Robotics_Project/02_Mechanical/02_CAD/Design and Manufacturing Workflow.ipynb?downl… 5/23

In [70]:
body = Layer(sg.Polygon([[0,0],[l,0],[l,h],[0,h]])) body.plot()

In [71]:
joint = body-hinge.translate(seg,0)-hinge.translate(seg*2,0)-hinge.translate(seg*3,0)-h

joint.plot()

In [72]: joint.export_dxf('Single_Layer')


localhost:8888/nbconvert/html/Downloads/Git/Foldable_Robotics_Project/02_Mechanical/02_CAD/Design and Manufacturing Workflow.ipynb?downl… 6/23

For this design, we would use a single layer of cardstock with serrations to denote each segment of the spine. The serrations will allow for the joints to be weaker than the stiff segments. In order to manufacture this single layer robot, we only need to use a vinyl cutter to generate this pattern. This is because there are no individual components that will be floating in the design so only a vinyl cutter is necessary.

# 5 Layer Robot

In [77]:
line = Layer(sg.LineString(((h,0),(0,0)))) line<<=radius

In [78]:
line = line.rotate(90)
line.plot()

In [81]:
multilayer_hinge = Laminate(line,line,Layer(),line,line)
multilayer_body = Laminate(body,body,body,body,body)
joint5 = multilayer_body-multilayer_hinge.translate(seg*1,0)-multilayer_hinge.translate

joint5.plot_layers()


localhost:8888/nbconvert/html/Downloads/Git/Foldable_Robotics_Project/02_Mechanical/02_CAD/Design and Manufacturing Workflow.ipynb?downl… 7/23


localhost:8888/nbconvert/html/Downloads/Git/Foldable_Robotics_Project/02_Mechanical/02_CAD/Design and Manufacturing Workflow.ipynb?downl… 8/23

For this design we will use a stiff material such as cardstock and for the flexible material we plan on using a polycarbonate sheet. The reason for this is because we want to have the joints very flexible and the segments relatively stiff. In order to achieve this laminate design we would need to use a laser cutter in order to get all the layers to match.

# 5-Layer Manufacturing Design

In [76]:
joint5.plot()

In [82]:
joint5.export_dxf('5_Layer')

In [23]:
folder = 'C:/Users/aakwa/Dropbox (ASU)/Term 8/EGR 557/Solidworks Model/' input_filename = folder+'Full_Spine - Sheet1_Drawing View1.yaml' output_file_name = 'design.dxf'

In [24]:
round_digits = 5
prescale=1000
body_prebuffer=-.01
joint_tolerance = 1e-5


localhost:8888/nbconvert/html/Downloads/Git/Foldable_Robotics_Project/02_Mechanical/02_CAD/Design and Manufacturing Workflow.ipynb?downl… 9/23

(<foldable_robotics.layer.Layer at 0x254fb332d60>, <foldable_robotics.layer.Layer at 0x254fb65e5e0>, [<foldable_robotics.solidworks_support.Component at 0x254fb65e040>, <foldable_robotics.solidworks_support.Component at 0x254fb65e580>, <foldable_robotics.solidworks_support.Component at 0x254fb65e700>, <foldable_robotics.solidworks_support.Component at 0x254fb65e880>, <foldable_robotics.solidworks_support.Component at 0x254fb65e100>, <foldable_robotics.solidworks_support.Component at 0x254fb65e820>, <foldable_robotics.solidworks_support.Component at 0x254fb65e550>])

round_digits = 2
prescale=1000
jig_diameter = 5
support_width = 1
kerf = .05
jig_hole_spacing=20
is_adhesive = [False,True,False,True,False]
arc_approx = 10

In [25]:
foldable_robotics.solidworks_support.process(input_filename,output_file_name,prescale,r

# Out[25]: In [26]:

hinge = foldable_robotics.parts.castellated_hinge1.generate() w=hinge_width_calculator(150,1.1)
hinge = hinge.scale(1,w)
hinge.plot()

localhost:8888/nbconvert/html/Downloads/Git/Foldable_Robotics_Project/02_Mechanical/02_CAD/Design and Manufacturing Workflow.ipynb?down… 10/23 In [27]:

NUMLAYERS = len(hinge)

In [28]:
body = get_bodies(output_file_name,'body',NUMLAYERS) body = foldable_robotics.manufacturing.cleanup(body,.02) body.plot()

In [29]:

joint_lines= get_hinge_lines(output_file_name,'joints') joints = hinge_lines_to_hinges(joint_lines,hinge)
joints = foldable_robotics.manufacturing.cleanup(joints,.02) joints.plot()

In [30]:


cuts = get_cuts(output_file_name,'cuts',.02,NUMLAYERS) #cuts.plot()

In [31]:
holes = get_holes(output_file_name,'holes',NUMLAYERS)
#holes.plot()

In [32]:
hole,dummy = foldable_robotics.manufacturing.calc_hole(joint_lines,w) hole = hole.to_laminate(NUMLAYERS)
hole<<=.2
hole.plot()


localhost:8888/nbconvert/html/Downloads/Git/Foldable_Robotics_Project/02_Mechanical/02_CAD/Design and Manufacturing Workflow.ipynb?downl… 11/23

('zero-size array to reduction operation minimum which has no identity',) <Figure size 432x288 with 0 Axes>

In [53]:
design2 = body- hole - joints - cuts - holes
design2.plot_layers()


localhost:8888/nbconvert/html/Downloads/Git/Foldable_Robotics_Project/02_Mechanical/02_CAD/Design and Manufacturing Workflow.ipynb?down… 12/23

In [34]:
keepout = foldable_robotics.manufacturing.keepout_laser(design2) keepout.plot()

In [35]:
web,sheet=build_web(design2,keepout,support_width,jig_diameter,jig_hole_spacing,is_adhe web.plot()


localhost:8888/nbconvert/html/Downloads/Git/Foldable_Robotics_Project/02_Mechanical/02_CAD/Design and Manufacturing Workflow.ipynb?down… 13/23

In [36]:
sheet.plot()

In [37]:
second_pass_scrap = sheet-keepout
first_pass_scrap = sheet - design2-second_pass_scrap
first_pass_scrap = foldable_robotics.manufacturing.cleanup(first_pass_scrap,.00001) first_pass_scrap.plot()

In [38]: support = foldable_robotics.manufacturing.support(design2,foldable_robotics.manufacturi support.plot()


localhost:8888/nbconvert/html/Downloads/Git/Foldable_Robotics_Project/02_Mechanical/02_CAD/Design and Manufacturing Workflow.ipynb?down… 14/23

In [39]:
#Calculate the web by using only the material which can be cut, minus a gap determined supported_design = web|design2|support

supported_design.plot()

In [40]:
#cut_line = keepout<<kerf

cut_material = (keepout<<kerf)-keepout cut_material.plot()

localhost:8888/nbconvert/html/Downloads/Git/Foldable_Robotics_Project/02_Mechanical/02_CAD/Design and Manufacturing Workflow.ipynb?down… 15/23 In [41]:

final_cut = sheet - keepout final_cut = final_cut[0]
final_cut.plot()

In [42]:


remaining_material = supported_design-cut_material remaining_material.plot()

In [43]:


remaining_parts = foldable_robotics.manufacturing.find_connected(remaining_material,is_ for item in remaining_parts:
item.plot(new=True)


localhost:8888/nbconvert/html/Downloads/Git/Foldable_Robotics_Project/02_Mechanical/02_CAD/Design and Manufacturing Workflow.ipynb?down… 16/23


localhost:8888/nbconvert/html/Downloads/Git/Foldable_Robotics_Project/02_Mechanical/02_CAD/Design and Manufacturing Workflow.ipynb?down… 17/23


localhost:8888/nbconvert/html/Downloads/Git/Foldable_Robotics_Project/02_Mechanical/02_CAD/Design and Manufacturing Workflow.ipynb?down… 18/23


localhost:8888/nbconvert/html/Downloads/Git/Foldable_Robotics_Project/02_Mechanical/02_CAD/Design and Manufacturing Workflow.ipynb?down… 19/23


localhost:8888/nbconvert/html/Downloads/Git/Foldable_Robotics_Project/02_Mechanical/02_CAD/Design and Manufacturing Workflow.ipynb?down… 20/23


localhost:8888/nbconvert/html/Downloads/Git/Foldable_Robotics_Project/02_Mechanical/02_CAD/Design and Manufacturing Workflow.ipynb?down… 21/23

In [44]:
d3=design2>>1
for item in remaining_parts: if not (item&d3).is_null(): break
item.plot()


localhost:8888/nbconvert/html/Downloads/Git/Foldable_Robotics_Project/02_Mechanical/02_CAD/Design and Manufacturing Workflow.ipynb?down… 22/23

('zero-size array to reduction operation minimum which has no identity',)

In [45]:
check = (item^design2)
check>>=1e-5
check.plot()

In [46]:
w,h = supported_design.get_dimensions()
p0,p1 = supported_design.bounding_box_coords()
rigid_layer = supported_design[0] | (supported_design[-1].translate(w+10,0))
rigid_layer.plot()

In [47]:
l4 = supported_design[3].scale(-1,1)
p2,p3 = l4.bounding_box_coords()
l4 = l4.translate(p0[0]-p2[0]+10+w,p0[1]-p2[1])
adhesive_layer = supported_design[1] | l4
adhesive_layer.plot()


localhost:8888/nbconvert/html/Downloads/Git/Foldable_Robotics_Project/02_Mechanical/02_CAD/Design and Manufacturing Workflow.ipynb?down… 23/23

In [48]:
first_pass = Laminate(rigid_layer,adhesive_layer,supported_design[2])

In [50]:
if check.is_null():
first_pass.export_dxf('first_pass') final_cut.export_dxf('final_cut')

In [ ]:

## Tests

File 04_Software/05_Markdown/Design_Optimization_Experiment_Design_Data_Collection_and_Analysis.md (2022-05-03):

# Design Optimization, Experiment Design, Data Collection, and Analysis

| | Anson | Aniruddha | Bryan | Jacob |
|---|---|---|---|---|
| **Topic** | **Volume of Segment vs Velocity** | **Frequency and Sweep angle vs velocity** | **Tail length vs velocity** | **Constraint link length vs velocity** |
| **Design Optimization** | x | x | x | x | 
| **Experiment Design** | x | x | x | x | 
| **Data Collection** | x | x | x | x | 
| **Data Visualization**  | x | x | x | x | 
| **Analysis** | x | x | x | x | 
| **Conclusions** | x | x | x | x | 

### 1. Volume of segment vs velocity
 - Controlled variable: Segment length, segment height, segment width
 - Performance goal: Velocity
 - Research Questions: How does the segment design affect velocity of the system? Is there a maximum segment length that can be used with the system?
 - Code: [Segment Volume Optimization](../03_Anson/Markdown/Length_Constrained_Dynamics_Optimization_Segment_Area.md)

### 2. Constraint link length vs velocity
 - Controlled variable: Constraint link length
 - Performance goal: Velocity
 - Research Questions: How does the overall length constraint affect velocity of the system? Is there a minimum constraint that can be used with the system?
 - Code: [Constraint Link Length Optimization](../01_Jacob/Markdown/Length_Constrained_Dynamics_Opimization_Not_Optimizing.md)

### 3. Frequency and Sweep Angle  vs velocity
 - Controlled variable: frequency, sweep angle
 - Performance goal: Velocity
 - Research Questions: How does the frequency and servo angle affect velocity of the system? Is there a maximum frequency that the system can handle?.
 - Code: [Frequency Optimization](../04_Aniruddha/Markdown/Frequency_optimization.md)

### 4. Tail length vs velocity
 - Controlled variable: tail link length
 - Performance goal: Velocity
 - Research Questions: How does the tail design affect velocity of the system? Is there a maximum tail length that can be used with the system?
 - Code: [Tail Length Optimization](../02_Bryan/Markdown/Tail_Optimization.md)

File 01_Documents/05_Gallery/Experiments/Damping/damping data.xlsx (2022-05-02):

t | t(zero) | x | x(zero)
4.27 | 0 | -0.03812115306 | -0.03262115306
4.286666667 | 0.01666666667 | -0.03711950027 | -0.03161950027
4.303333333 | 0.03333333333 | -0.0356117382 | -0.0301117382
4.32 | 0.05 | -0.03311065929 | -0.02761065929
4.336666667 | 0.06666666667 | -0.02880294954 | -0.02330294954
4.353333333 | 0.08333333333 | -0.02421868836 | -0.01871868836
4.37 | 0.1 | -0.01922408034 | -0.01372408034
4.386666667 | 0.1166666667 | -0.01366283163 | -0.008162831631
4.403333333 | 0.1333333333 | -0.007280393874 | -0.001780393874
4.42 | 0.15 | -0.00144520119 | 0.00405479881
4.436666667 | 0.1666666667 | 0.003831201864 | 0.009331201864
4.453333333 | 0.1833333333 | 0.008415932571 | 0.01391593257
4.47 | 0.2 | 0.01188205585 | 0.01738205585
4.486666667 | 0.2166666667 | 0.01521995965 | 0.02071995965
4.503333333 | 0.2333333333 | 0.01744516444 | 0.02294516444
4.52 | 0.25 | 0.01827127765 | 0.02377127765
4.536666667 | 0.2666666667 | 0.01801548487 | 0.02351548487
4.553333333 | 0.2833333333 | 0.01703227136 | 0.02253227136
4.57 | 0.3 | 0.01466931856 | 0.02016931856
4.586666667 | 0.3166666667 | 0.01161799097 | 0.01711799097
4.603333333 | 0.3333333333 | 0.008133858488 | 0.01363385849
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

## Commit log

2022-02-16 updated kinematics and energy plots
2022-02-20 added static torques
2022-02-24 1. Added images and rendered video for system kinematics
2022-04-05 added design for manufacturing files
    [5_Layer0_Body.dxf, 5_Layer1_Adhesive.dxf, 5_Layer2_Joint.dxf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]
2022-04-09 1. Added markdown file for dynamics and related images 2. Downloaded jupyter notebook as .md and updated kinematics
2022-04-09 1. Added kinematics code .md file
2022-05-02 1. Added Gallery
    [Deflection_data.xlsx, damping data.xlsx]
2022-05-02 1. Created graphs
    [damping data.xlsx]
2022-05-02 Parameter Identification added and final prototype design files
    [Deflection_data.xlsx, damping data_cut.xlsx]
2022-05-03 minor cell changes
    [Deflection_data.xlsx]
